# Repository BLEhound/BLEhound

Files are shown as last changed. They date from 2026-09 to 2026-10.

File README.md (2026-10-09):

> **English** | [中文](README.zh-CN.md)

<div align="center">

# BLEhound

**An open, FEM-boosted Bluetooth LE sniffer on nRF54 — with synchronized multi-channel capture.**

Firmware · Wireshark host tools · open hardware

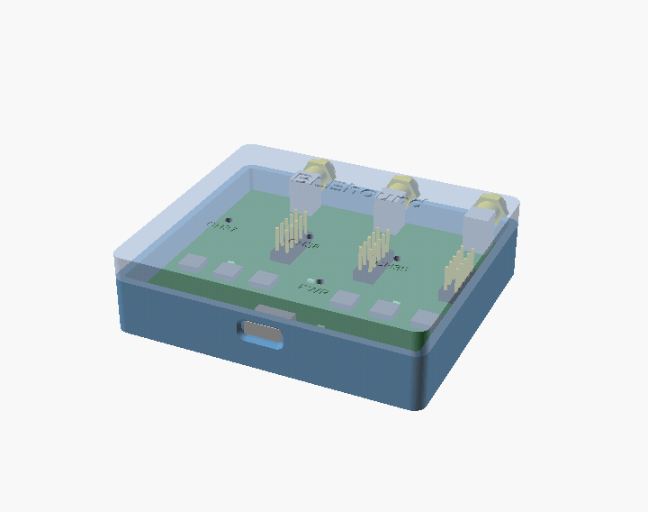
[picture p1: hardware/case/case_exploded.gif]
BLEhound — exploded view of the 3D-printed case: lid, PCB, tray


📖 Full documentation: **https://blehound.github.io**

</div>

---

BLEhound is a from-scratch BLE sniffer. The radio registers are configured by our
own firmware (not Nordic's sniffer firmware), which is what makes deep features
like connection following, encrypted-link capture, and **three-radio synchronized
multi-channel** capture possible. It ships as a complete package: firmware, a
Wireshark `extcap` plugin, and open hardware (JLCEDA Pro source, Gerbers, BOM, 3D-printed
case).

> **Built with AI.** BLEhound's hardware schematic design, and the software (firmware
> and Wireshark host tooling) development and debugging, were done entirely by AI.

## What makes it different

- **Synchronized multi-channel capture (three boards).** A single radio can only
  listen on one channel at a time, so a lone sniffer can miss a `CONNECT_IND` that
  lands on another advertising channel. BLEhound runs three boards, each guarding
  37 / 38 / 39, time-aligned over a hardware SYNC line + inter-board SPI, and merged
  by the host into **one** Wireshark interface. Validated end-to-end on real boards.
- **FEM (nRF21540 PA/LNA).** Better sensitivity and range than bare-radio sniffers.
- **New silicon, current features.** nRF54LM20A. Connection
  following with CSA #1/#2, 1M / 2M / Coded PHY with in-connection PHY updates,
  extended advertising (`AUX_CONNECT_REQ`), and BLE 5.x/6.x link-layer coverage.
- **Doubles as a low-cost BLE RF test bench.** See the docs — the same hardware can
  drive relative/golden-referenced production RF checks.

## Feature support (BLE 4.0 → 6.x)

Most mainstream link-layer features from BLE 4.0 to 6.x are covered, with an honest boundary on what any sniffer can and cannot recover:

| Feature | Status |
|---|---|
| **Advertising & connection following (BLE 4.x)** | |
| Legacy advertising capture (all PDUs) | ✓ |
| `CONNECT_IND` follow + CSA #1 hopping | ✓ |
| Channel-map update (`LL_CHANNEL_MAP_IND`) | ✓ |
| Connection-parameter update (`LL_CONNECTION_UPDATE_IND`) | ✓ |
| Peripheral latency / supervision-timeout loss detection | ✓ |
| Connection termination (`LL_TERMINATE_IND`) | ✓ |
| Encrypted-link follow (ciphertext streamed) | ✓ |
| Inject LTK → decrypt in Wireshark | ✓ |
| Legacy pairing passive crack (TK → STK) | ✓ |
| **PHY & extended advertising (BLE 5.0)** | |
| 1M PHY | ✓ |
| 2M PHY + switch (`LL_PHY_UPDATE_IND`) | ✓ |
| Coded PHY S2/S8 (auto-detect) | ✓ |
| Asymmetric PHY (per-packet within an event) | ✓ |
| CSA #2 hopping | ✓ |
| Extended-advertising AUX chains | ✓ |
| Connection via extended adv (`AUX_CONNECT_REQ`) | ✓ |
| Periodic-advertising sync (`AUX_SYNC_IND`) | ✓ |
| **LE Audio & periodic (BLE 5.1–5.4)** | |
| BIS broadcast isochronous stream | ✓ |
| CIS connected isochronous stream | ✓ |
| CIS termination (`LL_CIS_TERMINATE_IND`) | ◐ |
| Connection subrating (5.3) | ✓ |
| PAwR subevent 0 + response slots (5.4) | ✓ |
| PAwR all subevents captured | ◐ |
| PAST — periodic sync transfer | ◐ |
| **Latest features (BLE 6.0–6.2)** | |
| Frame-space negotiation (6.0) | ✓ |
| Short connection interval, down to 375 µs (6.2) | ✓ |
| Decision-based advertising filtering (6.0) | ✓ |
| Channel Sounding negotiation PDUs streamed | ✓ |
| Dedicated parsing of new 6.3 LL PDUs | ✗ |
| **Encryption & cracking boundary** | |
| Encrypted-link decryption (known LTK) | ✓ |
| LE Secure Connections key cracking | ✗ |
| Plaintext of encrypted LL control PDUs | ✗ |
| Channel Sounding ranging reconstruction | ✗ |
| RPA resolution without an IRK | ✗ |

**Legend:** ✓ verified on real hardware · ◐ code in place, hardware trigger pending · ✗ not supported / infeasible by design

## What it is honest about

- As a **single board**, it is a capable sniffer alongside the excellent
  [Sniffle](https://github.com/nccgroup/Sniffle) and the Nordic nRF Sniffer — its
  edge there is the FEM, newer silicon, and integrated hardware.
- The **multi-board redundancy** pays off on lossy/marginal links; on a clean link a
  single board already captures everything.
- The three-board relay does **not** apply to connections established via extended
  advertising (`AUX_CONNECT_REQ`), and cannot recover encrypted control PDUs (all
  boards miss the same `instant` together).

## Repository layout

| Path | What |
|---|---|
| [`firmware/`](firmware/) | Zephyr / nRF Connect SDK application (C). Build & flash: [firmware/README.md](firmware/README.md) |
| [`host/`](host/) | Wireshark `extcap` plugin + multi-channel aggregator (Python). Usage: [host/README.md](host/README.md) |
| [`hardware/`](hardware/) | Open hardware. **V1** = the fabricated board (JLCEDA Pro source + Gerbers/BOM/case); **V2** = WIP. See [hardware/README.md](hardware/README.md) — note the V1 known issues (single-board works; three-board needs rework). |
| [`tools/`](tools/) | Build / flash / RTT / extcap-install helper scripts |
| [`firmware/blehound/west.yml`](firmware/blehound/west.yml) | west manifest (self-contained; pulls NCS from official Nordic GitHub under firmware/) |

## Quick start

> **Prerequisites:** the nRF Connect SDK **v3.4.0** toolchain (`west`) and **Zephyr SDK 1.0.1**, both on PATH — on Windows install them via nRF Connect for Desktop → Toolchain Manager. A manually-unpacked SDK must be registered once; see [firmware/README.md](firmware/README.md).

```bash
# 1) Firmware — self-contained west workspace lives in firmware/
git clone https://github.com/BLEhound/BLEhound
cd BLEhound
( cd firmware && west init -l blehound && west update && west zephyr-export )
tools/build.sh                        # nRF54LM20A → build/ ; V2=1 for the revised board
tools/flash_jlink.sh                  # flash via J-Link

# 2) Host plugin
tools/install_extcap.sh               # copies the extcap into Wireshark
# then open Wireshark → interface "BLEhound Sniffer"
```

> **Windows** works too — the host tools are cross-platform. Wireshark on Windows
> needs the bundled `.bat` wrapper; see [host/README.md](host/README.md#windows).

Full walkthrough (single-board and three-board): **https://blehound.github.io**

## Licensing

- **Code** (firmware + host): [Apache-2.0](LICENSE)
- **Hardware** (schematic / PCB / Gerbers): [CERN-OHL-S-2.0](hardware/LICENSE)
- Third-party components (Zephyr, nRF Connect SDK, nrfxlib) keep their own licenses.

## Legal / ethical use

BLEhound captures radio traffic and includes legacy-pairing analysis tooling
(equivalent to `crackle`). Only use it on devices you own or are explicitly
authorized to test. Note that **LE Secure Connections (BLE 4.2+) cannot be passively
broken** — no sniffer can. See [host/security/README.md](host/security/README.md).

## Contributing

See [CONTRIBUTING.md](CONTRIBUTING.md). Issues and PRs welcome — the multi-channel
path in particular benefits from testing across more central/peripheral stacks.

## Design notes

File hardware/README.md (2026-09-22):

> **English** | [中文](README.zh-CN.md)

# BLEhound hardware

Open hardware for the BLEhound sniffer: a USB dongle around the **nRF54LM20A** SoC
with an **nRF21540** front-end module (PA/LNA) for improved range and sensitivity.
Licensed under [CERN-OHL-S-2.0](LICENSE).

## Versions

| Folder | What | Fabricate? |
|---|---|---|
| [`v1/`](v1/) | **The only fabricated board so far** (JLCEDA 0908) — Gerbers, BOM, pick-and-place, assembly, JLCEDA Pro source | ⚠️ Has known defects — three-board mode needs rework (single-board OK) |
| [`v2-wip/`](v2-wip/) | Revision that folds V1's fixes into the PCB — **routing not finished** | ❌ Do not fabricate |
| [`case/`](case/) | 3D-printed enclosure (OpenSCAD + STL + sliced 3MF) — version-independent | ✅ Shared by both |

> **Which board actually works?** A plain V1 works for **single-board sniffing only**.
> Its first batch has two pin-level defects that break the **three-board** mode. For
> working three-board hardware, **wait for the V2 revision** (not yet routed) or use a
> **reworked V1** (flying-wire fixes applied, or a modified V1 unit). Details and the
> wiring diagram: [`v1/README.md`](v1/README.md).

## Board at a glance

- **SoC:** nRF54LM20A (BLE 5.x/6.x). The firmware also runs on nRF52840.
- **Front-end:** nRF21540 FEM (PA + LNA) — better link budget than bare-radio sniffers.
- **Host:** USB CDC serial to the PC / Wireshark.
- **Multi-board:** per-board SWD header, plus a SYNC line + inter-board SPI so three
  boards can be time-aligned for synchronized multi-channel capture.

## Why two versions

The first batch (V1, 0908) was fabricated but has two pin-level defects that break the
three-board synchronized mode (single-board sniffing is fine). A plain V1 therefore is
**not** a working three-board board — it needs flying-wire rework on the debug headers
(see [`v1/README.md`](v1/README.md)). **V2** integrates those fixes directly into the
PCB so no rework is needed, but its routing is not yet complete ([`v2-wip/`](v2-wip/),
do not fabricate). **So for working three-board hardware: wait for V2, or use a
reworked V1.**

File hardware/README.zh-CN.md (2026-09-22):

> [English](README.md) | **中文**

# BLEhound 硬件

BLEhound 嗅探器的开源硬件:围绕 **nRF54LM20A** SoC + **nRF21540** 前端模块(PA/LNA,提升距离与灵敏度)的 USB dongle。许可证 [CERN-OHL-S-2.0](LICENSE)。

## 版本

| 文件夹 | 内容 | 可投产? |
|---|---|---|
| [`v1/`](v1/) | **目前唯一投产的板子**(嘉立创 0908)——Gerber、BOM、坐标、装配、嘉立创专业版源 | ⚠️ 有已知缺陷——三机模式需返工(单片可用) |
| [`v2-wip/`](v2-wip/) | 把 V1 修正做进 PCB 的改版——**布线未完成** | ❌ 不要投产 |
| [`case/`](case/) | 3D 打印外壳(OpenSCAD + STL + 切片 3MF)——与版本无关 | ✅ 两版通用 |

> **哪块板真能用?** 原始 V1 只有**单片抓包**可用。首批板有两处引脚级缺陷,会破坏**三机**模式。想要可用的三机硬件,只能**等 V2 改版**(尚未布线),或用**改过的 V1**(按飞线修正返工过、或购入已修改的 V1 单元)。详情与接线图见 [`v1/README.zh-CN.md`](v1/README.zh-CN.md)。

## 板子概览

- **SoC:** nRF54LM20A(BLE 5.x/6.x)。固件也能跑在 nRF52840 上。
- **前端:** nRF21540 FEM(PA + LNA)——链路预算优于裸电台嗅探器。
- **主机:** USB CDC 串口到 PC / Wireshark。
- **多板:** 每片 SWD 排针,外加 SYNC 线 + 片间 SPI,三片可对齐时基做同步多信道捕获。

## 为什么有两个版本

首批(V1,0908)已投产,但有两处引脚级缺陷,会破坏三机同步模式(单片抓包正常)。所以原始 V1 **不是**可用的三机板——需要在调试排针上飞线返工(见 [`v1/README.zh-CN.md`](v1/README.zh-CN.md))。**V2** 把这些修正直接做进 PCB、从而免返工,但布线尚未完成([`v2-wip/`](v2-wip/),不要投产)。**所以想要可用的三机硬件:等 V2,或用改过的 V1。**

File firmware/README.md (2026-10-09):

> **English** | [中文](README.zh-CN.md)

# BLEhound firmware

A from-scratch BLE sniffer built on the nRF Connect SDK (Zephyr). The radio is
driven directly (see `src/radio_nrf54l.c` / `src/radio_nrf52.c`) rather than using
Nordic's sniffer firmware, which is what enables connection following, encrypted
capture, and three-board synchronized multi-channel capture.

- **Targets:** nRF54LM20A (primary, with nRF21540 FEM) and nRF52840.
- **SDK:** nRF Connect SDK **v3.4.0** (pinned in `firmware/blehound/west.yml`).

## Toolchain setup (west)

```bash
# Clone the repo (its path must contain no spaces), then set up the
# self-contained workspace inside firmware/:
git clone https://github.com/BLEhound/BLEhound
cd BLEhound/firmware
west init -l blehound        # firmware/blehound/west.yml is the manifest
west update                  # pulls NCS (nrf/zephyr/...) from official Nordic GitHub, under firmware/
west zephyr-export
```

> **Windows:** get the toolchain from **nRF Connect for Desktop → Toolchain Manager**
> (install NCS v3.4.0) and run these `west` commands in its bundled command prompt —
> they are identical across macOS, Linux, and Windows.

You also need a **Zephyr SDK 1.0.1** (matches NCS v3.4.0). The nRF Connect Toolchain
Manager registers it for you; a **manually-unpacked SDK must be registered once**, with
CMake:

```bash
<sdk-dir>/setup.sh -c      # or: cmake -P <sdk-dir>/cmake/zephyr_sdk_export.cmake
```

or by exporting `ZEPHYR_SDK_INSTALL_DIR=/path/to/zephyr-sdk-1.0.1`. Without this the
build fails with *"Could not find a package configuration file provided by Zephyr-sdk"*.

> **Already have an NCS v3.4.0 workspace?** No need to re-download it — skip `west init`
> / `west update` and point the build wrapper at your existing NCS:
> `NCS_TOPDIR=/path/to/ncs tools/build.sh`.

## Build

```bash
# From firmware/. Board definitions in firmware/blehound/boards/blehound_v{1,2}/ are
# auto-discovered via blehound/zephyr/module.yml, so no -DBOARD_ROOT is needed.
west build -b blehound_v1/nrf54lm20a/cpuapp blehound/projects/blehound --sysbuild
# revised board (V2): -b blehound_v2/nrf54lm20a/cpuapp
```

Or use the convenience wrapper (auto-selects overlays and output dir):

```bash
tools/build.sh                          # nRF54LM20A dongle → build/
```

## Flash

```bash
# Recommended on the nRF54LM20A — pure J-Link (erase + program + reset; auto-unlocks APPROTECT on connect):
tools/flash_jlink.sh
SN=<jlink-serial> tools/flash_jlink.sh   # pick one when several debuggers are attached

# Alternatives via nrfutil — note it may not recognise early nRF54LM20A samples ("Unknown part 0x33"):
west flash
tools/flash.sh                 # auto-detects the J-Link and hex
RECOVER=1 tools/flash.sh       # recover (unlock APPROTECT) first
```

Each board takes the same firmware; for a three-board setup, flash all three and
connect the SWD header of whichever board you are programming.

The build is a sysbuild with three images (MCUboot + USB firmware loader + signed app,
layout in `firmware/blehound/boards/common/blehound_partitions.dtsi`). All outputs are collected with fixed
names in `build/blehound/`: `blehound_mcu_boot.*`, `blehound_loader.*`, `blehound_app.*`
(bin/hex/elf/map each), `blehound_ota.bin` / `blehound_ota.zip` (DFU upload) and
`blehound_merged.hex` (whole chip, what J-Link programs). After that, updates need no J-Link:

```bash
tools/dfu.sh /dev/cu.usbmodemXXXX      # USB DFU of one board (default: build/blehound/blehound_ota.bin)
tools/dfu.sh all                       # every board in turn
tools/verify_flash.sh <J-Link SN>      # byte-compare all three regions on the chip
```

`dfu.sh` sends `HOST_CMD_ENTER_DFU` on the capture port, the board re-enumerates as
"BLEhound Loader" (PID 0x5210) and `nrfutil mcu-manager` uploads the image over SMP.
BLEhound Analyzer has the same flow built in (device panel → "Update firmware…").

**Signing key.** MCUboot only boots images signed with the key whose public half is
compiled into it. `tools/keygen.sh` creates an ed25519 key at
`~/.blehound/keys/blehound_ed25519.pem` (outside the repo, never commit it) and exports
the public key to `firmware/blehound/projects/blehound/keys/blehound_ed25519.pub.pem`; `tools/build.sh` picks the
private key up automatically (or set `BLEHOUND_SIGNING_KEY`). Without a key the build
falls back to MCUboot's public development key and warns: fine for local debugging,
not for release. Changing the key changes MCUboot, so existing boards need one J-Link
programming of `blehound_merged.hex` before they accept images signed with the new key.

## Configuration (Kconfig)

| Option | Meaning |
|---|---|
| `SNIFFER_DEFAULT_TARGET_MAC` | Boot-time target MAC (empty = no filter). Overridden by the host once connected. Format `aa:bb:cc:dd:ee:ff`. |
| `TRI_STRATEGY_*` | Three-board follow strategy — how the boards split work after a `CONNECT_IND`. |

At runtime the host (extcap) controls channel, target MAC, single/multi-target mode,
and multi-channel relay.

## Layout

- `src/radio_*.c` — direct radio driver per SoC
- `src/conn_follower.c` — connection following (CSA #1/#2, PHY update, param update)
- `src/adv_filter.*` — advertising / target-MAC filtering
- `src/sync_line.c`, `src/peer_link.c`, `src/tri_coord.c`, `src/board_role.c` — three-board time sync and coordination
- `src/host_iface.*`, `src/cobs.*` — USB host framing (COBS)
- `src/fem_ctrl.*` — nRF21540 FEM control

> Note on comments: some source comments cite an internal design document by section
> number (e.g. "design §5.1", "scheme §4.5"). That document is not part of this
> release; each module's header comment summarizes the design it needs, so the code is
> self-contained without it.

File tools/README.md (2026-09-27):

> **English** | [中文](README.zh-CN.md)

# tools

Helper scripts for building, flashing, and debugging BLEhound.

| Script | Purpose |
|---|---|
| `build.sh` | Wrapper around `west build` (selects board target + overlays, separate output dirs) |
| `flash.sh` | Flash via modern `nrfutil` over J-Link (handles APPROTECT recovery) |
| `flash_jlink.sh` | Flash via the SEGGER J-Link tools (set `JLINK_DIR` if not at `/opt/SEGGER/JLink`) |
| `jlink_common.sh` | Shared J-Link helpers (sourced by the flash scripts) |
| `recover.sh` | Recover / unlock a locked device (APPROTECT) |
| `install_extcap.sh` | Copy the Wireshark extcap plugin into Wireshark's extcap directory |
| `rtt.sh` | Attach to SEGGER RTT for firmware logs |
| `verify_flash.sh` | Byte-compare the three on-chip regions (MCUboot / loader / app) against the build outputs |
| `keygen.sh` | Create the MCUboot signing key outside the repo (`~/.blehound/keys/`) and export its public half |
| `dfu.sh` | USB DFU without J-Link: enter the loader over the capture port, upload the signed app with `nrfutil mcu-manager`, reset |
| `cdc_test.sh` | Quick USB-CDC sanity check of the sniffer serial port |

Most scripts read overridable environment variables (`NCS_TOPDIR`,
`ZEPHYR_SDK_INSTALL_DIR`, `JLINK_DIR`, `SN`, `DEVICE`, …). Run a script with no
arguments to see its defaults, or read the header comment.

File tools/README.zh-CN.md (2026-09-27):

> [English](README.md) | **中文**

# tools

用于构建、烧录和调试 BLEhound 的辅助脚本。

| 脚本 | 用途 |
|---|---|
| `build.sh` | 对 `west build` 的封装（选择板卡目标 + overlay，输出到各自独立的目录） |
| `flash.sh` | 通过现代 `nrfutil` 经 J-Link 烧录（处理 APPROTECT 恢复） |
| `flash_jlink.sh` | 通过 SEGGER J-Link 工具烧录（若不在 `/opt/SEGGER/JLink`，设置 `JLINK_DIR`） |
| `jlink_common.sh` | 共享的 J-Link 辅助函数（被烧录脚本 source 引用） |
| `recover.sh` | 恢复 / 解锁被锁定的设备（APPROTECT） |
| `install_extcap.sh` | 把 Wireshark extcap 插件复制到 Wireshark 的 extcap 目录 |
| `rtt.sh` | 挂接 SEGGER RTT 以查看固件日志 |
| `verify_flash.sh` | 逐字节比对片上三个分区（MCUboot / 加载器 / 应用）与构建产物 |
| `keygen.sh` | 在仓库外（`~/.blehound/keys/`）生成 MCUboot 签名密钥并导出公钥 |
| `dfu.sh` | 不用 J-Link 的 USB DFU：经抓包口进加载器，用 `nrfutil mcu-manager` 上传签名应用并复位 |
| `cdc_test.sh` | 对嗅探器串口做快速的 USB-CDC 健全性检查 |

多数脚本会读取可覆盖的环境变量（`NCS_TOPDIR`、`ZEPHYR_SDK_INSTALL_DIR`、
`JLINK_DIR`、`SN`、`DEVICE`……）。不带参数运行脚本可查看其默认值，或阅读文件头部的
注释。

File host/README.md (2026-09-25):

> **English** | [中文](README.zh-CN.md)

# BLEhound host tools

Python tools that turn the sniffer's USB stream into Wireshark captures.

- `blehound_extcap.py` — the Wireshark [extcap](https://www.wireshark.org/docs/man-pages/extcap.html)
  plugin. Wireshark calls it to list interfaces/options and to stream packets.
  It opens the sniffer's USB serial port, de-frames (COBS), and writes PCAP
  (`LINKTYPE_BLUETOOTH_LE_LL_WITH_PHDR`) into the Wireshark fifo.
- `blehound_extcap.bat` — Windows wrapper: Wireshark on Windows runs `.exe`/`.bat`
  extcap programs, not `.py` directly, so this launches the plugin via Python.
- `blehound_tri_aggregator.py` — pure-logic module that time-aligns and merges three boards
  into one stream (`SyncClock` + `Aggregator` + `FollowRelay`). Runnable self-test:
  `python3 blehound_tri_aggregator.py --selftest`.
- `wireshark_dfilters` — a set of handy Wireshark display-filter bookmarks.
- `security/` — legacy-pairing analysis and decryption helpers (see its README).

## Requirements

Python 3.9+ (Wireshark uses the system `python3`; on macOS that is 3.9).

```bash
pip install -r requirements.txt      # pyserial (+ cryptography for security/)
```

## Install into Wireshark

```bash
../tools/install_extcap.sh           # copies the extcap into Wireshark's extcap dir
```

Or manually:

```bash
# Wireshark 4.x path (older <4: ~/.config/wireshark/extcap)
mkdir -p ~/.local/lib/wireshark/extcap
cp blehound_extcap.py blehound_tri_aggregator.py ~/.local/lib/wireshark/extcap/
chmod +x ~/.local/lib/wireshark/extcap/blehound_extcap.py
```

Restart Wireshark. The interface list will show **BLEhound Sniffer** (single board)
and **BLEhound Sniffer (3ch aggregated)** (three-board merged).

### Windows

Wireshark on Windows runs `.exe` / `.bat` extcap programs, not `.py` directly, so the
bundled `.bat` wrapper is required:

1. Install Python 3 (tick **Add python.exe to PATH**) and run `pip install pyserial`.
2. Find the extcap folder in Wireshark: **Help → About Wireshark → Folders → Personal
   Extcap path** (usually `%APPDATA%\Wireshark\extcap`).
3. Copy **`blehound_extcap.py`, `blehound_extcap.bat`, and `blehound_tri_aggregator.py`**
   into that folder, then restart Wireshark.

The sniffer's serial ports appear as `COMx`; everything else works the same. If
`python` is not on PATH, edit the `.bat` to use `py -3`. The `tools/*.sh` scripts are
macOS/Linux only (use Git Bash or WSL if you want them on Windows).

The USB identity the firmware advertises: VID `0x1915`, PID `0x520F`,
product string `BLEhound Sniffer`.

## Single board vs three boards

- **Single board:** pick the `BLEhound Sniffer` interface. Set the scan channel or a
  target MAC in the interface options.
- **Three boards:** pick the **BLEhound Sniffer (3ch aggregated)** interface (optionally enable the
  three-board relay). Each board guards 37 / 38 / 39; the aggregator merges and
  de-duplicates into one timeline. See the docs for wiring the SYNC line.

Filter bookmarks: load `wireshark_dfilters` entries to quickly isolate a target
device, connection data, CONNECT_IND, CRC errors, etc. Replace the example address
`aa:bb:cc:dd:ee:ff` with your device's address.

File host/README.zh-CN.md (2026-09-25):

> [English](README.md) | **中文**

# BLEhound 主机工具

一组 Python 工具，把嗅探器的 USB 数据流转换成 Wireshark 抓包。

- `blehound_extcap.py` —— Wireshark 的 [extcap](https://www.wireshark.org/docs/man-pages/extcap.html)
  插件。Wireshark 调用它来列出接口/选项并串流数据包。它会打开嗅探器的 USB 串口，
  解帧（COBS），并把 PCAP（`LINKTYPE_BLUETOOTH_LE_LL_WITH_PHDR`）写入 Wireshark 的
  fifo。
- `blehound_extcap.bat` —— Windows 包装器:Windows 上 Wireshark 只跑 `.exe`/`.bat`,
  不直接跑 `.py`,所以由它用 Python 启动插件。
- `blehound_tri_aggregator.py` —— 纯逻辑模块，把三块板做时间对齐并合并成单一数据流
  （`SyncClock` + `Aggregator` + `FollowRelay`）。可运行自测：
  `python3 blehound_tri_aggregator.py --selftest`。
- `wireshark_dfilters` —— 一组好用的 Wireshark 显示过滤器书签。
- `security/` —— 传统配对（legacy-pairing）分析与解密辅助工具（见其 README）。

## 环境要求

Python 3.9+（Wireshark 使用系统的 `python3`；在 macOS 上即 3.9）。

```bash
pip install -r requirements.txt      # pyserial (+ cryptography for security/)
```

## 安装到 Wireshark

```bash
../tools/install_extcap.sh           # copies the extcap into Wireshark's extcap dir
```

或手动安装：

```bash
# Wireshark 4.x 路径(旧版 <4:~/.config/wireshark/extcap)
mkdir -p ~/.local/lib/wireshark/extcap
cp blehound_extcap.py blehound_tri_aggregator.py ~/.local/lib/wireshark/extcap/
chmod +x ~/.local/lib/wireshark/extcap/blehound_extcap.py
```

重启 Wireshark。接口列表中会出现 **BLEhound Sniffer**（单板）和
**BLEhound Sniffer (3ch aggregated)**(三板合并)。

### Windows

Windows 上 Wireshark 只执行 `.exe` / `.bat` 形式的 extcap,不直接跑 `.py`,所以必须用随附的 `.bat` 包装器:

1. 装 Python 3(勾选 **Add python.exe to PATH**),执行 `pip install pyserial`。
2. 在 Wireshark 里找 extcap 目录:**帮助 → 关于 Wireshark → 文件夹 → Personal Extcap path**(通常是 `%APPDATA%\Wireshark\extcap`)。
3. 把 **`blehound_extcap.py`、`blehound_extcap.bat`、`blehound_tri_aggregator.py`** 三个文件复制进该目录,重启 Wireshark。

嗅探器的串口在 Windows 上显示为 `COMx`,其余用法完全相同。若 `python` 不在 PATH,把 `.bat` 里的 `python` 改成 `py -3`。`tools/*.sh` 脚本仅限 macOS/Linux(Windows 上想用可走 Git Bash / WSL)。

固件对外声明的 USB 标识：VID `0x1915`、PID `0x520F`，产品字符串
`BLEhound Sniffer`。

## 单板 vs 三板

- **单板：** 选择 `BLEhound Sniffer` 接口。在接口选项里设置扫描信道或目标 MAC。
- **三板：** 选择 **BLEhound Sniffer (3ch aggregated)** 接口（可选启用三板接力）。每块板把守
  37 / 38 / 39；聚合器会合并并去重成单一时间线。SYNC 线的接线方式见文档。

过滤器书签：加载 `wireshark_dfilters` 中的条目，可快速隔离出目标设备、连接数据、
CONNECT_IND、CRC 错误等。把示例地址 `aa:bb:cc:dd:ee:ff` 替换为你设备的地址。

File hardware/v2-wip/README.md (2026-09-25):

> **English** | [中文](README.zh-CN.md)

# BLEhound hardware — V2 (work in progress, DO NOT fabricate)

⚠️ **This is an unfinished revision — routing is incomplete. Do not fabricate it.**
V2 is the *fix* for V1's pin-level defects; until it is finished, working three-board
hardware means a **reworked V1** (flying-wire fixes applied) — see
[`../v1/README.md`](../v1/README.md). A plain V1 works for single-board sniffing only.

## What V2 changes (vs V1)

V2 folds V1's fixes directly onto the PCB, so **no flying wires are needed**. For SYNC
and the straps the firmware pin targets are unchanged — V1 reaches them by flying wire,
V2 by native routing. Concretely:

| Signal | V1 (0908, as fabricated) | V2 | Why |
|---|---|---|---|
| **SYNC** in / out | P2.01, one shared net — **no GPIOTE**, edge capture fails; reached by flywire | **P0.04** (in) / **P0.03** (out), routed on the PCB | P2 has no GPIOTE; capture must live on a P0/P1 pin |
| **Role straps** | mis-wired (roles A/C collide, no board guards ch37); reached by flywire | **P1.08** (strap0) / **P1.09** (strap1), routed on the PCB | match `board_role.c`, GPIOTE-capable |
| **Inter-chip SPI** (SPIM00) | SCK=P2.02, MOSI=P2.03, MISO=P2.04 — **not** the SPIM00 fixed pins | SCK=**P2.01**, MOSI=P2.02, MISO=P2.04 (the dedicated SPIM00 pins) | SPIM00's fixed SCK is P2.01, which V1 had used for SYNC; freed once SYNC moved off it |
| **FEM SPI** (nRF21540) | CSN=P0.06, SCK=P0.07, MOSI=P0.08, MISO=P0.09 | CSN=**P1.19**, SCK=**P1.24**, MOSI=**P1.21**, MISO=**P1.20** (all on P1) | datasheet same-port rule + NCS PERI-domain `spi2x` needs CS on P1; also clears the early-sample P0.09 hazard |
| **FEM MODE / ANT_SEL** | MODE=P1.20, ANT_SEL=P1.19 | MODE=**P0.08**, ANT_SEL=**P0.06** (P0.07 freed) | follows the FEM SPI move |
| **FEM TX_EN / RX_EN / PDN** | P1.15 / P1.16 / P1.18 | unchanged | — |
| **USB hub power** (CH334F PSELF) | bus-powered, PSELF (pin 18) floating | **self-powered** (PSELF-SEL net + local 3V3 from U8 AP2112K) | three SoCs + three FEMs exceed the 100 mA bus-power default |

The SYNC/strap **firmware** pins live in `boards/common/blehound_nrf54lm20a_cpuapp_common.dtsi` (shared by both
boards). The SPIM00 and FEM moves are the `boards/blehound_v2/` board definition
(build with `tools/build.sh V2=1`).

**Status: routing NOT complete.** The schematic carries the V2 changes, but the PCB
has not been re-routed for them. The physical layout is still the V1 (0908) layout;
several nets (SYNC, straps, MISO, hub PSELF) are unrouted, and a DRC run reports
shorts / unconnected items where V2 nets were reassigned but the copper was not
redrawn yet.

`kicad/` (`blehound.kicad_*`) is the KiCad project for continuing that routing.

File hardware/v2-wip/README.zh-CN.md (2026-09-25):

> [English](README.md) | **中文**

# BLEhound 硬件 —— V2(在制,请勿投产)

⚠️ **这是未完成的改版,布线不完整,不要拿去投产。** V2 是对 V1 引脚级缺陷的*修正*;在它完成前,可用的三机硬件只能是**改过的 V1**(飞线修正)——见 [`../v1/README.zh-CN.md`](../v1/README.zh-CN.md)。原始 V1 只有单片抓包可用。

## V2 相对 V1 改了什么

V2 把 V1 的修正直接做进 PCB,**从而免飞线**。SYNC 和 strap 的固件目标引脚不变——V1 靠飞线到达,V2 靠 PCB 布线到达。具体:

| 信号 | V1(0908 实产) | V2 | 原因 |
|---|---|---|---|
| **SYNC** 入 / 出 | P2.01,三片共一条网——**无 GPIOTE**,边沿捕获失效;靠飞线 | **P0.04**(入)/ **P0.03**(出),PCB 直连 | P2 没有 GPIOTE,捕获必须落在 P0/P1 |
| **角色 strap** | 接法错(A/C 角色冲突、无一片守 ch37);靠飞线 | **P1.08**(strap0)/ **P1.09**(strap1),PCB 直连 | 对上 `board_role.c`、且有 GPIOTE |
| **片间 SPI**(SPIM00) | SCK=P2.02、MOSI=P2.03、MISO=P2.04——**不是** SPIM00 的固定脚 | SCK=**P2.01**、MOSI=P2.02、MISO=P2.04(SPIM00 专用脚) | SPIM00 固定 SCK 是 P2.01,V1 拿去做了 SYNC;SYNC 挪走后释放出来 |
| **FEM SPI**(nRF21540) | CSN=P0.06、SCK=P0.07、MOSI=P0.08、MISO=P0.09 | CSN=**P1.19**、SCK=**P1.24**、MOSI=**P1.21**、MISO=**P1.20**(全挪到 P1) | 数据手册同口规则 + NCS PERI 域 `spi2x` 要求 CS 在 P1;顺带避开早期样片 P0.09 隐患 |
| **FEM MODE / ANT_SEL** | MODE=P1.20、ANT_SEL=P1.19 | MODE=**P0.08**、ANT_SEL=**P0.06**(P0.07 空出) | 随 FEM SPI 挪位 |
| **FEM TX_EN / RX_EN / PDN** | P1.15 / P1.16 / P1.18 | 不变 | — |
| **USB hub 供电**(CH334F PSELF) | 总线供电,PSELF(18 脚)悬空 | **自供电**(PSELF-SEL 网 + U8 AP2112K 本地 3V3) | 三颗 SoC + 三颗 FEM 超过 100 mA 总线供电默认额度 |

SYNC/strap 的**固件**引脚在 `boards/common/blehound_nrf54lm20a_cpuapp_common.dtsi` 里(两版共用);SPIM00 和 FEM 的挪位是 `boards/blehound_v2/` 板定义(`tools/build.sh V2=1` 构建)。

**状态:布线未完成。** 原理图已带 V2 改动,但 PCB 尚未按其重新布线。物理布局仍是 V1(0908)那版;若干网络(SYNC、strap、MISO、hub PSELF)未布线,跑 DRC 会在"改了网但没重画铜"的地方报短路 / 未连接。

`kicad/`(`blehound.kicad_*`)就是用来继续布线的 KiCad 工程。

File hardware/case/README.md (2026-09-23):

> **English** | [中文](README.zh-CN.md)

# BLEhound case (Design A) · Printing & assembly notes

Outer dimensions 75 × 65 × 19.6 mm, in two parts: tray + lid. Four M3 screws go in
from the bottom; the top face has only 4 LED holes. The parting line sits on the
SMA-KWE thread axis (6.0 mm above the board face), so each of the three SMA holes is
a half-circle split top and bottom; USB-C exits through a 9.8 × 4.0 cutout in the
rear wall.

Exploded assembly of the BLEhound case: lid, PCB, tray

*Exploded view (OpenSCAD render): the lid on top with the embossed logo and LED holes, the PCB in the middle, and the tray with the USB-C cutout below. For a draggable 3D view open [`BLEhound_case_A_3D.html`](BLEhound_case_A_3D.html).*

## 1. Files in this directory

| File | Purpose |
|---|---|
| `blehound_case_P2S_PLA_0.2mm.gcode.3mf` | **Print directly** (Bambu P2S, PLA). Both parts on one plate, ~62 min, ~34 g |
| `blehound_case_P2S_PETG_0.2mm.gcode.3mf` | **Print directly** (Bambu P2S, PETG). ~65 min, ~36 g |
| `blehound_tray.stl` / `blehound_tray.3mf` | Tray model, in print orientation (opening up), 75 × 65 × 13.6 |
| `blehound_lid.stl` / `blehound_lid.3mf` | Lid model, already flipped (top face on the bed, bosses up), 75 × 65 × 12.0 |
| `blehound_case_A.scad` | OpenSCAD parametric source — change parameters and re-export the models |
| `preview_*.png` | OpenSCAD renders: assembled / exploded / tray / lid print orientation |
| `case_exploded.gif` | Exploded-assembly animation shown above |
| `BLEhound_case_A_3D.html` | Offline version of the design page: 3D exploded animation, drawings, review checklist (the 3D view fetches three.js online) |
| `README.md` | This file |

Slicing settings (for both `.gcode.3mf`): P2S 0.4 nozzle, the official "0.20mm
Standard" preset + 3 wall loops, 4 top/bottom layers, 20% infill, no supports,
plate type = textured PEI plate.

## 2. Printing on the Bambu P2S (no PC software needed)

1. Pick a file matching the filament loaded in the machine (PLA or PETG) and copy it
   to the root of the printer's storage card (on the P series that is the microSD on
   the side of the machine; if it has a USB port, use a USB stick instead).
2. Confirm the machine has the **textured PEI plate** installed (the matte black
   one). If you have an AMS, set the matching slot's material to PLA / PETG.
3. Insert the card → touchscreen "Files" → storage card → select the file (it shows
   the thumbnail of both parts) → Next → tick "Bed leveling" → Start.
4. The machine preheats, levels, and starts printing on its own. Glance at the first
   two layers (about 2 minutes) for warping, then you can leave.
5. When it finishes, wait for the bed to drop below 40 °C, then **take the plate out
   and flex it** — the parts pop off by themselves; don't pry them off with a
   scraper.

Prompts you might see:
- "Plate type mismatch": the machine isn't on the textured PEI plate. Swap the
  plate; or tap continue (printing PLA on the smooth Cool Plate needs a glue stick
  first).
- "Filament mismatch": it isn't Bambu PLA Basic. For other-brand PLA just tap
  continue — the temperatures are universal (220 / 55 °C).
- PETG: apply a thin coat of glue stick on the plate first, otherwise PETG sticks
  too hard to the textured plate.
- When printing PLA, open the front door or remove the top glass (a closed chamber
  gets too hot and softens PLA); print PETG with the door closed.

## 3. Hardware

| Item | Spec | Qty |
|---|---|---|
| Flat-head (countersunk) screw | M3 × 12 (14 max) | 4 |
| Heat-set insert | M3 × 4 × 5 (OD 4.6), pilot hole Ø4.0 | 4 |
| Silicone foot pad | Ø8 × 1.5 | 4 |
| SMA nut + spring washer | comes with the connector, optional | 3 |

## 4. Assembly order

1. Press a heat-set insert into the base of each of the lid's 4 bosses: with the
   soldering iron at 220–250 °C, push the insert straight down into the Ø4.0 hole
   until it is flush with the boss face.
2. Without the board in yet, fit the lid onto the tray to check the fit (the lid's
   inner rim reaches 1.5 mm into the tray).
3. Put the PCB into the tray: **tilt the USB end in first** so the USB-C receptacle
   goes into the rear-wall cutout (the receptacle only enters the wall by 0.9 mm, a
   5° tilt is enough), then lower the antenna end so the 3 SMA threads drop into the
   lower half-circles of the front wall.
4. Put the lid on, close up the upper half-circles, and align the bosses with the
   board holes.
5. Flip the whole thing over and drive the 4 M3 × 12 screws in from the bottom
   (don't use screws longer than 14 mm — they'll punch through the lid). Stick on the
   foot pads, positioned inboard of the four corners so they don't sit on the screws.
6. Tighten the SMA nuts (on the outside of the wall, which also clamps the two shells
   together) and fit the antennas. Outside the wall there is 5.0 mm of thread
   available; after the 2.2 nut, 2.8 remains for the antenna's inner nut.

The buttons (BOOT / RESET) and the SWD header are inside the case; when you need
them, undo the 4 screws and lift the lid.

## 5. Parameters you may need to tune after a trial fit (edit the top of `blehound_case_A.scad`)

| Symptom | Parameter | Default | Suggestion |
|---|---|---|---|
| Board won't go in / too loose | `clr` | 0.5 | ±0.2 |
| Lid won't snap in / too loose | `lip_clr` | 0.2 | 0.3 / 0.1 |
| SMA thread sits too high or too low in the half-circle | `sma_axis_z` | 6.0 | after soldering, measure the thread center to the board face with calipers (the Ø7.4 hole leaves ±0.5) |
| USB-C cable won't seat fully | `usb_cut_w` / `usb_cut_h` | 9.8 / 4.0 | +0.5 each |
| Want to fit ANT2 later (J2/J5/J8) | `ant2_slots` | false | true, reprint both parts |
| Want BOOT/RESET pin holes on the top face | `pin_holes` | false | true |

Re-exporting the models and slicing (OpenSCAD 2021.01 and Bambu Studio are already
installed):

```
"C:\Program Files\OpenSCAD\openscad.com" -o blehound_tray.stl -D "part=\"tray\"" blehound_case_A.scad
"C:\Program Files\OpenSCAD\openscad.com" -o blehound_lid.stl  -D "part=\"lid\""  blehound_case_A.scad
```

Slicing: open Bambu Studio → printer P2S 0.4 → import the two STLs (choose No when
asked "as a single object") → process "0.20mm Standard" changed to 3 walls, 4/4
top/bottom, 20% infill, supports off → slice → export the sliced file to the card;
or hit "Print" to send it straight to the machine.

## 6. Basis

- Board: 70 × 60 × 1.6, M3 holes at (4,4) (66,4) (4,47.1) (66,47.1); coordinates from
  the SMT placement file (x = MidX − 113.5, y = MidY + 135).
- SMA-KWE right-angle jack (external thread, internal bore): overall length 14.5,
  thread length 8.5, body 6 × 6 × 9.2, pin 3.5, foot pitch 5.1 × 5.1; the body's
  front face is 1.0 inside the board edge, the thread protrudes 7.5 past the board
  edge, and the axis is 6.0 above the board face.
- USB-C receptacle: 8.94 × 7.35 × 3.26, protruding 1.4 past the board edge
  (measured).
- 2×5 pin header: height 8.5 (the tallest part), inner clearance height 10.0; leave
  4.0 for the pin tails below the board.

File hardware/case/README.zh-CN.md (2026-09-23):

> [English](README.md) | **中文**

# BLEhound 外壳（方案 A）· 打印与装配说明

外形 75 × 65 × 19.6 mm，两件：底壳 + 盖板。4 颗 M3 从底面拧入，顶面只有 4 个 LED 孔。
分模线放在 SMA-KWE 螺纹轴心（板面上 6.0 mm），三个 SMA 孔上下各半圆；USB-C 走后墙 9.8 × 4.0 缺口。

BLEhound 外壳爆炸装配：盖板、PCB、底壳

*爆炸图（OpenSCAD 渲染）：盖板在上（带浮雕 logo 与 LED 孔）、PCB 居中、带 USB-C 缺口的底壳在下。想拖动查看 3D，打开 [`BLEhound_case_A_3D.html`](BLEhound_case_A_3D.html)。*

## 1. 目录里的文件

| 文件 | 用途 |
|---|---|
| `blehound_case_P2S_PLA_0.2mm.gcode.3mf` | **直接打印用**（拓竹 P2S，PLA）。两件同一块板，约 62 min，约 34 g |
| `blehound_case_P2S_PETG_0.2mm.gcode.3mf` | **直接打印用**（拓竹 P2S，PETG）。约 65 min，约 36 g |
| `blehound_tray.stl` / `blehound_tray.3mf` | 底壳模型，打印姿态（开口朝上），75 × 65 × 13.6 |
| `blehound_lid.stl` / `blehound_lid.3mf` | 盖板模型，已翻面（顶面贴床，螺柱朝上），75 × 65 × 12.0 |
| `blehound_case_A.scad` | OpenSCAD 参数化源码，改参数后重出模型 |
| `preview_*.png` | OpenSCAD 渲染图：装配 / 爆炸 / 底壳 / 盖板打印姿态 |
| `case_exploded.gif` | 上方的爆炸装配动画 |
| `BLEhound_case_A_3D.html` | 方案页离线版：3D 拆解动画、图纸、复查清单（3D 需联网取 three.js） |
| `README.zh-CN.md` | 本文件 |

切片参数（两个 `.gcode.3mf` 都是）：P2S 0.4 喷嘴，官方「0.20mm Standard」预设 + 墙 3 圈、顶/底 4 层、填充 20%、无支撑，热床类型 = 纹理 PEI 板。

## 2. 拓竹 P2S 打印步骤（不用开电脑软件）

1. 按机器上装的耗材选一个文件（PLA 或 PETG），拷到打印机的存储卡根目录（P 系列是机身侧面的 microSD 卡；若是 USB 口就拷 U 盘）。
2. 确认机器上装的是**纹理 PEI 板**（黑色磨砂那块）。有 AMS 的话，对应槽的材质设成 PLA / PETG。
3. 插卡 → 触摸屏「文件」→ 存储卡 → 选文件（会显示两件的缩略图）→ 下一步 → 勾「热床调平」→ 开始。
4. 机器自动预热、调平、开打。前两层（约 2 分钟）看一眼没翘边即可离开。
5. 打完等热床降到 40 ℃ 以下，**把板拿下来掰弯**，零件自己弹开，不要用铲子抠。

可能出现的提示：
- 「打印板类型不匹配」：机器上不是纹理 PEI 板。换板；或点继续（光面 Cool Plate 打 PLA 要先涂固体胶）。
- 「耗材不匹配」：不是拓竹 PLA Basic。其它牌子 PLA 点继续即可，温度通用（220 / 55 ℃）。
- PETG：打前在板上薄涂一层固体胶，否则 PETG 在纹理板上粘得过牢。
- PLA 打印时把前门打开或顶盖玻璃拿掉（封闭仓太热会让 PLA 变软）；PETG 关门打。

## 3. 五金

| 项目 | 规格 | 数量 |
|---|---|---|
| 平头（沉头）螺丝 | M3 × 12（最长 14） | 4 |
| 热熔螺母 | M3 × 4 × 5（外径 4.6），底孔 Ø4.0 | 4 |
| 硅胶脚垫 | Ø8 × 1.5 | 4 |
| SMA 螺母 + 弹垫 | 连接器自带，可选 | 3 |

## 4. 装配顺序

1. 盖板 4 个螺柱底部压入热熔螺母：烙铁 220～250 ℃ 顶着螺母垂直压进 Ø4.0 孔，压到与柱面平。
2. 先不放板，把盖板扣到底壳上试一下松紧（盖板内沿伸进底壳 1.5 mm）。
3. PCB 放进底壳：**USB 端先斜着**让 USB-C 座钻进后墙缺口（座只进墙 0.9 mm，倾 5° 就够），再把天线端落下，3 根 SMA 螺纹落进前墙下半圆。
4. 盖上盖板，上半圆合拢，螺柱对准板孔。
5. 整体翻面，4 颗 M3 × 12 从底面拧入（不要拧过 14 mm 长的螺丝，会顶穿盖板）。贴脚垫，脚垫位在四角内侧，不压螺丝。
6. 拧 SMA 螺母（在墙外，同时把上下壳压在一起），装天线。墙外可用螺纹 5.0 mm，螺母 2.2 后剩 2.8 给天线内螺母。

按键（BOOT / RESET）和 SWD 排针在壳内，需要时拧 4 颗螺丝掀盖。

## 5. 试装后可能要调的参数（改 `blehound_case_A.scad` 顶部）

| 现象 | 参数 | 默认 | 建议 |
|---|---|---|---|
| 板子放不进 / 太松 | `clr` | 0.5 | ±0.2 |
| 盖板扣不进 / 太松 | `lip_clr` | 0.2 | 0.3 / 0.1 |
| SMA 螺纹在半圆里偏高或偏低 | `sma_axis_z` | 6.0 | 焊好后卡尺量螺纹中心到板面（孔 Ø7.4 留了 ±0.5） |
| USB-C 线插不到底 | `usb_cut_w` / `usb_cut_h` | 9.8 / 4.0 | 各 +0.5 |
| 以后要贴 ANT2（J2/J5/J8） | `ant2_slots` | false | true，重打两件 |
| 想在顶面开 BOOT/RESET 针孔 | `pin_holes` | false | true |

重出模型与切片（已装 OpenSCAD 2021.01 和 Bambu Studio）：

```
"C:\Program Files\OpenSCAD\openscad.com" -o blehound_tray.stl -D "part=\"tray\"" blehound_case_A.scad
"C:\Program Files\OpenSCAD\openscad.com" -o blehound_lid.stl  -D "part=\"lid\""  blehound_case_A.scad
```

切片：打开 Bambu Studio → 打印机 P2S 0.4 → 导入两个 STL（问「作为整体」选否）→ 工艺「0.20mm Standard」改墙 3、顶底 4/4、填充 20%、支撑关 → 切片 → 导出切片文件到卡；或直接「打印」发送到机器。

## 6. 依据

- 板：70 × 60 × 1.6，M3 孔 (4,4) (66,4) (4,47.1) (66,47.1)，坐标来自 SMT 坐标文件（x = MidX − 113.5，y = MidY + 135）。
- SMA-KWE 外螺内孔弯头：总长 14.5，牙长 8.5，本体 6 × 6 × 9.2，针 3.5，脚距 5.1 × 5.1；本体前脸在板边内 1.0，螺纹伸出板边 7.5，轴心离板面 6.0。
- USB-C 座：8.94 × 7.35 × 3.26，伸出板边 1.4（实测）。
- 排针 2×5：高 8.5（最高件），内腔净高 10.0；板下引脚尾留 4.0。

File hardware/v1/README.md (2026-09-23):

> **English** | [中文](README.zh-CN.md)

# BLEhound hardware — V1 (first fabricated board)

**V1 is the first — and so far only — fabricated batch** of the BLEhound board:
3× **nRF54LM20A** + **nRF21540** FEM, made via JLCEDA / JLCPCB (project date
2026-09-08). Everything in this folder describes that exact fabricated board.

<div align="center">

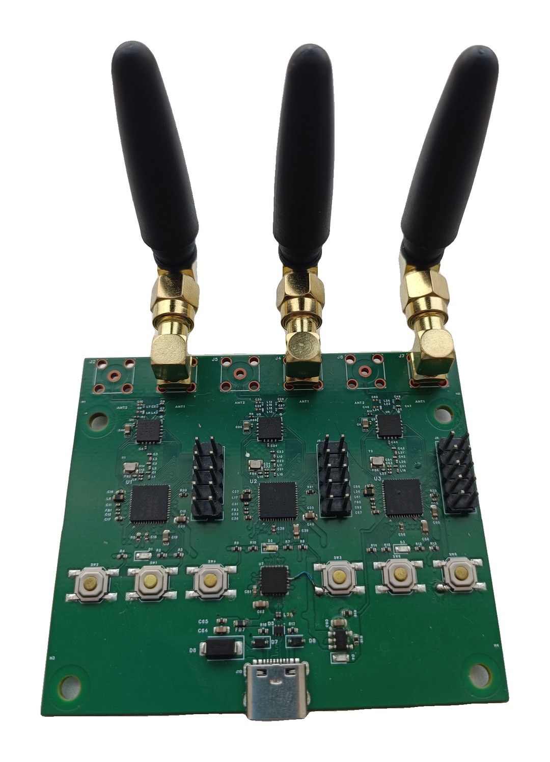
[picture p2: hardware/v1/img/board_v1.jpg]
Assembled BLEhound V1 board — three nRF54LM20A + nRF21540 nodes, three SMA antennas, USB-C


<sub>The fabricated V1 board — three synchronized nodes (channels 37 / 38 / 39), USB-C host.</sub>

</div>

> ⚠️ **The as-fabricated V1 has two known pin-level defects** (see Known issues,
> below) that break **three-board** mode. **Single-board sniffing works.** Do **not**
> expect a plain V1 — or the unfinished [`../v2-wip/`](../v2-wip/) — to work in
> three-board mode out of the box. For working three-board hardware, **wait for the V2
> revision** (routing not yet finished) or use a **reworked V1** (the flying-wire
> fixes below applied, or a modified V1 unit). These files are the design / fab
> reference and the basis for V2.

## Contents

| Path | What |
|---|---|
| `gerbers/` | Fabrication Gerbers (zip), as sent to the PCB house for the V1 board |
| `bom.csv` | Bill of materials (designator / value / footprint / qty) |
| `pick-and-place/` | Component placement file for SMT assembly |
| `assembly.pdf` | Assembly drawing (soldering aid) |
| `jlceda-source/` | The design source (see below) |

### Design source (`jlceda-source/`)

The authoritative V1 design is the JLCEDA (EasyEDA) Pro project:

- `ProPrj_BLEhound_2026-09-08.epro2` — **source of truth**, the fabricated
  V1 project (JLCEDA Pro V3 format). Open it in JLCEDA Pro to view/edit the schematic
  and layout.
- `ProPrj_BLEhound_0908_2026-09-18.epro` — the **same** project in the older
  `.epro` format, which is the one KiCad can import.

> Note: the files were renamed to `BLEhound` for this release. The project's
> **internal** name inside JLCEDA still reads `OpenSnifferDongle` (the pre-rename fab
> name); that internal label can only be changed from within JLCEDA Pro.

## Rebuilding the board

Send `gerbers/` to a PCB fab (JLCPCB, PCBWay, …); provide `bom.csv` and
`pick-and-place/` for assembly. Confirm the RF matching network against the
nRF54LM20A / nRF21540 reference designs before ordering.

## USB hub (CH334F) — strap configuration

The three SoCs' USB lines are combined onto the single USB-C port by **U7, a CH334F
4-port USB 2.0 hub** (WCH). Two of its strap pins must be wired exactly as below on
this board — get either wrong and the hub will not enumerate:

- **Internal oscillator — XI (pin 4) tied to GND.** The CH334F runs on its built-in
  oscillator, so the hub has **no external 12 MHz crystal** (none is in the BOM). To
  select the internal clock, **XI (pin 4) is grounded** and XO (pin 3) is left open.
  (The Y1–Y3 32 MHz crystals in the BOM belong to the nRF54LM20A SoCs, not the hub.)
- **Bus-powered — PSELF (pin 18) must float, never GND.** The dongle draws power from
  the USB-C host (bus-powered). For bus-powered operation **PSELF (pin 18) must be left
  floating; it must not be tied to GND.** Grounding PSELF selects self-powered mode and
  makes the hub misreport its power state to the host, breaking bus-powered
  enumeration. Leave pin 18 unconnected.

## Getting a KiCad version

KiCad's EasyEDA/JLCEDA Pro importer is **GUI-only** (`kicad-cli` cannot do it). To get
a KiCad project of V1:

1. KiCad → **File → Import → Non-KiCad Project → EasyEDA (JLCEDA) Pro Project…**
2. Select `jlceda-source/ProPrj_BLEhound_0908_2026-09-18.epro`.
3. Choose an output directory.

(The `.epro2` is used for offline diff/verification, not for import.)

---

## Known issues — first-batch rework (three-board mode)

The first fabricated batch has **two pin-level design errors** that block the
**three-board synchronized** mode. **Single-board sniffing is unaffected and works out
of the box.** Both are fixable with flying wires on the SWD debug headers — no PCB
respin, no touching SoC pads.

**1. SYNC line on P2.01 — the only port without GPIOTE.**
On the nRF54LM20A, port P2 is the single GPIO port with no GPIOTE instance, so it
cannot do edge capture / interrupts. The SYNC line was routed to P2.01, so the shared
time-base capture never works; firmware logs `sync_line: configure SYNC interrupt
failed: -134` (`-ENOTSUP`). Without SYNC, the three boards cannot be time-aligned.

**2. Strap wiring assigns wrong board roles.**
The per-board strap wiring makes two boards read the same role and the mapping is
offset, so no board ends up guarding advertising channel 37. Channel-guard assignment
is broken.

### Flying-wire rework (11 wires on J3/J6/J9)

**Front, top view** — solder from the top per this diagram:

V1 top-side flying-wire diagram: SYNC pin10 bus + pin8 jumpers, straps on pin4/pin6

**Board flipped, bottom (solder) view** — the same wiring from underneath:

V1 bottom-side flying-wire diagram

<details><summary>2×5 header pin reference (pin1 at bottom-right)</summary>

J3/J6/J9 header pinout

</details>

The needed signals are all brought out to the 2×5 SWD debug headers (J3=U1, J6=U2,
J9=U3) and land on P0/P1 pins that **do** have GPIOTE. Reassignment:

| Header pin | Signal | Ball | Role |
|---|---|---|---|
| 10 | SYNC input (edge capture) | P0.04 | shared time base in |
| 8 | SYNC output (open-drain, no GPIOTE) | P0.03 | shared time base out |
| 6 | strap1 | P1.09 | board-role bit 1 |
| 4 | strap0 | P1.08 | board-role bit 0 |

```
Current firmware pin map — SWD/debug header J3/J6/J9 (PinHeader 2x05, 2.54 mm)

  odd column (SWD)         even column (trace pins -> tri-sync / tri-strap)
  [1]  3V3                 [2]   -
  [3]  GND                 [4]   TD0  strap0   P1.08   (role bit S0)
  [5]  SWCLK               [6]   TD1  strap1   P1.09   (role bit S1)
  [7]  SWDIO               [8]   TD2  SYNC-out  P0.03  (open-drain drive-low, NO GPIOTE)
  [9]  nRESET              [10]  TD3  SYNC-in   P0.04  (edge capture, internal pull-up)

Flying wires (11) — bottom view (board flipped: SMA on top / USB-C on bottom),
so left -> right reads U3(J9) / U2(J6) / U1(J3)

                       U3 / J9 (ch39)      U2 / J6 (ch38)      U1 / J3 (ch37)
  SYNC pin10 bus   ●━━━━━ pin10 ━━━━━━━━━━━━ pin10 ━━━━━━━━━━━━ pin10 ●     2 solid
  SYNC jumper            8┄┄10               8┄┄10               8┄┄10      3 dashed (pin8<->pin10)
  strap0  pin4  ->     3V3  (S0=1)         GND  (S0=0)         GND  (S0=0)
  strap1  pin6  ->     GND  (S1=0)         3V3  (S1=1)         GND  (S1=0)
  ─────────────────────────────────────────────────────────────────────────
  strap code S1S0        01                  10                  00
  board_id / channel     id2 / ch39          id1 / ch38          id0 / ch37

  ● wired pin   ○/open-drain out   ━ solid = SYNC bus   ┄ dashed = pin8-pin10 jumper
  strap: tie pin4/pin6 to pin1 (3V3) = read 1, to pin3 (GND) = read 0
  not fly-wired -> both straps read 1 (code 11, reserved) -> fallback id0/ch37
     (all three guard 37: degenerates to single-board, still captures)
```

- **SYNC bus (2):** `J3.10 ↔ J6.10`, `J6.10 ↔ J9.10`.
- **SYNC jumper (3):** on each board `pin8 ↔ pin10` (adjacent pins).
- **Strap (6):** `code = (strap1<<1)|strap0`; tie to pin3 (GND) = 0, to pin1 (3V3) = 1.
  - J3/U1 (role A, 00, guards 37): `pin4→pin3`, `pin6→pin3`
  - J6/U2 (role B, 10, guards 38): `pin4→pin3`, `pin6→pin1`
  - J9/U3 (role C, 01, guards 39): `pin6→pin3`, `pin4→pin1`

Firmware runs a boot self-test (drive pin8 low, expect pin10 low) and prints a SYNC
loopback-OK line when the jumpers are in place.

> These two fixes (SYNC → P0.04/P0.03, straps → P1.08/P1.09), plus dedicated
> inter-board SPI pins, FEM SPI relocation, and USB-hub self-power, are what the
> **V2 revision** ([`../v2-wip/`](../v2-wip/)) integrates directly into the PCB so no
> flying wires are needed — once its routing is finished.

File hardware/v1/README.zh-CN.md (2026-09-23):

> [English](README.md) | **中文**

# BLEhound 硬件 —— V1(首批投产板)

**V1 是首批、也是目前唯一投产的板子:** BLEhound 板,3× **nRF54LM20A** + **nRF21540** FEM,经嘉立创 EDA / JLCPCB 投产(工程日期 2026-09-08)。本文件夹里的一切都对应这块实产板。

<div align="center">

BLEhound V1 装配实物板 —— 三组 nRF54LM20A + nRF21540 节点、三根 SMA 天线、USB-C

<sub>已投产的 V1 实物板 —— 三个同步节点(信道 37 / 38 / 39),USB-C 主机接口。</sub>

</div>

> ⚠️ **原始 V1 有两处已知引脚级缺陷**(见下方「已知问题」),会破坏**三机**模式。**单片抓包正常。** 不要指望原始 V1——或未完成的 [`../v2-wip/`](../v2-wip/)——开箱就能跑三机。想要可用的三机硬件,只能**等 V2 改版**(布线尚未完成),或用**改过的 V1**(按下方飞线修正返工过、或购入已修改的 V1 单元)。这些文件是设计 / 生产参考,也是 V2 的基础。

## 内容

| 路径 | 说明 |
|---|---|
| `gerbers/` | 制造 Gerber(zip),即当初交给 PCB 厂做 V1 板用的那份 |
| `bom.csv` | 物料清单(位号 / 值 / 封装 / 数量) |
| `pick-and-place/` | SMT 贴片坐标文件 |
| `assembly.pdf` | 装配图(焊接辅助) |
| `jlceda-source/` | 设计源(见下) |

### 设计源(`jlceda-source/`)

V1 的权威设计是嘉立创 EDA(EasyEDA)专业版工程:

- `ProPrj_BLEhound_2026-09-08.epro2` —— **真理源**,实产 V1 工程(嘉立创专业版 V3 格式)。在嘉立创专业版里打开可看/改原理图与 PCB。
- `ProPrj_BLEhound_0908_2026-09-18.epro` —— **同一**工程的旧版 `.epro` 格式,这是 KiCad 能导入的那种。

> 注:本次发布已把文件重命名为 `BLEhound`。工程在 JLCEDA 里的**内部**名称仍是 `OpenSnifferDongle`(改名前的投产名),该内部名称只能在嘉立创专业版里改。

## 复制这块板

把 `gerbers/` 发给 PCB 厂(JLCPCB、PCBWay 等);贴片提供 `bom.csv` 与 `pick-and-place/`。下单前对照 nRF54LM20A / nRF21540 参考设计核对射频匹配网络。

## USB hub(CH334F)—— strap 配置

三颗 SoC 的 USB 通过 **U7(CH334F,4 口 USB 2.0 集线器,沁恒 WCH)** 汇到同一个 USB-C 口。这颗芯片有两个配置脚在本板上必须按下面接——接错任一个 hub 都无法枚举:

- **内部晶振 —— XI(4 脚)接地。** CH334F 用片内振荡器,所以 hub **不外挂 12 MHz 晶振**(BOM 里也没有)。要选内部时钟,就把 **XI(4 脚)接地**、XO(3 脚)悬空。(BOM 里的 Y1–Y3 32 MHz 晶振是给 nRF54LM20A 的,不是给 hub 的。)
- **USB 总线供电 —— PSELF(18 脚)必须悬空,绝不能接地。** 本 dongle 由 USB-C 主机供电(总线供电)。总线供电模式下 **PSELF(18 脚)必须悬空,不能接 GND。** 把 PSELF 接地会让 hub 进入自供电模式、并向主机误报供电状态,导致总线供电下枚举失败。18 脚保持不连接。

## 拿到 KiCad 版本

KiCad 的 EasyEDA / 嘉立创专业版导入器是 **GUI 专属**(`kicad-cli` 做不了)。要得到 V1 的 KiCad 工程:

1. KiCad → **文件 → 导入 → 非 KiCad 工程 → EasyEDA (JLCEDA) Pro Project…**
2. 选 `jlceda-source/ProPrj_BLEhound_0908_2026-09-18.epro`。
3. 指定一个输出目录。

(`.epro2` 用于离线比对/核验,不用于导入。)

---

## 已知问题 —— 首批板返工(仅影响三机模式)

首批投产板有**两处引脚级设计错误**,卡住**三机同步**模式。**单片抓包不受影响,开箱即用。** 两处都能用调试排针飞线解决——不重打样、不碰 SoC 焊盘。

**1. SYNC 落在 P2.01 —— 全芯片唯一没有 GPIOTE 的口。**
nRF54LM20A 上 P2 是唯一没有 GPIOTE 实例的 GPIO 口,做不了边沿捕获/中断。SYNC 线偏偏走到了 P2.01,于是共享时基捕获从来不工作;固件报 `sync_line: 配置 SYNC 中断失败: -134`(`-ENOTSUP`)。没有 SYNC,三片无法对齐时基。

**2. strap 接法把板角色分错。**
各片 strap 接法让两片读到同一角色、且整体映射错位,导致没有一片守广播信道 37,信道分工失效。

### 飞线返工(J3/J6/J9 共 11 根)

**正面俯视** —— 从顶面焊照此图:

V1 顶面飞线图:SYNC pin10 总线 + pin8 跳线、strap pin4/pin6

**翻到底面(焊接面)** —— 同样的接线从底面看:

V1 底面焊线图

<details><summary>2×5 排针针脚参考(pin1 在右下角)</summary>

J3/J6/J9 排针针脚

</details>

要用的信号都引到了 2×5 SWD 调试排针(J3=U1、J6=U2、J9=U3),且落在**有** GPIOTE 的 P0/P1 脚上。重新分配:

| 排针 pin | 信号 | 球位 | 用途 |
|---|---|---|---|
| 10 | SYNC 输入(边沿捕获) | P0.04 | 共享时基 入 |
| 8 | SYNC 输出(开漏,不挂 GPIOTE) | P0.03 | 共享时基 出 |
| 6 | strap1 | P1.09 | 板角色 bit 1 |
| 4 | strap0 | P1.08 | 板角色 bit 0 |

```
当前固件引脚图 —— SWD/调试排针 J3/J6/J9(PinHeader 2x05, 2.54 mm)

  奇数列(SWD)             偶数列(trace 脚 -> tri-sync / tri-strap)
  [1]  3V3                 [2]   -
  [3]  GND                 [4]   TD0  strap0   P1.08   (角色位 S0)
  [5]  SWCLK               [6]   TD1  strap1   P1.09   (角色位 S1)
  [7]  SWDIO               [8]   TD2  SYNC-out  P0.03  (开漏驱低,不挂 GPIOTE)
  [9]  nRESET              [10]  TD3  SYNC-in   P0.04  (边沿捕获,内部上拉)

飞线(11 根)—— 底面视图(板翻到底面朝上:SMA 在上 / USB-C 在下),
所以左 -> 右 = U3(J9) / U2(J6) / U1(J3)

                       U3 / J9(守39)       U2 / J6(守38)       U1 / J3(守37)
  SYNC pin10 总线  ●━━━━━ pin10 ━━━━━━━━━━━━ pin10 ━━━━━━━━━━━━ pin10 ●     实线 2 根
  SYNC 跳线              8┄┄10               8┄┄10               8┄┄10      虚线 3 根(pin8<->pin10)
  strap0  pin4  ->     3V3 (S0=1)          GND (S0=0)          GND (S0=0)
  strap1  pin6  ->     GND (S1=0)          3V3 (S1=1)          GND (S1=0)
  ─────────────────────────────────────────────────────────────────────────
  strap 码 S1S0          01                  10                  00
  board_id / 守信道      id2 / 守39          id1 / 守38          id0 / 守37

  ● 已接脚   ○ 开漏输出   ━ 实线=SYNC 总线   ┄ 虚线=pin8-pin10 跳线
  strap:pin4/pin6 接 pin1(3V3)读 1,接 pin3(GND)读 0
  未飞线 -> 两 strap 都读 1(码 11,保留)-> 回落 id0/守37
     (三片都守 37:退化为单片,仍能抓包)
```

- **SYNC 总线(2 根):** `J3.10 ↔ J6.10`、`J6.10 ↔ J9.10`。
- **SYNC 跳线(3 根):** 每片 `pin8 ↔ pin10`(相邻两脚)。
- **strap(6 根):** `code = (strap1<<1)|strap0`;接 pin3(GND)读 0,接 pin1(3V3)读 1。
  - J3/U1(角色 A,00,守 37):`pin4→pin3`、`pin6→pin3`
  - J6/U2(角色 B,10,守 38):`pin4→pin3`、`pin6→pin1`
  - J9/U3(角色 C,01,守 39):`pin6→pin3`、`pin4→pin1`

固件开机会做回环自检(驱低 pin8,pin10 应读到低),跳线到位时打印 SYNC 回环通过。

> 这两处修正(SYNC → P0.04/P0.03、strap → P1.08/P1.09),加上片间 SPI 改到专用脚、FEM SPI 挪位、USB hub 自供电,正是 **V2 改版**([`../v2-wip/`](../v2-wip/))要直接做进 PCB、从而免飞线的内容——等它布线完成后。

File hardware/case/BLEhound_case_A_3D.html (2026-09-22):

BLEhound · 3D-printed case · Variant A revised

# Tray + lid, screws enter from the bottom, only LEDs on the top face

Changed per your three requirements: M3 countersunk from the bottom, only 4 LED holes on the top, inner cavity sized for the soldered pin-header height. During review I found 7 more things to fix; all are now in the drawings and the OpenSCAD source.

## Recomputed against the connector spec

SMA

SMA-KWE external-thread inner-hole right-angle jack: overall 14.5, thread 8.5, body 6 × 6 × 9.2, pin 3.5, pin pitch 5.1 × 5.1 (matches the board’s 5.15 pads).From the drawing: the Ø6.35 thread top is flush with the body top, soaxis is 9.2 − 3.2 = 6.0 above the board face, not the 3.2 I earlier estimated for an ordinary right-angle jack. Body front face is 0.4 beyond the front pin row → 1.0 inside the board edge; thread extends past the board edge 7.5. Fix:move the parting line from 7.0 to 6.0 (= axis), the three Ø7.4 holes are half-circle top and bottom, the board drops in flat and closes when the lid is on, sturdier than a U-slot; the 9.2-tall body leaves 0.8 in the 10.0 cavity.

Thread

Usable thread past the wall 5.0:8.5 − 1.0 inside board − 0.5 clearance − 2.0 wall. The nut that comes with the jack is 2.2 thick; after tightening, 2.8 is left for the antenna’s inner nut (about 4 turns, enough). No nut also works — the hole already clamps the thread top and bottom and the screw locks the board; the nut only stiffens the wall.

USB-C

Cutout reduced from 13 × 7 to 9.8 × 4.0.You measured the receptacle overhang past the board edge as 1.4, so the receptacle front face is only 2.5 − 1.4 = 1.1; the plug’s metal shell (8.3 × 2.6, length 6.5) fully enters the receptacle, the overmold stays outside the wall, and the cutout only needs to clear the receptacle body (8.94 × 3.26 + 0.4 per side). Add a 0.8 45° lead-in chamfer on the outside. There is still 2.4 of wall from the cutout top to the parting line — no longer a thin bridge.

Antenna

2.4G stub 5 cm right-angle antenna (SMA inner-thread inner-pin): the elbow in any direction clears the neighboring jack — the three holes are 23.2 apart and the elbow body is about 9 in diameter, just enough.

## Review conclusion: 10 changes

The first three are your requirements; the rest are issues found and resolved while checking the original Variant A item by item.

Requirement

Screws moved to the bottom.M3×12 flat-head countersunk from the tray bottom, through the Ø8 bosses and the PCB mounting holes, into M3 heat-set inserts at the lower end of the lid bosses. The top is clean; the foot pads are moved inward, clear of the screws.

Requirement

Only LEDs on the top face.4 Ø2.2 holes (CH37/38/39/PWR) + engraved text. Buttons and SWD require opening the lid; the source keeps a pin_holes parameter, off by default.

Requirement

Leave room for the soldered pin headers.8.5 above the pin header + 1.5 margin → cavity clear height 10.0; pin tails + solder joints below the board → standoff 4.0. Total height 19.6.

Issue 1

The SMA hole cannot be a full circle in the tray wall.With the SMA-KWE axis at 6.0, the Ø7.4 hole spans 2.3–9.7 and necessarily crosses the parting line. So the parting line is placed on the axis: lower half in the tray, upper half in the lid; the board drops in flat and closes on assembly.

Issue 2

The USB-C receptacle overhangs the board edge by 1.4 and enters the rear wall by 0.9; the board cannot drop straight into a closed cutout.Assembly changes to: insert the USB end into the cutout at an angle first (only 0.9 into the wall, a 5° tilt is enough), then lower the antenna end so the SMA thread drops into the lower half-circle. To avoid the tilt, open the cutout down to the parting line (it becomes 9.8 × 6.4).

Issue 3

An M3 countersink in the 2 mm floor leaves only 0.3 mm of material.The countersink sits directly under the Ø8 boss, so the actual material is floor 2 + boss 4; a 1.5 countersink is fine. But the foot pads can no longer sit over the screws, so they move to (12,10)(58,10)(12,41)(58,41).

Issue 4

A Ø7 boss with an M3 heat-set insert (OD 4.6) has only 1.2 wall.Boss changed to Ø8. Checked components within 7.5 mm of the four holes against the coordinate file: the nearest is C46 (0402) beside H1, 1.3 mm from the boss edge; the other three holes are clear.

Issue 5

The LED is 9 mm below the lid; the Ø2 hole is visible but dim, and the three channels bleed light.Add a Ø4.6 light pipe under the lid, down to z=2.5 (LED height 0.7, adjacent button height 1.5, both clear). Brighter option: change the hole to Ø1.85 and insert a 12 mm clear 1.75 filament as a light guide.

Issue 6

Board corners vs. cavity fillets.The PCB has square corners; cavity corner R1 with 0.5 per-side clearance, checked non-interfering (0.3 at the corner). The three ANT2 reserved positions are not slotted by default; to populate them set ant2_slots=true and reprint the tray.

Issue 7

Screw length.Floor 2 + standoff 4 + board 1.6 = 7.6; M3×12 goes 4.4 mm into the insert (insert length 5, hole depth 6.5 for the screw tip). M3×14 also works, don’t exceed 14.

## 3D view and exploded animation

Drag to rotate, scroll to zoom, right-drag to pan. “▶ Explode” plays the disassembly animation (screws back out → lid lifts → PCB lifts off, SMA nuts back out); the slider can stop anywhere manually. “Section” cuts at x = 45, the same position as the section drawing below.

Isometric Top Antenna end USB end

Auto-rotate X-ray shell Section PCB Dimensions

▶ Explode Explode

Explode 0% · Assembled

### Disassembly order (synced with the animation)

1. AssembledTray, PCB and lid clamped by 4 M3; SMA nuts locked outside the front wall
2. ① Back out the 4 M3×12Back out from the bottom countersinks, through the tray bosses, PCB mounting holes, and the heat-set inserts in the lid bosses
3. ② Lift the lidThe 4 Ø8 bosses leave the PCB top; the 4 LED light pipes leave with the lid; the skirt clears the tray
4. ③ Lift the PCB, back out the SMA nutsReassembly is the reverse: seat the board first (USB end angled into the cutout, antenna end lowered into the half-circle), close the lid over the upper half-circle, flip and drive the screws, then fit the nuts

The model is generated from the same parameters as blehound_case_A.scad : 75 × 65 × 19.6, wall 2.0, boss Ø8, parting line 6.0 through the SMA axis, SMA hole Ø7.4, USB cutout 9.8 × 4.0.

## Revised drawings

### Key parameters (mm)

Outer | 75 × 65 × 19.6
Wall / floor / lid | 2.0 / 2.0 / 2.0
PCB clearance | 0.5 (cavity 71 × 61)
Standoff height (below board) | 4.0
Cavity clear height (above board) | 10.0
Parting line | z = 6.0 (= SMA axis; board top face is 0)
Boss | Ø8, 4 top and 4 bottom
SMA hole | Ø7.4 ×3, axis z = 6.0, half-circle top and bottom
USB-C cutout | 9.8 × 4.0, z -0.37–3.63, corner 1.3, outer chamfer 0.8
LED hole / light pipe | Ø2.2 / Ø4.6, pipe bottom z = 2.5
Lid inner lip | height 1.5, thickness 1.2, clearance 0.2

## Hardware BOM and assembly

### Hardware

- M3×12 flat-head (countersunk) screw ×4, stainless or black zinc
- M3 heat-set insert ×4, M3×4×5 (OD 4.6), pilot hole Ø4.0 (some batches 4.2)
- Ø8 × 1.5 silicone foot pad ×4
- SMA nut (2.2 thick) + spring washer: comes with the connector, optional

### Assembly order

- Press the heat-set inserts into the lower end of the 4 lid bosses (iron 220 ℃, flush with the boss face)
- Place the PCB into the tray: USB end first, angling the USB-C receptacle into the cutout, then lower the antenna end so the 3 SMA threads drop into the lower half-circle
- Close the lid, mate the upper half-circle, seat the inner lip into the tray, align the bosses with the board holes
- Flip the whole thing, drive the 4 M3×12 from the bottom; stick on the foot pads
- Fit the SMA nuts (lock outside the wall, pressing the two shells together) and the antenna

### Printing

- Tray: opening up, no supports. USB cutout bridges 9.8 mm; SMA half-circle slots open upward
- Lid: in the source part="lid" is pre-flipped, top face on the bed; bosses and light pipes point up; the three half-circles on the skirt open upward, no supports
- PETG or PLA, layer 0.2, 3 walls, 4 top/bottom layers, 20% infill
- Bosses and light pipes with diameter ≥ 4.6 print stably; the countersink is a 90° cone, no supports needed

## Files (rendered with OpenSCAD 2021.01)

All under hardware/case/:

File | Contents | Size / notes
blehound_tray.stl / .3mf | Tray, print orientation (opening up) | 75 × 65 × 13.6, 5460 faces, single solid
blehound_lid.stl / .3mf | Lid, pre-flipped (top face on the bed; bosses, light pipes, skirt up) | 75 × 65 × 12.0, 18996 faces, single solid
blehound_case_A.scad | Parametric source; edit the top parameter block and re-export | Coordinates come straight from the SMT coordinate file
preview_*.png | OpenSCAD renders: assembly, exploded, tray, lid print orientation | For checking
BLEhound_case_A_3D.html | Offline version of this page (with 3D animation, fetches three.js online)

"C:\Program Files\OpenSCAD\openscad.com" -o blehound_tray.stl -D "part=\"tray\"" blehound_case_A.scad
"C:\Program Files\OpenSCAD\openscad.com" -o blehound_lid.stl  -D "part=\"lid\""  blehound_case_A.scad

Slicing: layer 0.2, 3 walls, 4 top/bottom layers, 20% infill, PETG or PLA, neither part needs supports (USB cutout bridges 9.8 mm; the half-circles on the lid skirt open upward). Print once, test-fit with the board, then decide whether to nudge clr(0.5) or lip_clr(0.2) a notch.

## Numbers still for you to check

1. SMA body height.Measured 9.2 from the spec drawing (axis 6.0); after soldering, caliper the thread center to the board face — 6.3 is also fine (the Ø7.4 hole leaves ±0.5).
2. USB-C receptacle overhang 1.4 changed as you said.Any actual value between 1.0–1.8 works; the cutout needs no further change.
3. Pin-header type.Computed for a standard 2.54 header: top 6 + body 2.5 = 8.5, tail 3.0 below (1.4 exposed below the board + solder). If you use a taller header, change inner_h.

## Appendix: board interface map

## Appendix: early alternatives (B sandwich / C slide-sleeve / D upright dock)

Dropped, kept for comparison. C’s retention chain is in the previous round of discussion; D can still be an accessory to the final A.

B · Sandwich

C · Slide-sleeve

D · Upright dock (pairs with the final A)

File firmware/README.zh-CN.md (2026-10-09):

> [English](README.md) | **中文**

# BLEhound 固件

一款基于 nRF Connect SDK（Zephyr）从零构建的 BLE 嗅探器。射频由固件直接驱动
（见 `src/radio_nrf54l.c` / `src/radio_nrf52.c`），而非使用 Nordic 的嗅探器固件，
正是这一点让连接跟随（connection following）、加密抓包（encrypted capture）以及
三板同步多信道抓包成为可能。

- **目标芯片：** nRF54LM20A（主用，搭配 nRF21540 FEM）与 nRF52840。
- **SDK：** nRF Connect SDK **v3.4.0**（在`firmware/blehound/west.yml` 中锁定）。

## 工具链搭建（west）

```bash
# 克隆仓库（路径不要含空格），在 firmware/ 内搭建自包含工作区：
git clone https://github.com/BLEhound/BLEhound
cd BLEhound/firmware
west init -l blehound        # firmware/blehound/west.yml 是 manifest
west update                  # 从 Nordic 官方 GitHub 拉取 NCS(nrf/zephyr/...)到 firmware/ 下
west zephyr-export
```

> **Windows:** 用 **nRF Connect for Desktop → Toolchain Manager** 装工具链(选 NCS v3.4.0),在它自带的命令行里跑上面这些 `west` 命令——命令在 macOS / Linux / Windows 上完全一致。

你还需要一个 **Zephyr SDK 1.0.1**（配 NCS v3.4.0）。nRF Connect Toolchain Manager 会自动
注册它；**手动解压的 SDK 必须先注册一次**，用 CMake：

```bash
<sdk目录>/setup.sh -c      # 或: cmake -P <sdk目录>/cmake/zephyr_sdk_export.cmake
```

或导出 `ZEPHYR_SDK_INSTALL_DIR=/path/to/zephyr-sdk-1.0.1`。否则构建会报
*"Could not find a package configuration file provided by Zephyr-sdk"*。

> **已经有 NCS v3.4.0 工作区?** 不必重新下载 —— 跳过 `west init` / `west update`,直接把构建脚本指向现成的 NCS:`NCS_TOPDIR=/path/to/ncs tools/build.sh`。

## 构建

```bash
# 在 firmware/ 下执行。板定义在 firmware/blehound/boards/blehound_v{1,2}/,
# 经 blehound/zephyr/module.yml 自动发现,无需 -DBOARD_ROOT。
west build -b blehound_v1/nrf54lm20a/cpuapp blehound/projects/blehound --sysbuild
# 改版板(V2): -b blehound_v2/nrf54lm20a/cpuapp
```

或使用便捷封装脚本（自动选择 overlay 和输出目录）：

```bash
tools/build.sh                          # nRF54LM20A dongle → build/
```

## 烧录

```bash
# nRF54LM20A 推荐：纯 J-Link（擦除+烧录+复位；connect 时自动解 APPROTECT）：
tools/flash_jlink.sh
SN=<jlink序列号> tools/flash_jlink.sh    # 多块调试器时指定一块

# 备选（走 nrfutil）—— 注意 nrfutil 可能不认早期 nRF54LM20A 样片（"Unknown part 0x33"）：
west flash
tools/flash.sh                 # 自动探测 J-Link 和 hex
RECOVER=1 tools/flash.sh       # 先 recover（解 APPROTECT）再烧
```

每块板烧录的都是同一份固件；三板方案下，把三块都烧上，并连接你正在编程的那块板的
SWD 排针。

构建是 sysbuild 三镜像（MCUboot + USB 固件加载器 + 签名应用，布局见
`firmware/blehound/boards/common/blehound_partitions.dtsi`）。产物统一以固定名字收在 `build/blehound/`：
`blehound_mcu_boot.*`、`blehound_loader.*`、`blehound_app.*`（各有 bin/hex/elf/map）、
`blehound_ota.bin` / `blehound_ota.zip`（DFU 上传用）和 `blehound_merged.hex`（整片，J-Link 烧这个）。
之后升级不再需要 J-Link：

```bash
tools/dfu.sh /dev/cu.usbmodemXXXX      # 对一块板做 USB DFU（默认用 build/blehound/blehound_ota.bin）
tools/dfu.sh all                       # 依次升级每块板
tools/verify_flash.sh <J-Link SN>      # 逐字节比对片上三个分区
```

`dfu.sh` 往抓包口发 `HOST_CMD_ENTER_DFU`，板子重新枚举为 "BLEhound Loader"（PID 0x5210），
再由 `nrfutil mcu-manager` 经 SMP 上传镜像。BLEhound Analyzer 内置了同样的流程
（设备面板 →「升级固件…」）。

**签名密钥。** MCUboot 只启动用「公钥已编进它」的那把 key 签的镜像。`tools/keygen.sh`
在仓库外生成 ed25519 密钥 `~/.blehound/keys/blehound_ed25519.pem`（切勿入库），并把公钥导出到
`firmware/blehound/projects/blehound/keys/blehound_ed25519.pub.pem`；`tools/build.sh` 会自动使用私钥（也可用
`BLEHOUND_SIGNING_KEY` 指定）。没有 key 时回落到 MCUboot 公开的开发 key 并告警：本地调试可以，
不能发布。换 key 会改变 MCUboot，老板子要先用 J-Link 重烧一次 `blehound_merged.hex` 才认新签名。

## 配置（Kconfig）

| 选项 | 含义 |
|---|---|
| `SNIFFER_DEFAULT_TARGET_MAC` | 启动时的目标 MAC（留空 = 不过滤）。一旦连上主机即被其覆盖。格式为 `aa:bb:cc:dd:ee:ff`。 |
| `TRI_STRATEGY_*` | 三板跟随策略 —— 收到 `CONNECT_IND` 后各板如何分工。 |

运行时，由主机（extcap）控制信道、目标 MAC、单/多目标模式以及多信道接力。

## 代码结构

- `src/radio_*.c` —— 各 SoC 的直接射频驱动
- `src/conn_follower.c` —— 连接跟随（CSA #1/#2、PHY 更新、参数更新）
- `src/adv_filter.*` —— 广播 / 目标 MAC 过滤
- `src/sync_line.c`、`src/peer_link.c`、`src/tri_coord.c`、`src/board_role.c` —— 三板时间同步与协调
- `src/host_iface.*`、`src/cobs.*` —— USB 主机成帧（COBS）
- `src/fem_ctrl.*` —— nRF21540 FEM 控制

> 关于注释：部分源码注释以章节号引用了一份内部设计文档（如「design §5.1」「scheme §4.5」）。该文档不在本次发布内；每个模块的头部注释已概括其所需设计，因此不依赖该文档也能读懂代码。

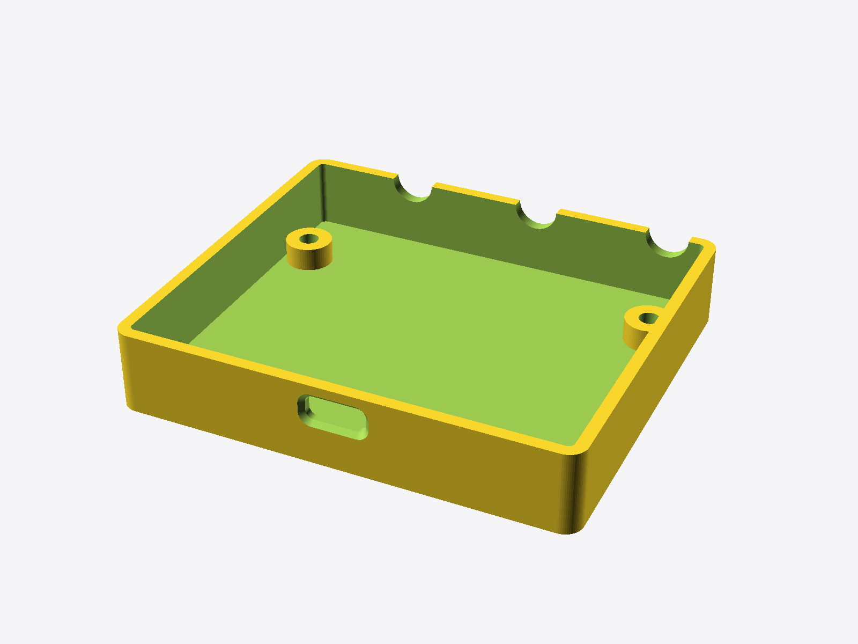
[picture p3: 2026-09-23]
hardware/case/preview_tray.png

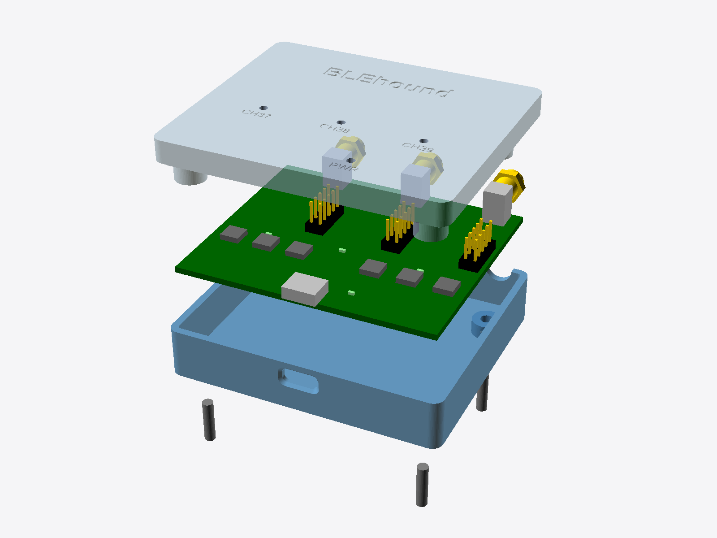
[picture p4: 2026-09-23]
hardware/case/preview_exploded.png

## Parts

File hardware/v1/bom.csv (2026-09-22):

Designator | Value | Footprint | Qty | DNP
C1,C21,C41 | 1.2pF | nRF54LM20A:DK_C_0201_0603Metric | 3
C2,C22,C42 | 1.5pF | nRF54LM20A:DK_C_0201_0603Metric | 3
C3,C23,C43 | 0.3pF | nRF54LM20A:DK_C_0201_0603Metric | 3
C4,C8,C13,C24,C28,C33,C44,C48,C53 | 1.0pF | nRF54LM20A:DK_C_0201_0603Metric | 9
C5,C25,C45 | 100nF | nRF54LM20A:DK_C_0201_0603Metric | 3
C6,C26,C46 | 10uF | nRF54LM20A:DK_C_0402_1005Metric | 3
C7,C27,C47 | 2.0pF | nRF54LM20A:DK_C_0201_0603Metric | 3
C9,C29,C49 | 2.0pF | nRF54LM20A:DK_C_0201_0603Metric | 3 | DNP
C10,C30,C50 | 1.0pF | nRF54LM20A:DK_C_0201_0603Metric | 3 | DNP
C11,C31,C51 | 4.7uF | nRF54LM20A:DK_C_0201_0603Metric | 3
C12,C14,C15,C32,C34,C35,C52,C54,C55 | 2.2uF | nRF54LM20A:DK_C_0201_0603Metric | 9
C16-C18,C36-C38,C56-C58,C65 | 100nF | Capacitor_SMD:C_0402_1005Metric | 10
C19,C39,C59,C63 | 10uF | Capacitor_SMD:C_0603_1608Metric | 4
C20,C40,C60 | 4.7uF | Capacitor_SMD:C_0603_1608Metric | 3
C61 | 1uF | Capacitor_SMD:C_0402_1005Metric | 1
C62,C64 | 1uF | Capacitor_SMD:C_0603_1608Metric | 2
D1-D3 | GREEN | LED_SMD:LED_0603_1608Metric | 3
D4 | PWR | LED_SMD:LED_0603_1608Metric | 1
D5 | PRTR5V0U2F | nordic:SON50P100X50-6N | 1
D6 | SMAJ5.0A | Diode_SMD:D_SMA | 1
D7,D8 | PESD5V0S1BA | Diode_SMD:D_SOD-323 | 2
FB1,FB3,FB5 | 120R | nRF54LM20A:DK_L_0201_0603Metric | 3
FB2,FB4,FB6 | 15nH | nRF54LM20A:DK_L_0201_0603Metric | 3
FB7 | 120R/3A | nordic:INDC1608X06L | 1
J1,J4,J7 | SMA_2081005-1 | nordic:SMA_2081005-1 | 3
J2,J5,J8 | SMA_2081005-1 | nordic:SMA_2081005-1 | 3 | DNP
J3 | SWD+ETM ch37 | Connector_PinHeader_2.54mm:PinHeader_2x05_P2.54mm_Vertical | 1
J6 | SWD+ETM ch38 | Connector_PinHeader_2.54mm:PinHeader_2x05_P2.54mm_Vertical | 1
J9 | SWD+ETM ch39 | Connector_PinHeader_2.54mm:PinHeader_2x05_P2.54mm_Vertical | 1
J10 | USB-C | ext:USB-C_SMD-TYPE-C-31-M-12_1 | 1
L1,L10,L19 | 3.6nH | nRF54LM20A:DK_L_0201_0603Metric | 3
L2,L11,L20 | 4.7nH | nRF54LM20A:DK_L_0201_0603Metric | 3
L3,L12,L21 | 3.3nH | nRF54LM20A:DK_L_0201_0603Metric | 3
L4,L13,L22 | 1.9nH | nRF54LM20A:DK_L_0201_0603Metric | 3
L5,L14,L23 | 3.0nH | nRF54LM20A:DK_L_0201_0603Metric | 3
L6,L15,L24 | 1.9nH | nRF54LM20A:DK_L_0201_0603Metric | 3 | DNP
L7,L16,L25 | 3.0nH | nRF54LM20A:DK_L_0201_0603Metric | 3 | DNP
L8,L17,L26 | 4.7uH | nRF54LM20A:DK_L_0603_1608Metric | 3
L9,L18,L27 | 1.0nH | nRF54LM20A:DK_L_0201_0603Metric | 3
L28 | DLM0NSM900HY2D | nordic:CMC0806X05N | 1
R1,R6,R11 | 33k | nRF54LM20A:DK_R_0201_0603Metric | 3
R2,R7,R12,R18 | 1k | Resistor_SMD:R_0402_1005Metric | 4
R3-R5,R8-R10,R13-R15 | 10k | Resistor_SMD:R_0402_1005Metric | 9
R16,R17 | 5.1k | Resistor_SMD:R_0402_1005Metric | 2
R19 | 4.7k | Resistor_SMD:R_0402_1005Metric | 1
SW1,SW3,SW5 | BOOT | Button_Switch_SMD:SW_SPST_SKQG_WithoutStem | 3
SW2,SW4,SW6 | RESET | Button_Switch_SMD:SW_SPST_SKQG_WithoutStem | 3
U1 | nRF54LM20A ch37 | nRF54LM20A:BGA98C35P10X10_367X385X86 | 1
U2 | nRF54LM20A ch38 | nRF54LM20A:BGA98C35P10X10_367X385X86 | 1
U3 | nRF54LM20A ch39 | nRF54LM20A:BGA98C35P10X10_367X385X86 | 1
U4-U6 | nRF21540-QDAA | nRF54LM20A:nRF21540_QFN16_4x4mm_P0.65mm_EP2.65 | 3
U7 | CH334F | ext:QFN-24_L4.0-W4.0-P0.50-BL-EP2.8 | 1
U8 | AP2112K-3.3 | ext:SOT-25-5_L2.9-W1.6-P0.95-LS2.8-BL | 1
Y1-Y3 | 32MHz | nRF54LM20A:DK_Crystal_32MHz | 3

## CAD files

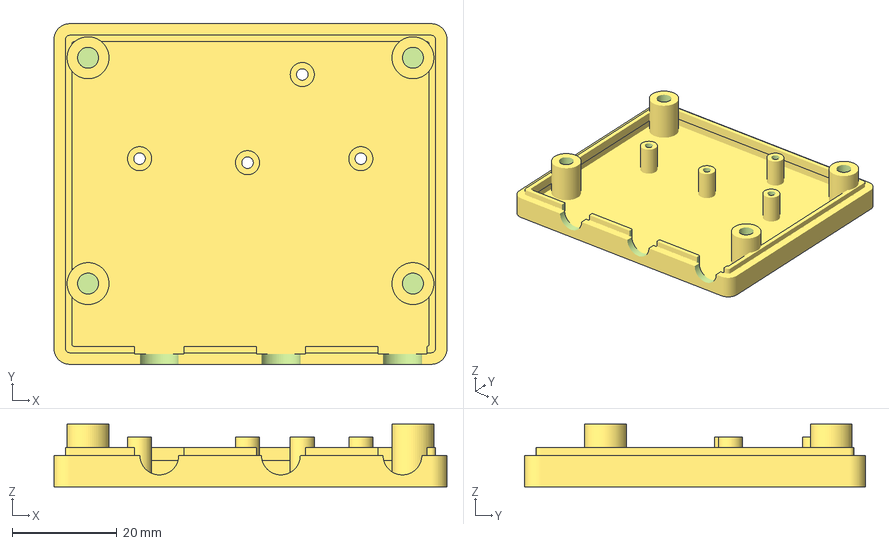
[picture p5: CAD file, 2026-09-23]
hardware/case/blehound_lid.3mf
75.0 x 65.0 x 12.0 mm

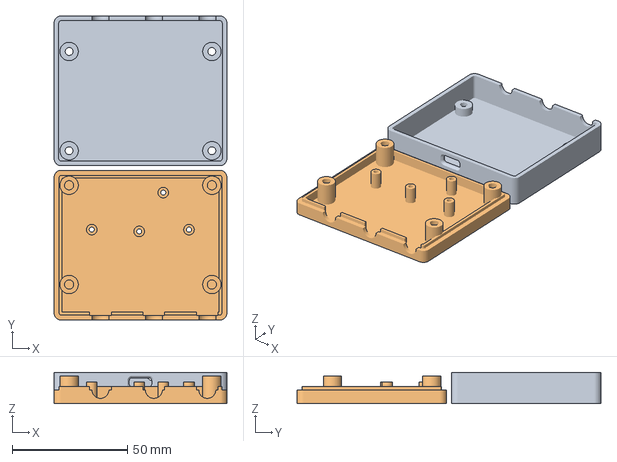
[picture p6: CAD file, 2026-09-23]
hardware/case/blehound_case_P2S_PLA_0.2mm.gcode.3mf
75.0 x 132.0 x 13.6 mm
blehound_tray.stl
blehound_lid.stl

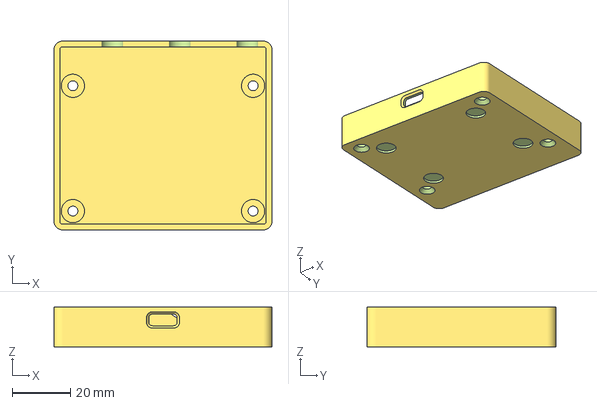
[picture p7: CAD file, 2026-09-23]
hardware/case/blehound_tray.3mf
75.0 x 65.0 x 13.6 mm

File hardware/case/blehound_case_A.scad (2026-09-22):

// =====================================================================
//  BLEhound case · Variant A (tray + lid)
//  - 4x M3 countersunk from the bottom, through the tray bosses and the PCB mounting holes, into heat-set inserts in the lid bosses
//  - Top face has only the 4 LED holes (+ engraved text); buttons/SWD require opening the lid
//  - Antenna-end SMA holes sit on the parting line (parting line = SMA axis 6.0), half-circle in tray and half in lid; USB-C exits the rear wall via a 9.8x4.0 cutout
//  Coordinate frame: PCB bottom-left = (0,0), PCB top face = z 0 (matches the delivered coordinate file, x = MidX-113.5, y = MidY+135)
//  Render: openscad -o tray.stl -D 'part="tray"' blehound_case_A.scad
//        openscad -o lid.stl  -D 'part="lid"'  blehound_case_A.scad   (lid is pre-flipped, print as-is)
// =====================================================================

part = "both";        // "tray" | "lid" | "both" (both = assembly preview, includes PCB)
explode = 0;          // explode distance for the assembly preview (mm)

// ---------- PCB (from the delivered file, do not edit) ----------
pcb_w = 70;  pcb_d = 60;  pcb_t = 1.6;
holes  = [[4,4],[66,4],[4,47.095],[66,47.095]];        // M3 Ø3.2
sma_x  = [17.6, 40.8, 64.0];                            // J1 J4 J7 (populated)
ant2_x = [6.0, 29.2, 52.4];                             // J2 J5 J8 (reserved, no slot by default)
leds   = [[13.833,23.26],[34.436,24.022],[56.055,23.26],[44.883,7.202]];   // D1 D2 D3 D4
led_names = ["CH37","CH38","CH39","PWR"];
sw_pos = [[6.017,18.915],[15.44,18.915],[24.863,18.915],[45.336,18.915],[55.059,18.915],[64.782,18.915]];
hdr_x  = [23.933, 45.408, 66.429];  hdr_y = 35.329;     // 2x5 pin header
usb_x  = 35;

// ---------- Connector measurements/specs ----------
// SMA-KWE external-thread inner-hole right-angle jack (overall 14.5, thread 8.5, body 6x6x9.2, pin 3.5, pin pitch 5.1x5.1)
// Body front face is 0.4 beyond the front pin row -> front face 1.0 inside the board edge; thread extends 8.5 from the face -> 7.5 beyond the board edge
sma_axis_z   = 6.0;    // thread axis above the PCB top face: body height 9.2, thread Ø6.35 top flush with body top -> 9.2-3.2
sma_body_h   = 9.2;
sma_body_y0  = 53.0;   sma_body_y1 = 59.0;
sma_thread_l = 8.5;
sma_slot_d   = 7.4;    // thread Ø6.35 + axis-height ±0.3 margin; parting line runs through the axis, half-circle top and bottom
usb_protrude = 1.4;    // USB-C receptacle overhang past the board edge (measured)
usb_cut_w    = 9.8;    // receptacle body 8.94x3.26 + 0.4 per side; plug metal shell 8.3x2.6 fits through, overmold stays outside the wall
usb_cut_h    = 4.0;
usb_cut_r    = 1.3;
usb_chamfer  = 0.8;    // 45° lead-in chamfer on the outer side of the cutout
ant2_slots   = false;  // set true once ANT2 is populated (adds 3 more half-circle slots in the front wall, lid follows)

// ---------- Case parameters ----------
clr        = 0.5;      // clearance around the PCB
wall       = 2.0;
floor_t    = 2.0;
lid_t      = 2.0;
standoff_h = 4.0;      // PCB bottom to tray inner floor: through-hole pin tails + solder joints
inner_h    = 10.0;     // PCB top to lid inner ceiling: pin header 8.5 + 1.5
part_z     = sma_axis_z;   // parting line through the SMA axis; SMA hole is half-circle top/bottom; board drops in flat
corner_r   = 3.0;      // outer corner radius
boss_d     = 8.0;      // boss diameter, top and bottom (M3 heat-set insert OD 4.6, wall ≈1.7)
screw_d    = 3.4;      // M3 clearance hole
csk_d      = 6.4;      // countersink top diameter (M3 flat head 90°)
csk_depth  = 1.5;
insert_d   = 4.0;      // M3x4x5 heat-set insert pilot hole (some batches need 4.2)
insert_h   = 6.5;      // insert 5 + screw-tip margin
lip_h      = 1.5;      // depth the lid inner lip reaches into the tray
lip_t      = 1.2;
lip_clr    = 0.2;
led_hole_d = 2.2;
led_tube_d = 4.6;      // light-pipe OD under the lid
led_tube_bottom_z = 2.5;   // light-pipe lower end above the PCB top face (LED height 0.7, button height 1.5)
pin_holes  = false;    // when true, add a Ø2.2 pinhole in the top face over each of the 6 buttons
pin_hole_d = 2.2;
feet_pos   = [[12,10],[58,10],[12,41],[58,41]];   // foot-pad positions (clear of the screws)
foot_d     = 8;  foot_depth = 1.0;
text_top   = "BLEhound";
text_depth = 0.4;
$fn = 64;

// ---------- Derived ----------
ox0 = -clr - wall;   ox1 = pcb_w + clr + wall;
oy0 = -clr - wall;   oy1 = pcb_d + clr + wall;
z_floor = -pcb_t - standoff_h - floor_t;     // -7.6
z_top   = inner_h + lid_t;                   // 12.0
total_h = z_top - z_floor;                   // 19.6
echo(str("Outer ", ox1-ox0, " x ", oy1-oy0, " x ", total_h, " mm; suggested M3 screw length 12 (into insert ", 12-(floor_t+standoff_h+pcb_t), " mm)"));
echo(str("SMA thread past the wall ", sma_thread_l - (pcb_d - sma_body_y1) - clr - wall, " mm (after a 2.2 nut, ", sma_thread_l - (pcb_d - sma_body_y1) - clr - wall - 2.2, " left for the antenna)"));

module rrect(x0,y0,x1,y1,r,h){          // rounded rectangular prism, z from 0 to h
  hull() for (x=[x0+r,x1-r], y=[y0+r,y1-r]) translate([x,y,0]) cylinder(r=r,h=h);
}
module outer_block(z0,z1){ translate([0,0,z0]) rrect(ox0,oy0,ox1,oy1,corner_r,z1-z0); }
module cavity_block(z0,z1){ translate([0,0,z0]) rrect(-clr,-clr,pcb_w+clr,pcb_d+clr,max(corner_r-wall,0.6),z1-z0); }

// ================= Tray =================
module tray(){
  difference(){
    union(){
      difference(){
        outer_block(z_floor, part_z);
        cavity_block(z_floor+floor_t, part_z+1);
      }
      // bosses: inner floor -> PCB bottom
      for (h=holes) translate([h[0],h[1],z_floor+floor_t-0.01]) cylinder(d=boss_d, h=standoff_h+0.01);
    }
    // M3 clearance hole + bottom countersink
    for (h=holes) translate([h[0],h[1],0]) {
      translate([0,0,z_floor-1]) cylinder(d=screw_d, h=floor_t+standoff_h+2);
      translate([0,0,z_floor-0.01]) cylinder(d1=csk_d, d2=screw_d, h=csk_depth);
    }
    // front-wall SMA holes: full circle across the parting line; tray gets the lower half (opening up)
    sma_holes();
    // rear-wall USB-C cutout (closed, rounded, outer lead-in chamfer); receptacle center height 1.63
    usb_cut();
    // foot-pad recesses
    for (f=feet_pos) translate([f[0],f[1],z_floor-0.01]) cylinder(d=foot_d, h=foot_depth+0.01);
  }
}

module sma_holes(){
  for (x = concat(sma_x, ant2_slots ? ant2_x : []))
    translate([x, pcb_d+clr-1, sma_axis_z]) rotate([-90,0,0]) cylinder(d=sma_slot_d, h=wall+2);
}
module usb_cut(){
  zc = 3.26/2;
  translate([usb_x, -clr-wall-1, zc]) rotate([-90,0,0]) {
    linear_extrude(wall+2) offset(r=usb_cut_r) offset(delta=-usb_cut_r) square([usb_cut_w, usb_cut_h], center=true);
    // outer chamfer: usb_chamfer deep from the outer surface, opening larger by 2*usb_chamfer
    hull(){
      translate([0,0,1-0.01]) linear_extrude(0.01) offset(r=usb_cut_r+usb_chamfer) offset(delta=-usb_cut_r) square([usb_cut_w, usb_cut_h], center=true);
      translate([0,0,1+usb_chamfer]) linear_extrude(0.01) offset(r=usb_cut_r) offset(delta=-usb_cut_r) square([usb_cut_w, usb_cut_h], center=true);
    }
  }
}
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

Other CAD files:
hardware/case/blehound_case_P2S_PETG_0.2mm.gcode.3mf
hardware/case/blehound_lid.stl
hardware/case/blehound_tray.stl

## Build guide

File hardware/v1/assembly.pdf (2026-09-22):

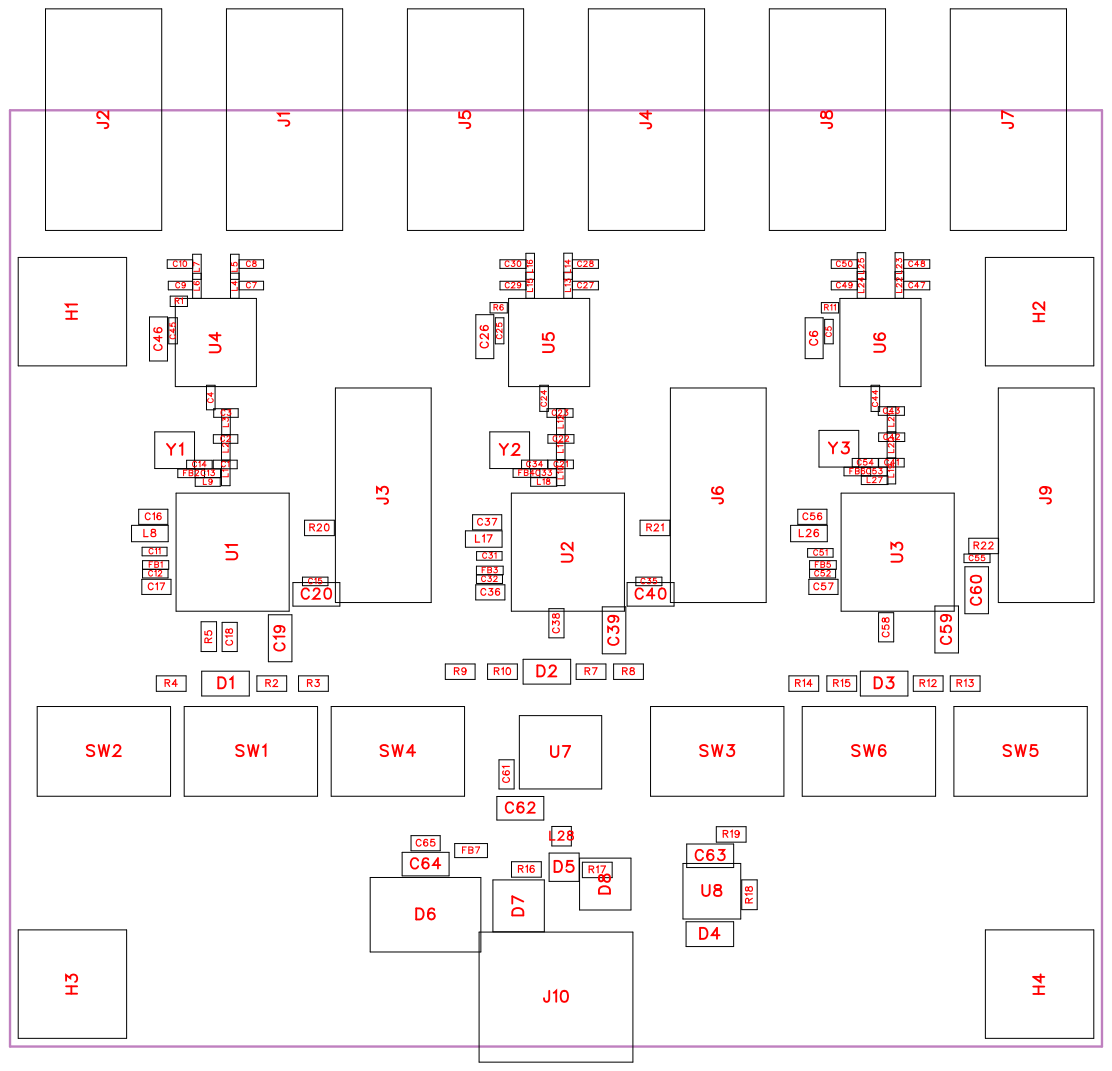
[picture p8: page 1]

No. | Quantity | Comment | Designator | Footprint | Value | Manufacturer Part | Manufacturer | Supplier Part | Supplier
1 | 3 | 1.2pF | C1,C21,C41 | nRF54LM20 A:DK_C_020 1_0603Metric | 1.2pF
2 | 3 | 1.5pF | C2,C22,C42 | nRF54LM20 A:DK_C_020 1_0603Metric | 1.2pF
3 | 3 | 0.3pF | C3,C23,C43 | nRF54LM20 A:DK_C_020 1_0603Metric | 1.2pF
4 | 12 | 1.0pF | C4,C8,C10,C13,C24,C28,C 30,C33,C44,C48,C50,C53 | nRF54LM20 A:DK_C_020 1_0603Metric | 1.2pF
5 | 3 | 100nF | C5,C25,C45 | nRF54LM20 A:DK_C_020 1_0603Metric | 1.2pF
6 | 3 | 10uF | C6,C26,C46 | nRF54LM20 A:DK_C_040 2_1005Metric | 10uF
7 | 6 | 2.0pF | C7,C9,C27,C29,C47,C49 | nRF54LM20 A:DK_C_020 1_0603Metric | 1.2pF
8 | 3 | 4.7uF | C11,C31,C51 | nRF54LM20 A:DK_C_020 1_0603Metric | 1.2pF
9 | 9 | 2.2uF | C12,C14,C15,C32,C34,C35 ,C52,C54,C55 | nRF54LM20 A:DK_C_020 1_0603Metric | 1.2pF
10 | 10 | 100nF | C16,C17,C18,C36,C37,C38 ,C56,C57,C58,C65 | Capacitor_S MD:C_0402_ 1005Metric | 100nF
11 | 4 | 10uF | C19,C39,C59,C63 | Capacitor_S MD:C_0603_ 1608Metric | 10uF
12 | 3 | 4.7uF | C20,C40,C60 | Capacitor_S MD:C_0603_ 1608Metric | 10uF
13 | 1 | 1uF | C61 | Capacitor_S MD:C_0402_ 1005Metric | 100nF
14 | 2 | 1uF | C62,C64 | Capacitor_S MD:C_0603_ 1608Metric | 10uF
15 | 3 | GREEN | D1,D2,D3 | LED_SMD:L ED_0603_16 08Metric | GREEN
16 | 1 | PWR | D4 | LED_SMD:L ED_0603_16 08Metric | GREEN

17 | 1 | PRTR5V0U2 F | D5 | nordic:SON5 0P100X50-6 N | PRTR5V0U2 F
18 | 1 | SMAJ5.0A | D6 | Diode_SMD: D_SMA | SMAJ5.0A
19 | 2 | PESD5V0S1 BA | D7,D8 | Diode_SMD: D_SOD-323 | PESD5V0S1 BA
20 | 3 | 120R | FB1,FB3,FB5 | nRF54LM20 A:DK_L_020 1_0603Metric | 3.6nH
21 | 3 | 15nH | FB2,FB4,FB6 | nRF54LM20 A:DK_L_020 1_0603Metric | 3.6nH
22 | 1 | 120R/3A | FB7 | nordic:INDC1 608X06L | 120R/3A
23 | 4 | M3 | H1,H2,H3,H4 | MountingHol e_3.2mm_M 3
24 | 6 | osd_COAX_ SMA | J1,J2,J4,J5,J7,J8 | nordic:SMA_ RA_TH_Tao glas | PCB.SMAFR A.HT
25 | 1 | SWD+ETM ch37 | J3 | Connector_Pi nHeader_2.5 4mm:PinHea der_2x05_P2 .54mm_Verti cal | SWD+ETM ch37
26 | 1 | SWD+ETM ch38 | J6 | Connector_Pi nHeader_2.5 4mm:PinHea der_2x05_P2 .54mm_Verti cal | SWD+ETM ch37
27 | 1 | SWD+ETM ch39 | J9 | Connector_Pi nHeader_2.5 4mm:PinHea der_2x05_P2 .54mm_Verti cal | SWD+ETM ch37
28 | 1 | USB-C | J10 | ext:USB-C_S MD-TYPE-C-31-M-12_1 | USB-C
29 | 3 | 3.6nH | L1,L10,L19 | nRF54LM20 A:DK_L_020 1_0603Metric | 3.6nH
30 | 3 | 4.7nH | L2,L11,L20 | nRF54LM20 A:DK_L_020 1_0603Metric | 3.6nH
31 | 3 | 3.3nH | L3,L12,L21 | nRF54LM20 A:DK_L_020 1_0603Metric | 3.6nH

32 | 6 | 1.9nH | L4,L6,L13,L15,L22,L24 | nRF54LM20 A:DK_L_020 1_0603Metric | 3.6nH
33 | 6 | 3.0nH | L5,L7,L14,L16,L23,L25 | nRF54LM20 A:DK_L_020 1_0603Metric | 3.6nH
34 | 3 | 4.7uH | L8,L17,L26 | nRF54LM20 A:DK_L_060 3_1608Metric | 4.7uH
35 | 3 | 1.0nH | L9,L18,L27 | nRF54LM20 A:DK_L_020 1_0603Metric | 3.6nH
36 | 1 | DLM0NSM90 0HY2D | L28 | nordic:CMC0 806X05N | DLM0NSM90 0HY2D
37 | 3 | 33k | R1,R6,R11 | nRF54LM20 A:DK_R_020 1_0603Metric | 33k
38 | 4 | 1k | R2,R7,R12,R18 | Resistor_SM D:R_0402_1 005Metric | 1k
39 | 9 | 10k | R3,R4,R5,R8,R9,R10,R13, R14,R15 | Resistor_SM D:R_0402_1 005Metric | 1k
40 | 2 | 5.1k | R16,R17 | Resistor_SM D:R_0402_1 005Metric | 1k
41 | 1 | 4.7k | R19 | Resistor_SM D:R_0402_1 005Metric | 1k
42 | 3 | 200R | R20,R21,R22 | Resistor_SM D:R_0402_1 005Metric | 1k
43 | 3 | BOOT | SW1,SW3,SW5 | Button_Switc h_SMD:SW_ SPST_SKQG _WithoutSte m | BOOT
44 | 3 | RESET | SW2,SW4,SW6 | Button_Switc h_SMD:SW_ SPST_SKQG _WithoutSte m | BOOT
45 | 1 | nRF54LM20 A ch37 | U1 | nRF54LM20 A:nRF54LM2 0A_QFN52_ 6x6mm_P0.4 mm_EP4.7x4 .7mm | nRF54LM20 A ch37

46 | 1 | nRF54LM20 A ch38 | U2 | nRF54LM20 A:nRF54LM2 0A_QFN52_ 6x6mm_P0.4 mm_EP4.7x4 .7mm | nRF54LM20 A ch37
47 | 1 | nRF54LM20 A ch39 | U3 | nRF54LM20 A:nRF54LM2 0A_QFN52_ 6x6mm_P0.4 mm_EP4.7x4 .7mm | nRF54LM20 A ch37
48 | 3 | nRF21540-Q DAA | U4,U5,U6 | nRF54LM20 A:nRF21540 _QFN16_4x4 mm_P0.65m m_EP2.65 | nRF21540-Q DAA
49 | 1 | CH334F | U7 | ext:QFN-24_ L4.0-W4.0-P 0.50-BL-EP2. 8 | CH334F
50 | 1 | AP2112K-3.3 | U8 | ext:SOT-25-5 _L2.9-W1.6-P0.95-LS2.8-BL | AP2112K-3.3
51 | 3 | 32MHz | Y1,Y2,Y3 | nRF54LM20 A:DK_Crystal _32MHz | 32MHz

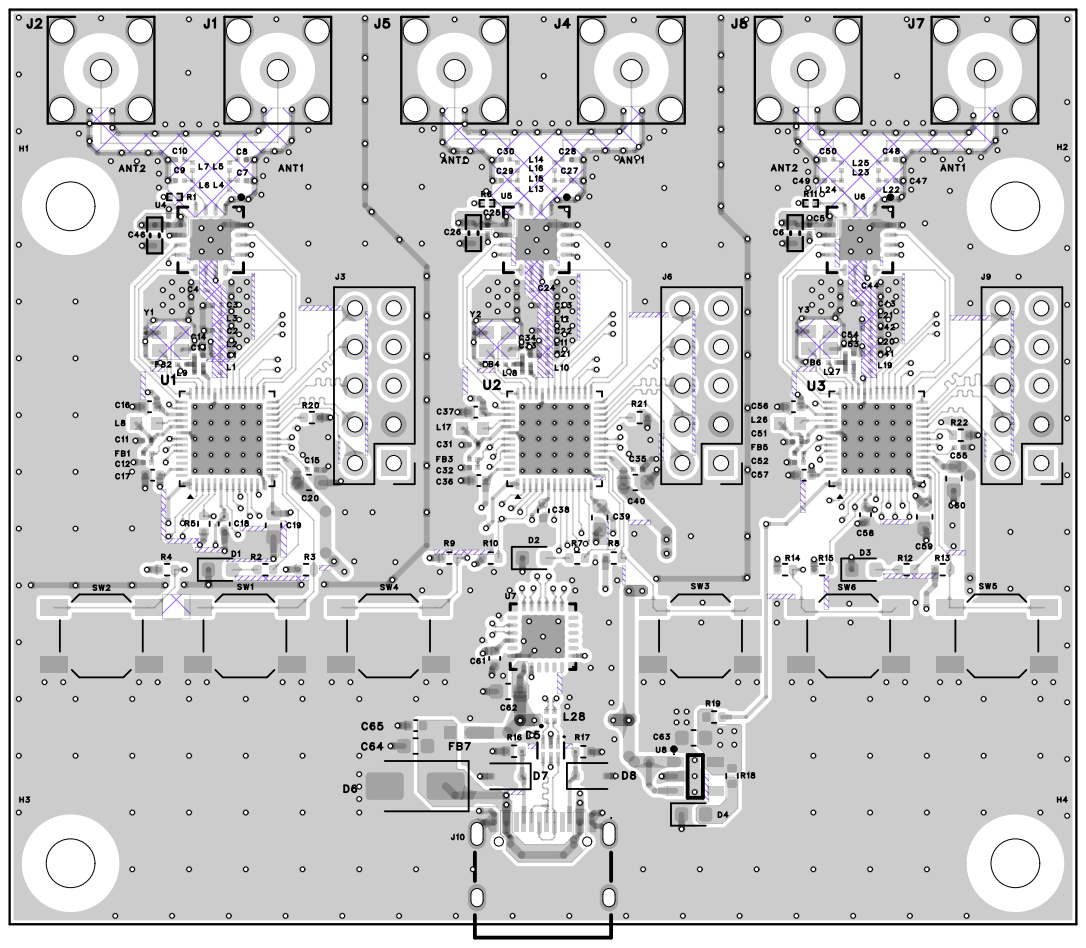
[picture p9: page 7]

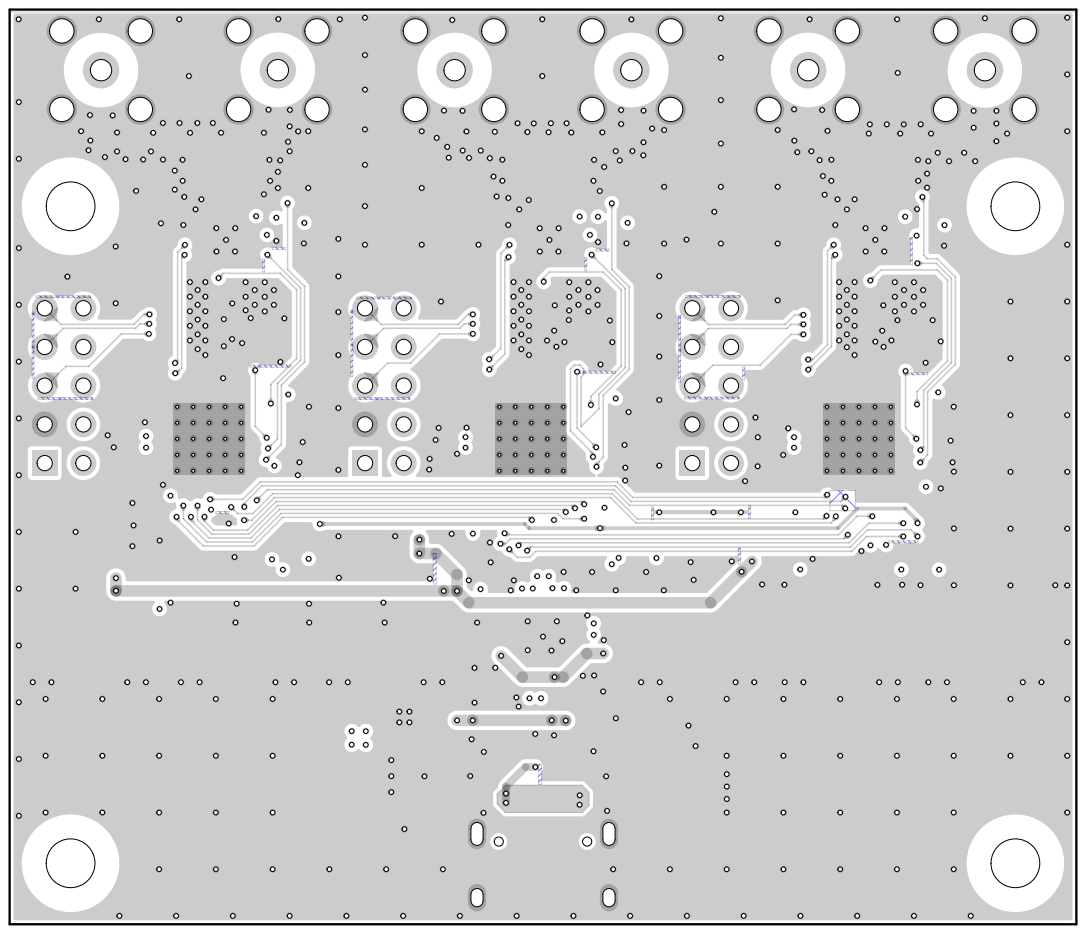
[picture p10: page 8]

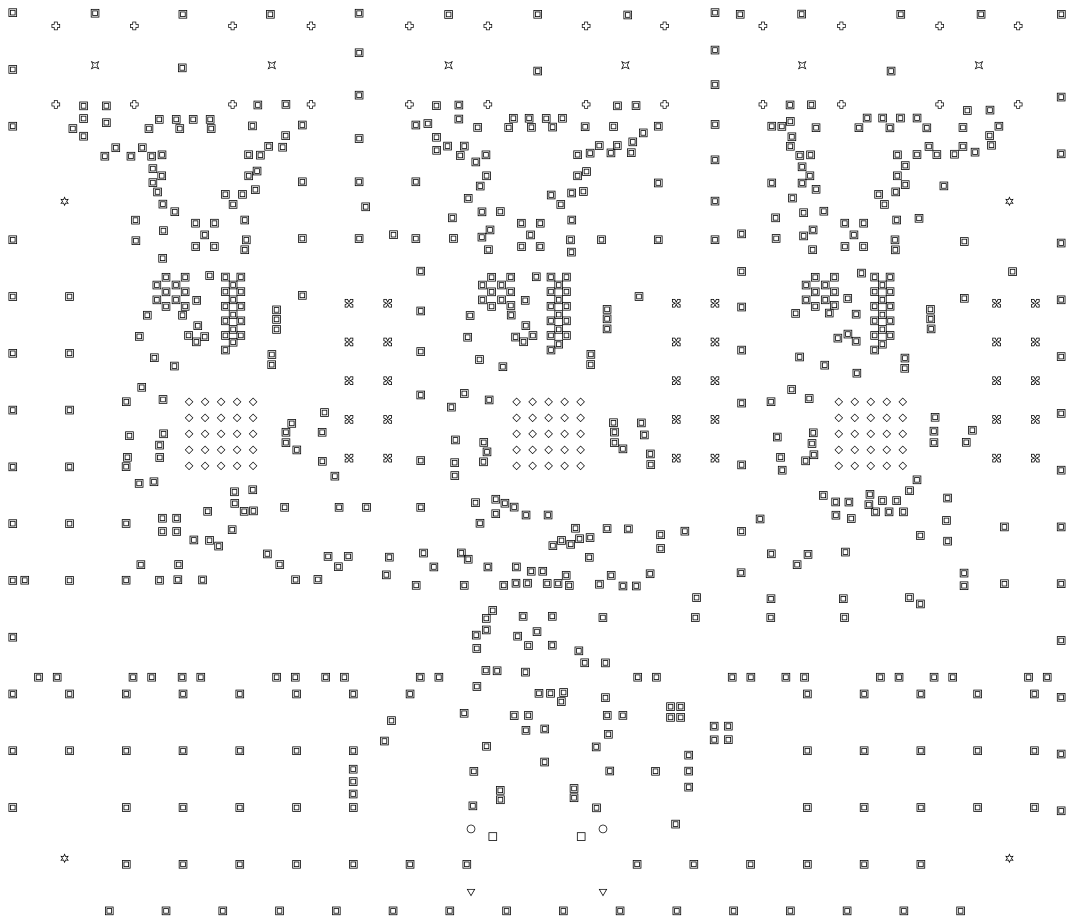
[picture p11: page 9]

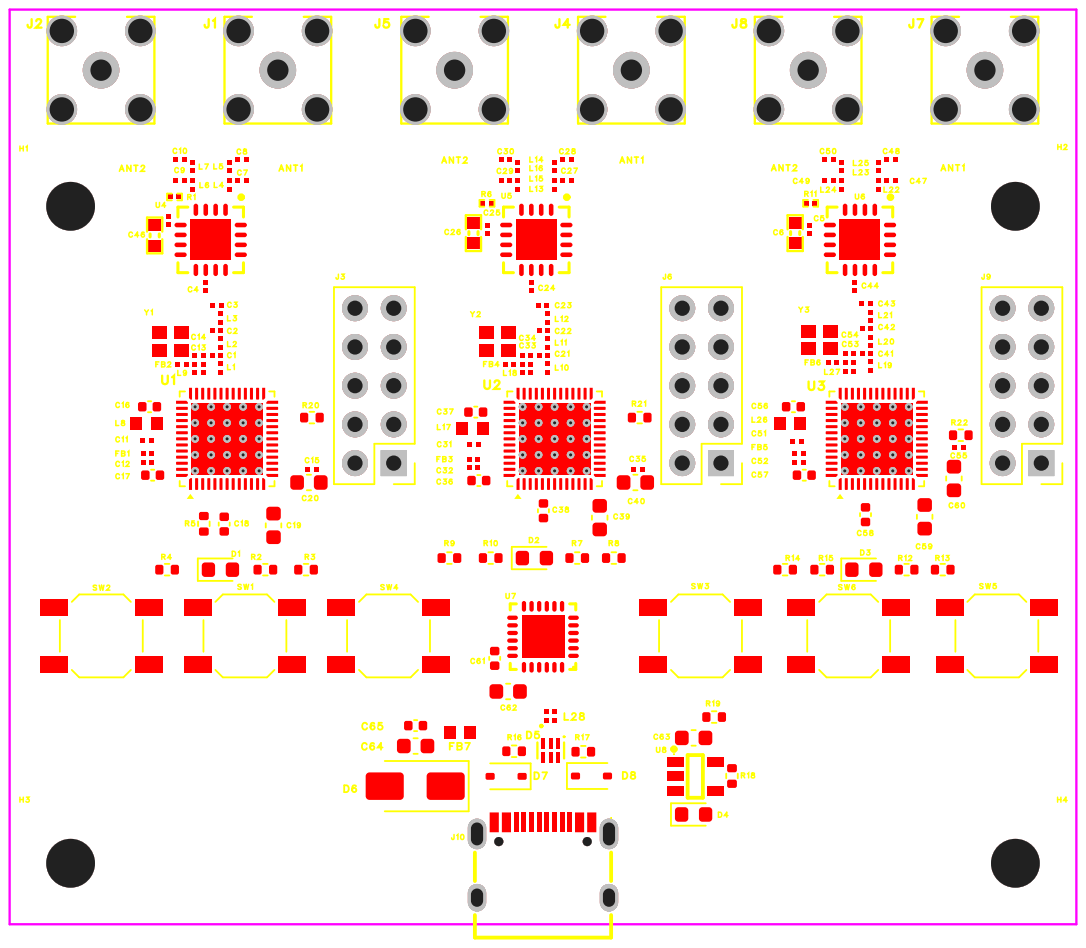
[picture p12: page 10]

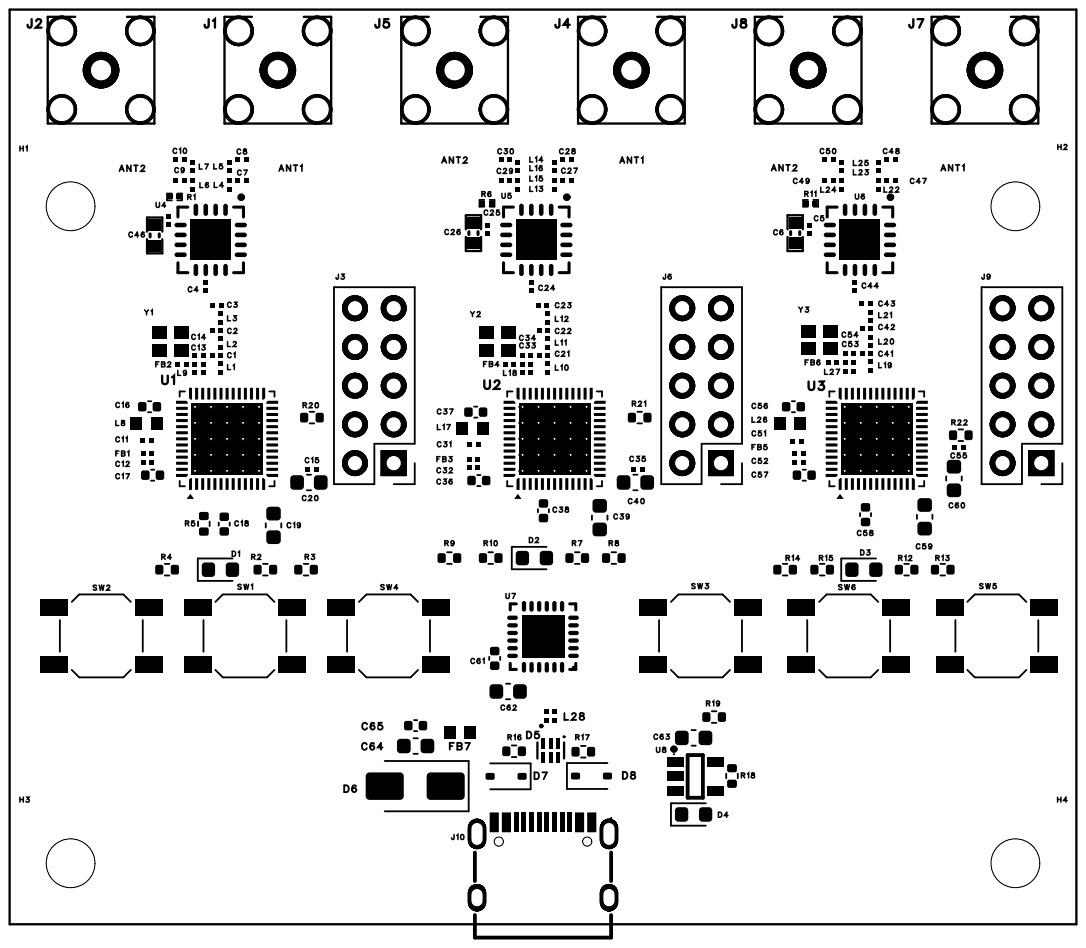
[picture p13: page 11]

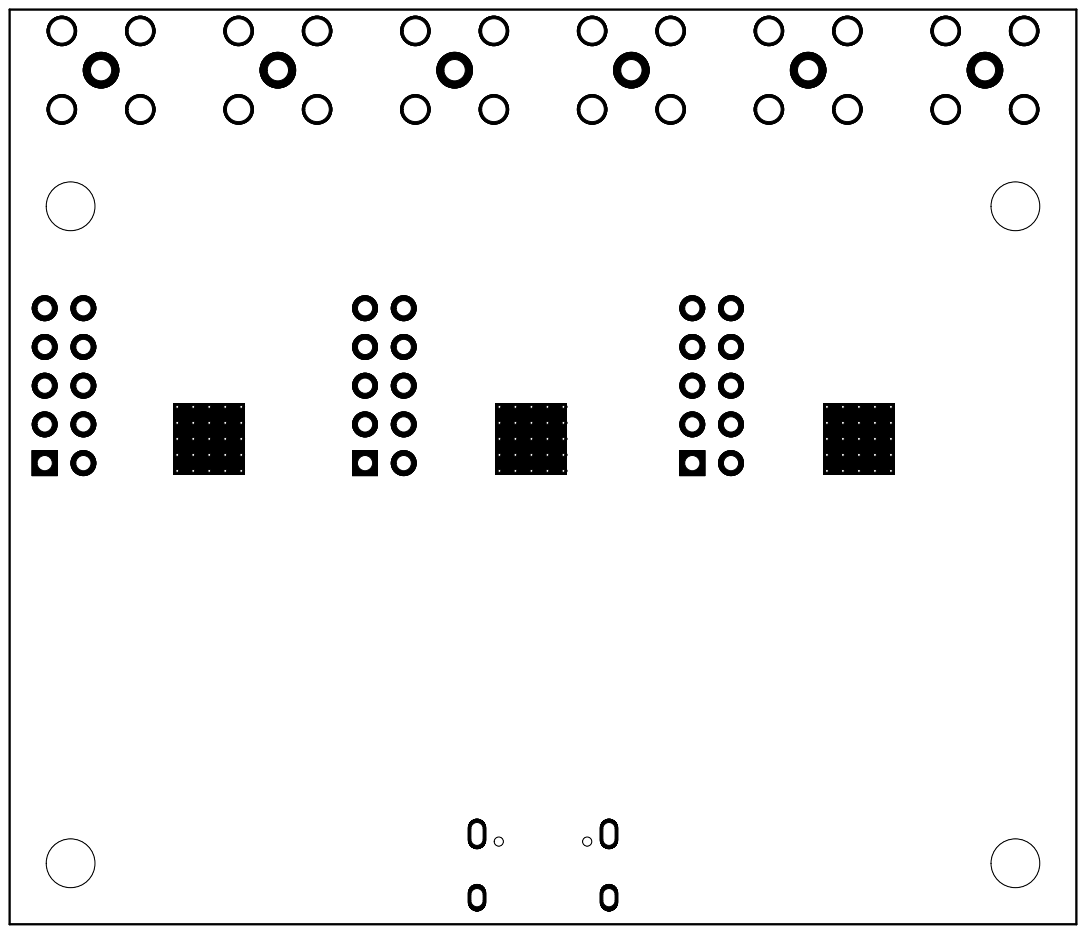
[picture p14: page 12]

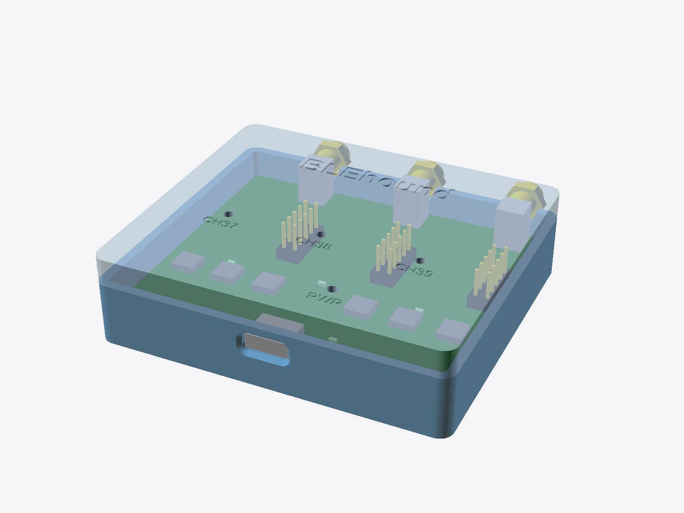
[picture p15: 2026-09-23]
hardware/case/preview_assembled.png

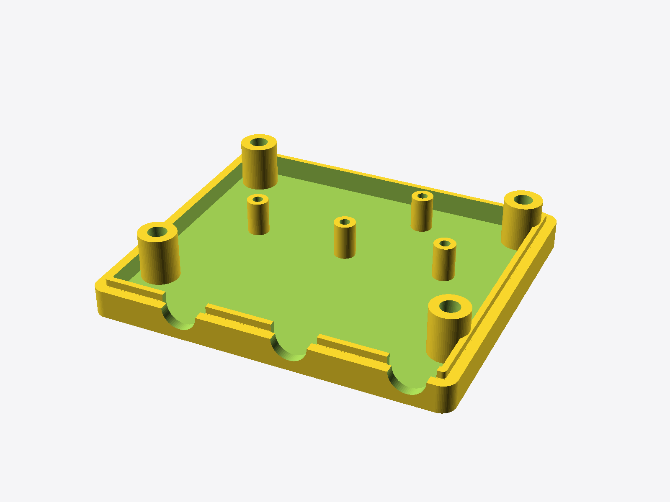
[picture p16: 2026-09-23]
hardware/case/preview_lid_print.png

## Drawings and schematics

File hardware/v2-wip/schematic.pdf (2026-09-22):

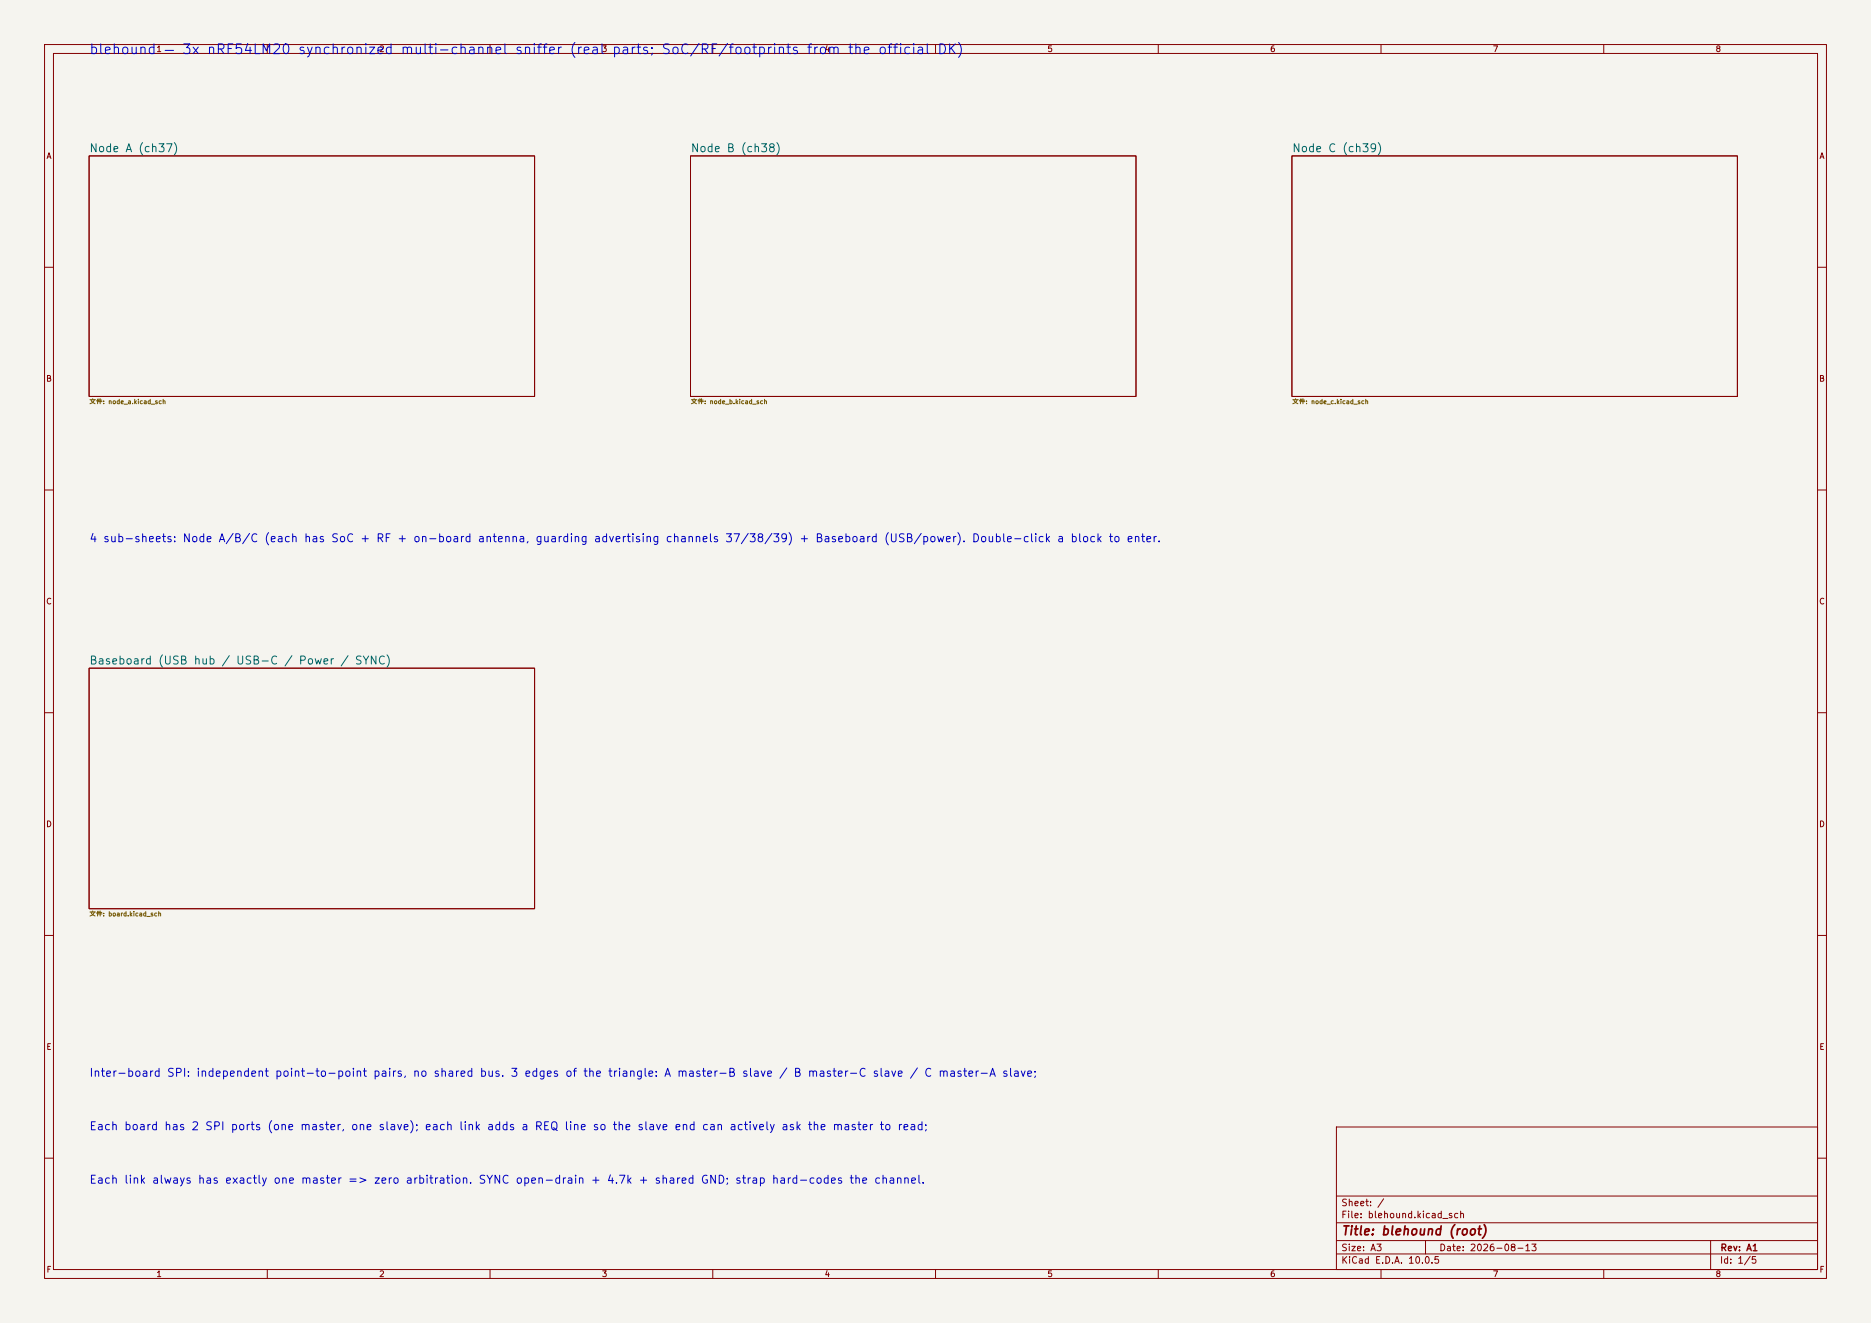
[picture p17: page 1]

4 sub-sheets: Node A/B/C (each has SoC + RF + on-board antenna, guarding advertising channels 37/38/39) + Baseboard (USB/power). Double-click a block to enter.

Inter-board SPI: independent point-to-point pairs, no shared bus. 3 edges of the triangle: A master-B slave / B master-C slave / C master-A slave;

Each board has 2 SPI ports (one master, one slave); each link adds a REQ line so the slave end can actively ask the master to read;

Each link always has exactly one master => zero arbitration. SYNC open-drain + 4.7k + shared GND; strap hard-codes the channel.

Size: A3 | Rev: A1 | F Date: 2026-08-13
KiCad E.D.A. 10.0.5 | Id: 1/5

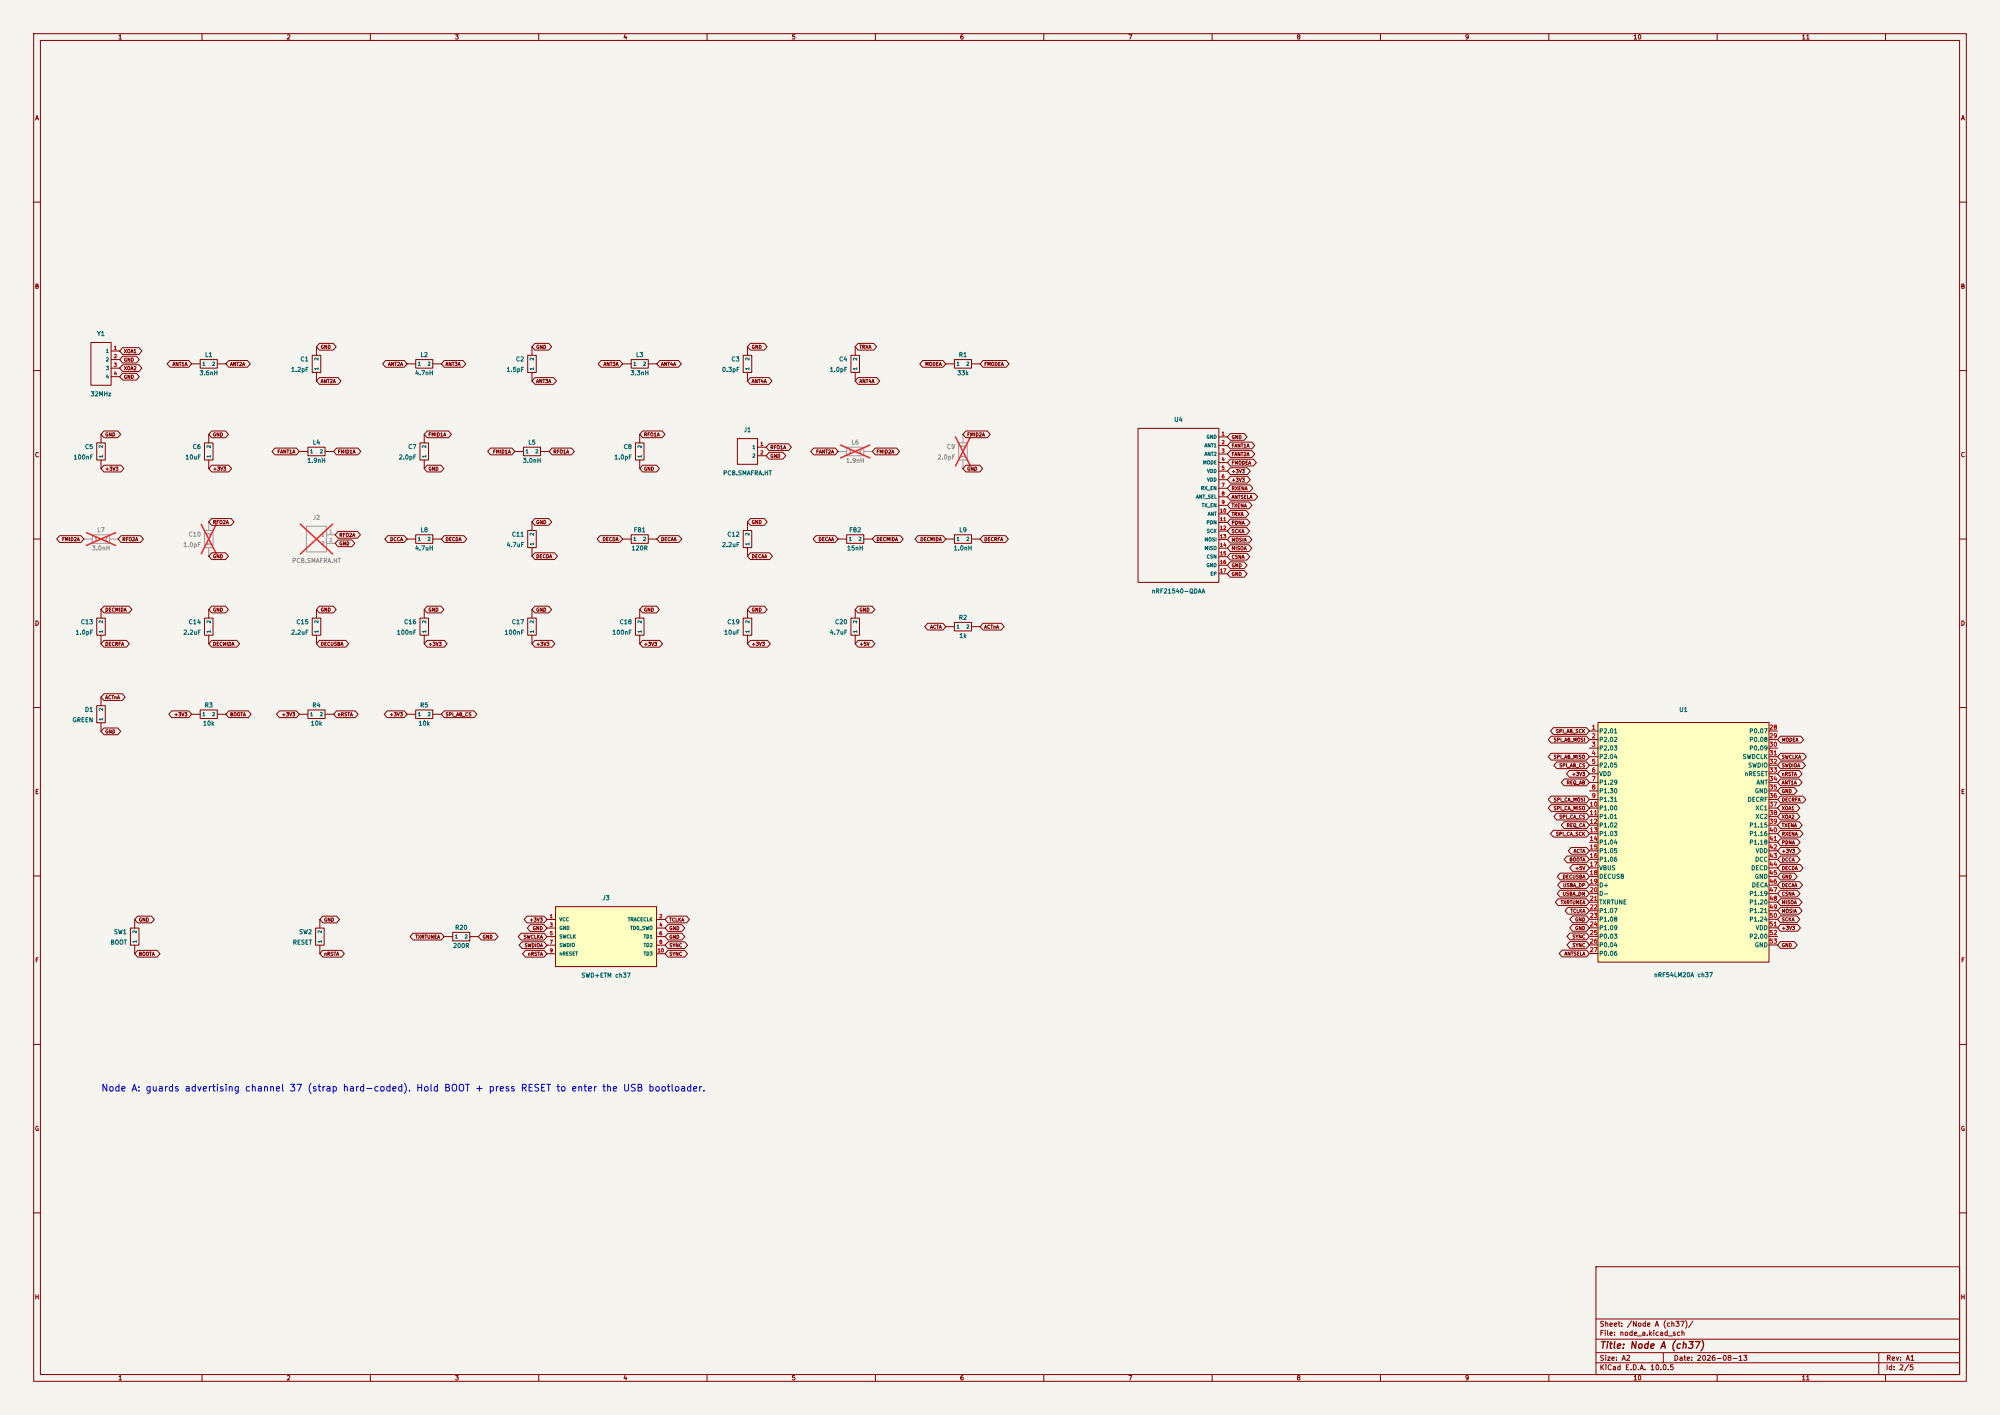
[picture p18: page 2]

+3V3 Node A: guards advertising channel 37 (strap hard-coded). Hold BOOT + press RESET to enter the USB bootloader.

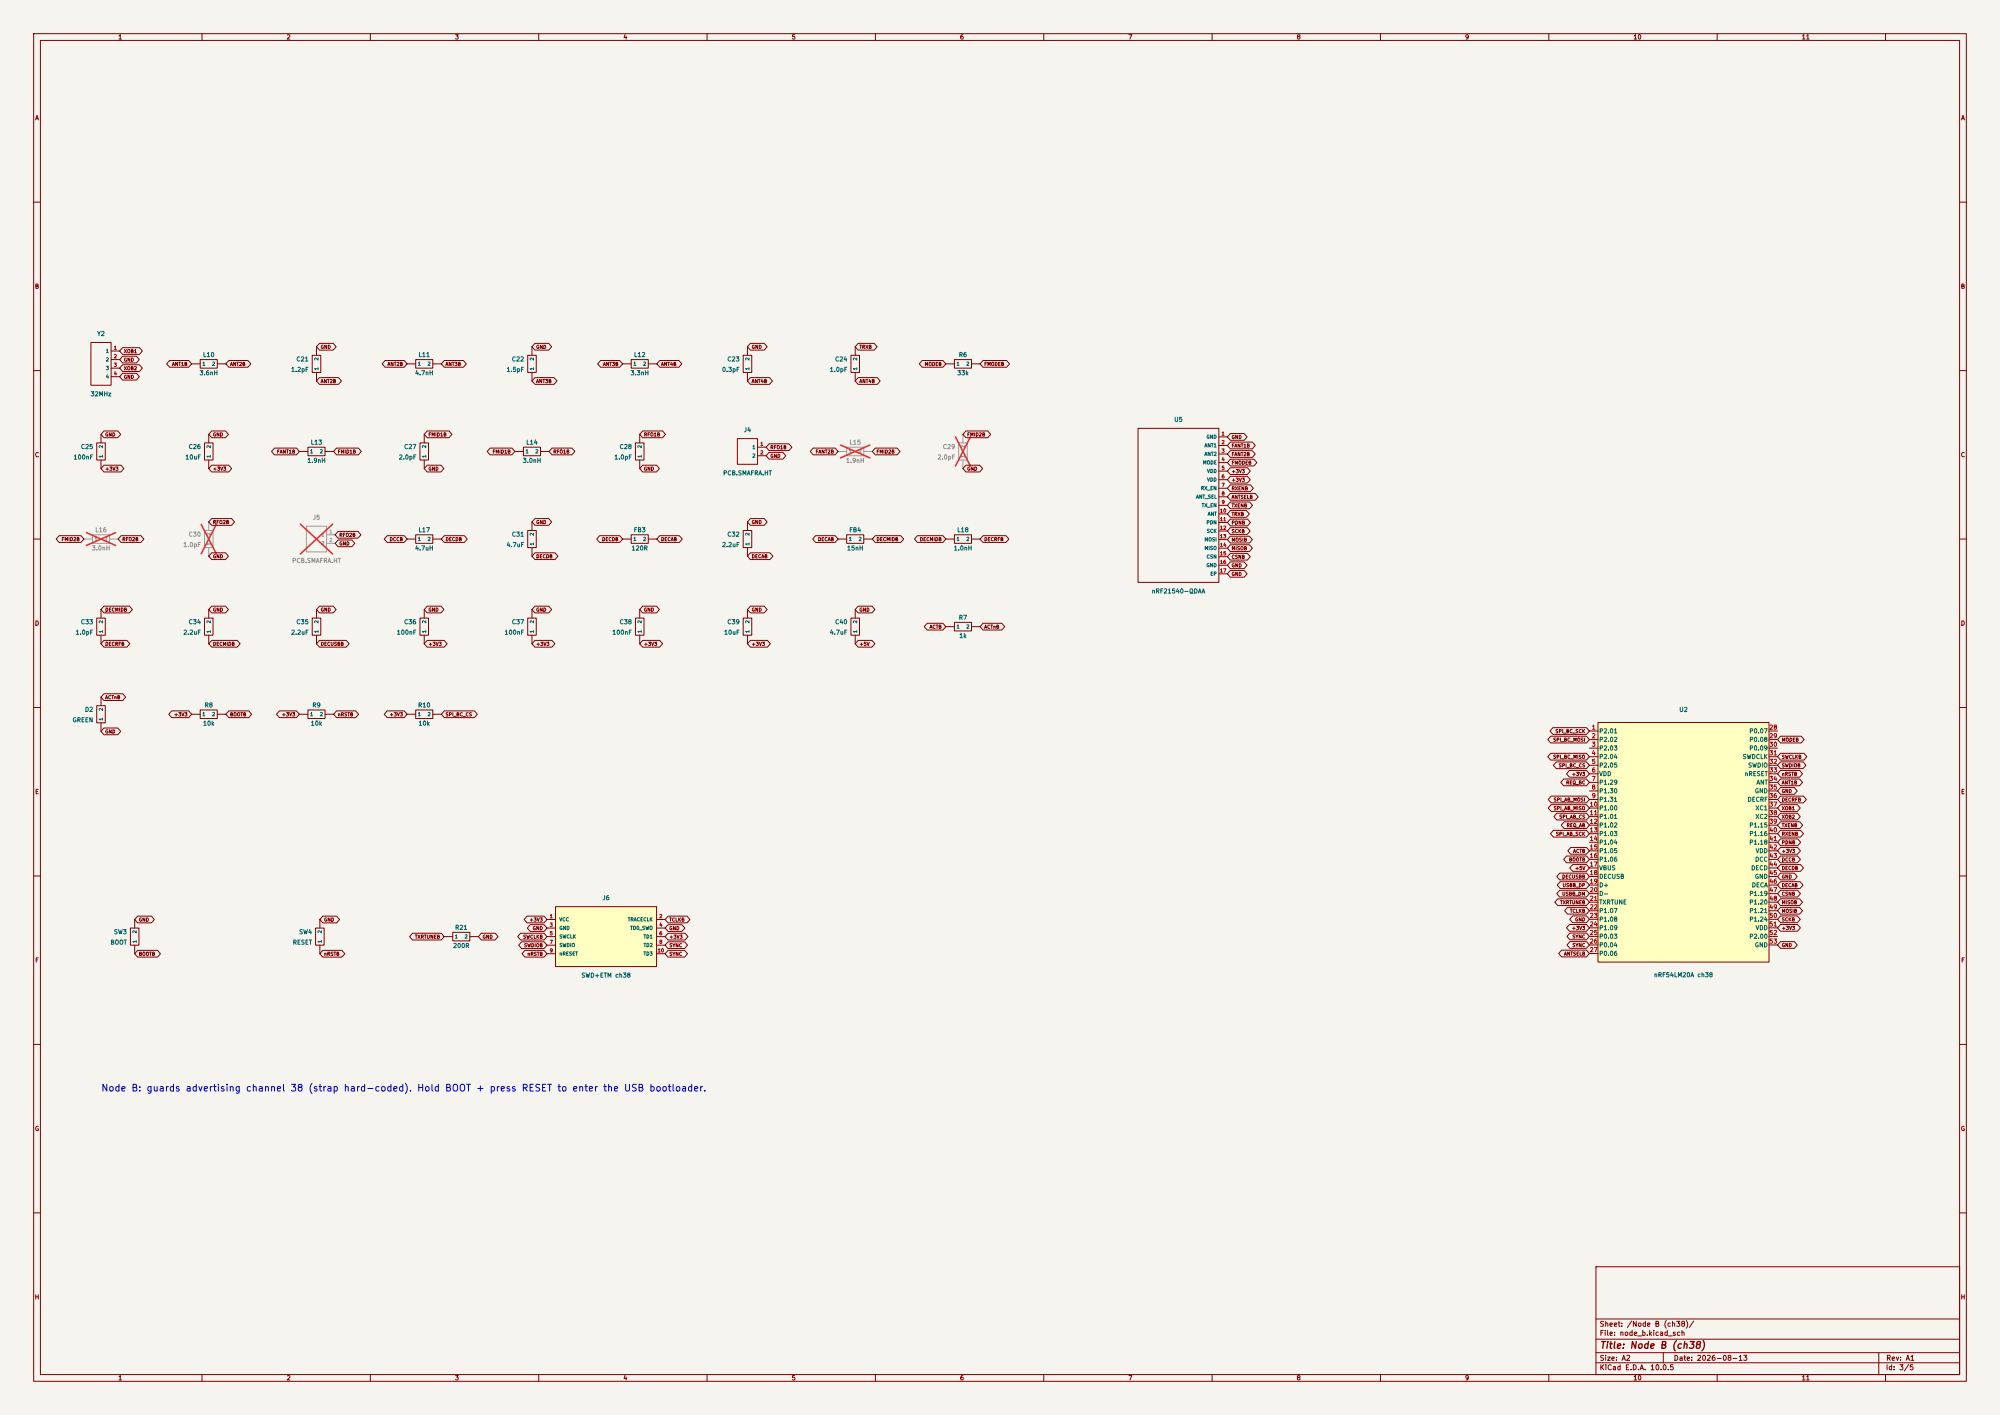
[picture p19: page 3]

+3V3 Node B: guards advertising channel 38 (strap hard-coded). Hold BOOT + press RESET to enter the USB bootloader.

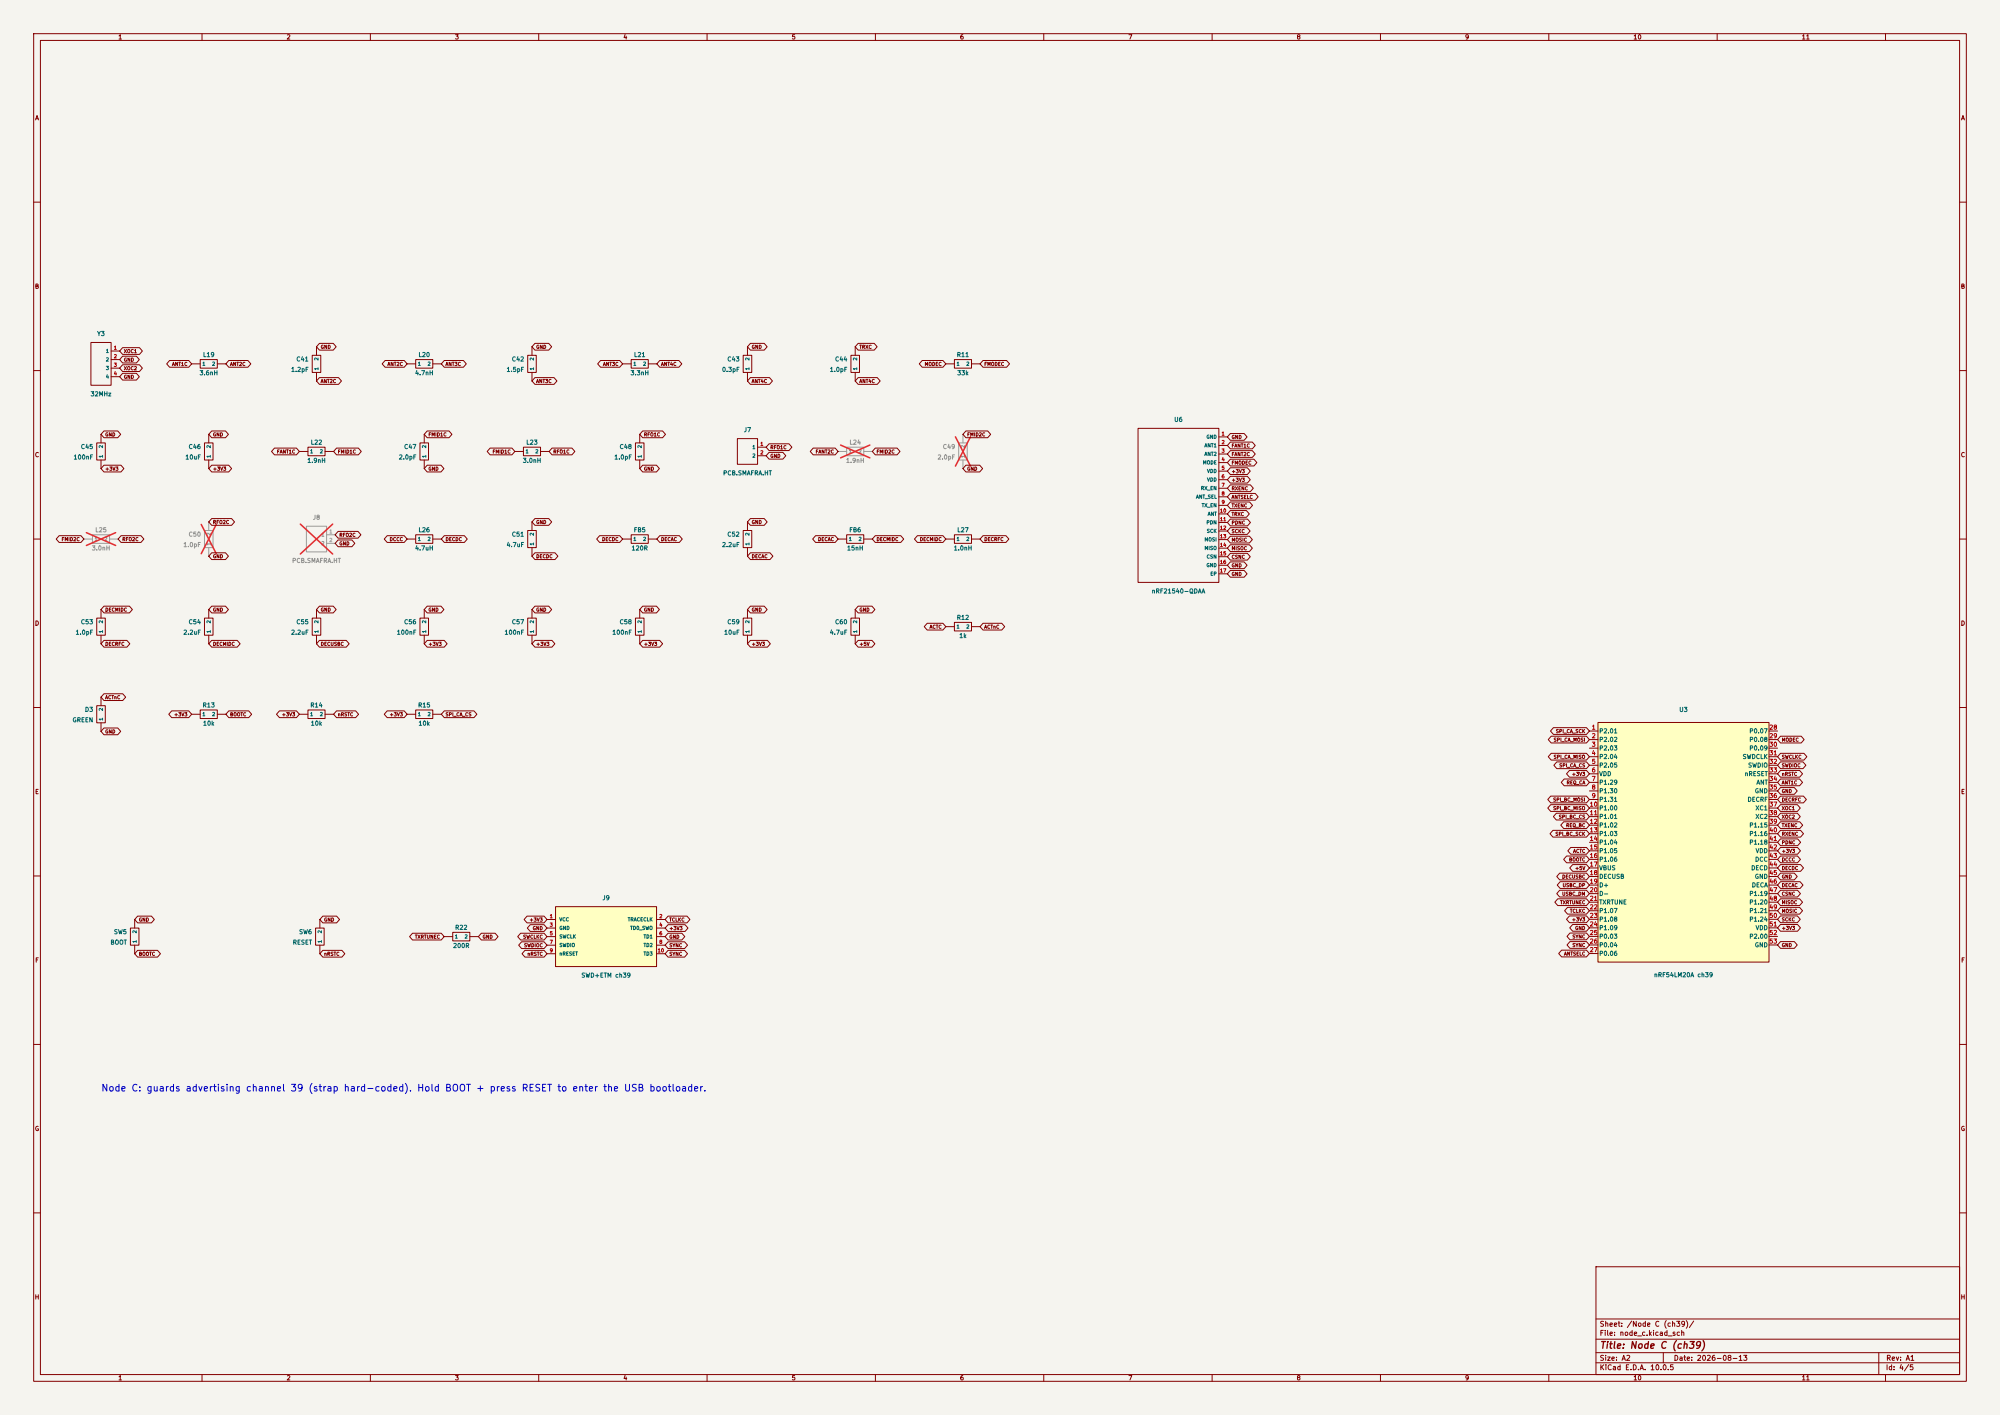
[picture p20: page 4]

+3V3 Node C: guards advertising channel 39 (strap hard-coded). Hold BOOT + press RESET to enter the USB bootloader.

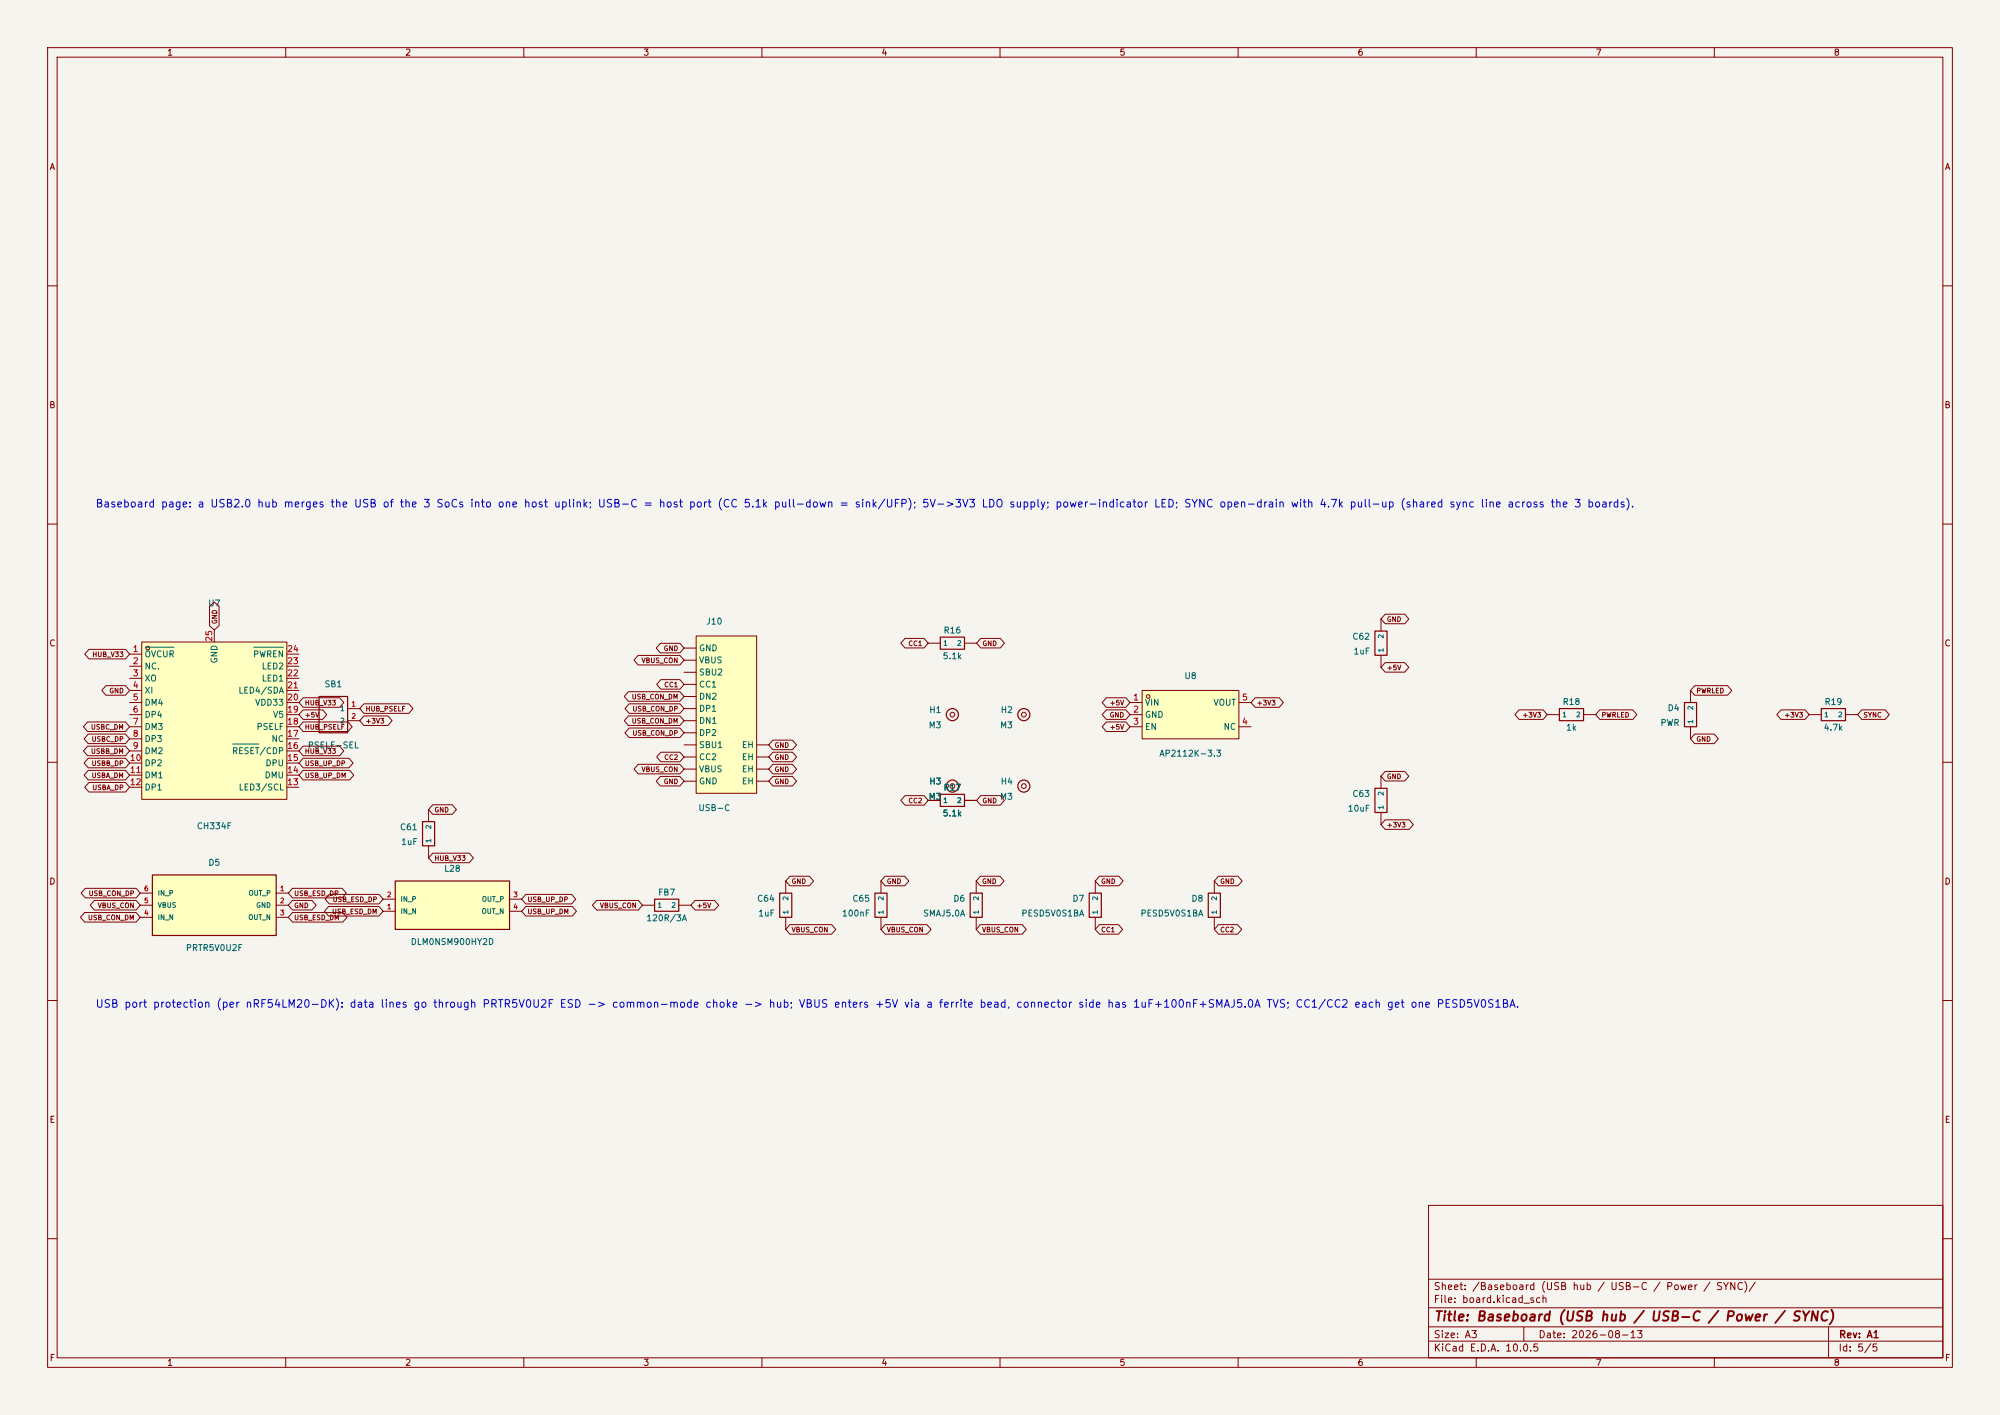
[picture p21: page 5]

CC2 Baseboard page: a USB2.0 hub merges the USB of the 3 SoCs into one host uplink; USB-C = host port (CC 5.1k pull-down = sink/UFP); 5V->3V3 LDO supply; power-indicator LED; SYNC open-drain with 4.7k pull-up (shared sync line across the 3 boards).

GND USBB_DP USBA_DM
GND USB_CON_DM
USB port protection (per nRF54LM20-DK): data lines go through PRTR5V0U2F ESD -> common-mode choke -> hub; VBUS enters +5V via a ferrite bead, connector side has 1uF+100nF+SMAJ5.0A TVS; CC1/CC2 each get one PESD5V0S1BA. R17
USBA_DP

Sheet: /Baseboard (USB hub / USB-C / Power / SYNC)/
File: board.kicad_sch
Title: Baseboard (USB hub / USB-C / Power / SYNC)

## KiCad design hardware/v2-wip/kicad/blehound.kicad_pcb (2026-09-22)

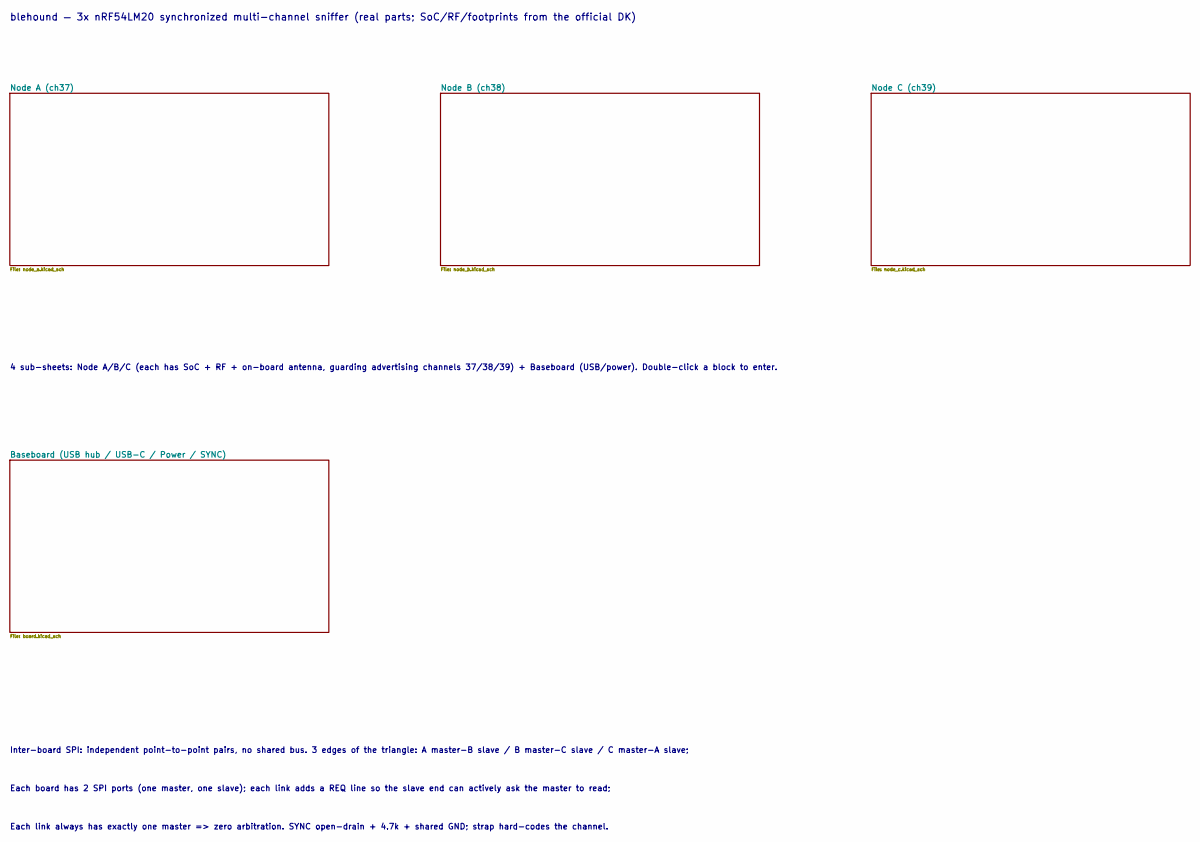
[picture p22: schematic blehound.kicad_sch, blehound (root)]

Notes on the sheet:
blehound — 3x nRF54LM20 synchronized multi-channel sniffer (real parts; SoC/RF/footprints from the official DK)
4 sub-sheets: Node A/B/C (each has SoC + RF + on-board antenna, guarding advertising channels 37/38/39) + Baseboard (USB/power). Double-click a block to enter.
Inter-board SPI: independent point-to-point pairs, no shared bus. 3 edges of the triangle: A master-B slave / B master-C slave / C master-A slave;
Each board has 2 SPI ports (one master, one slave); each link adds a REQ line so the slave end can actively ask the master to read;
Each link always has exactly one master => zero arbitration. SYNC open-drain + 4.7k + shared GND; strap hard-codes the channel.

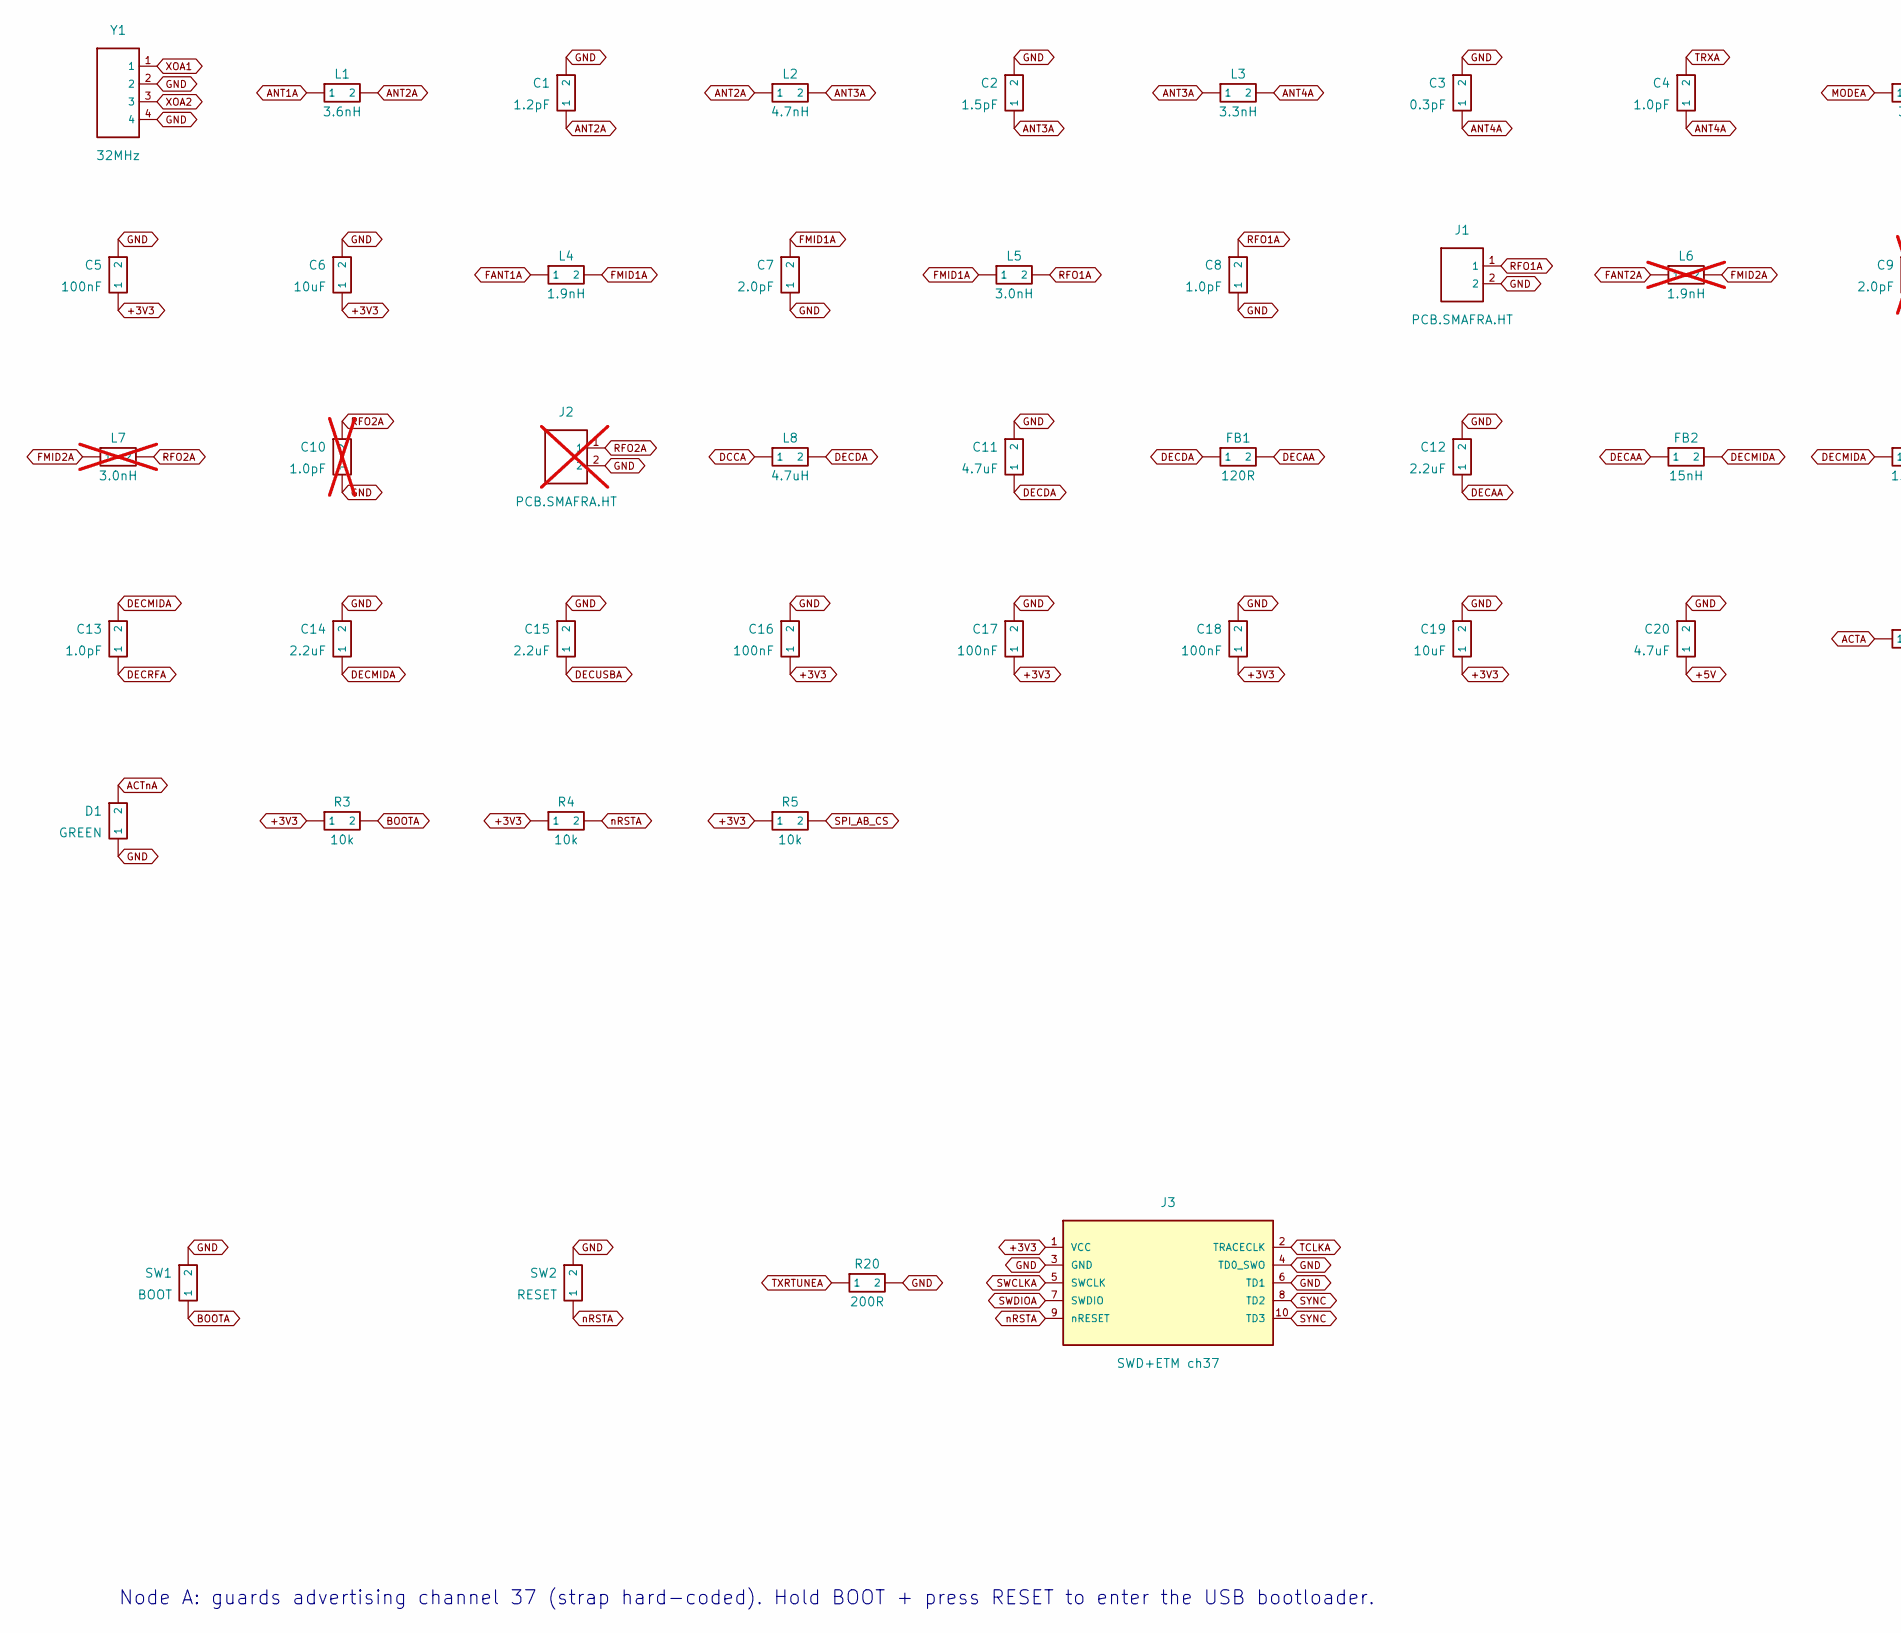
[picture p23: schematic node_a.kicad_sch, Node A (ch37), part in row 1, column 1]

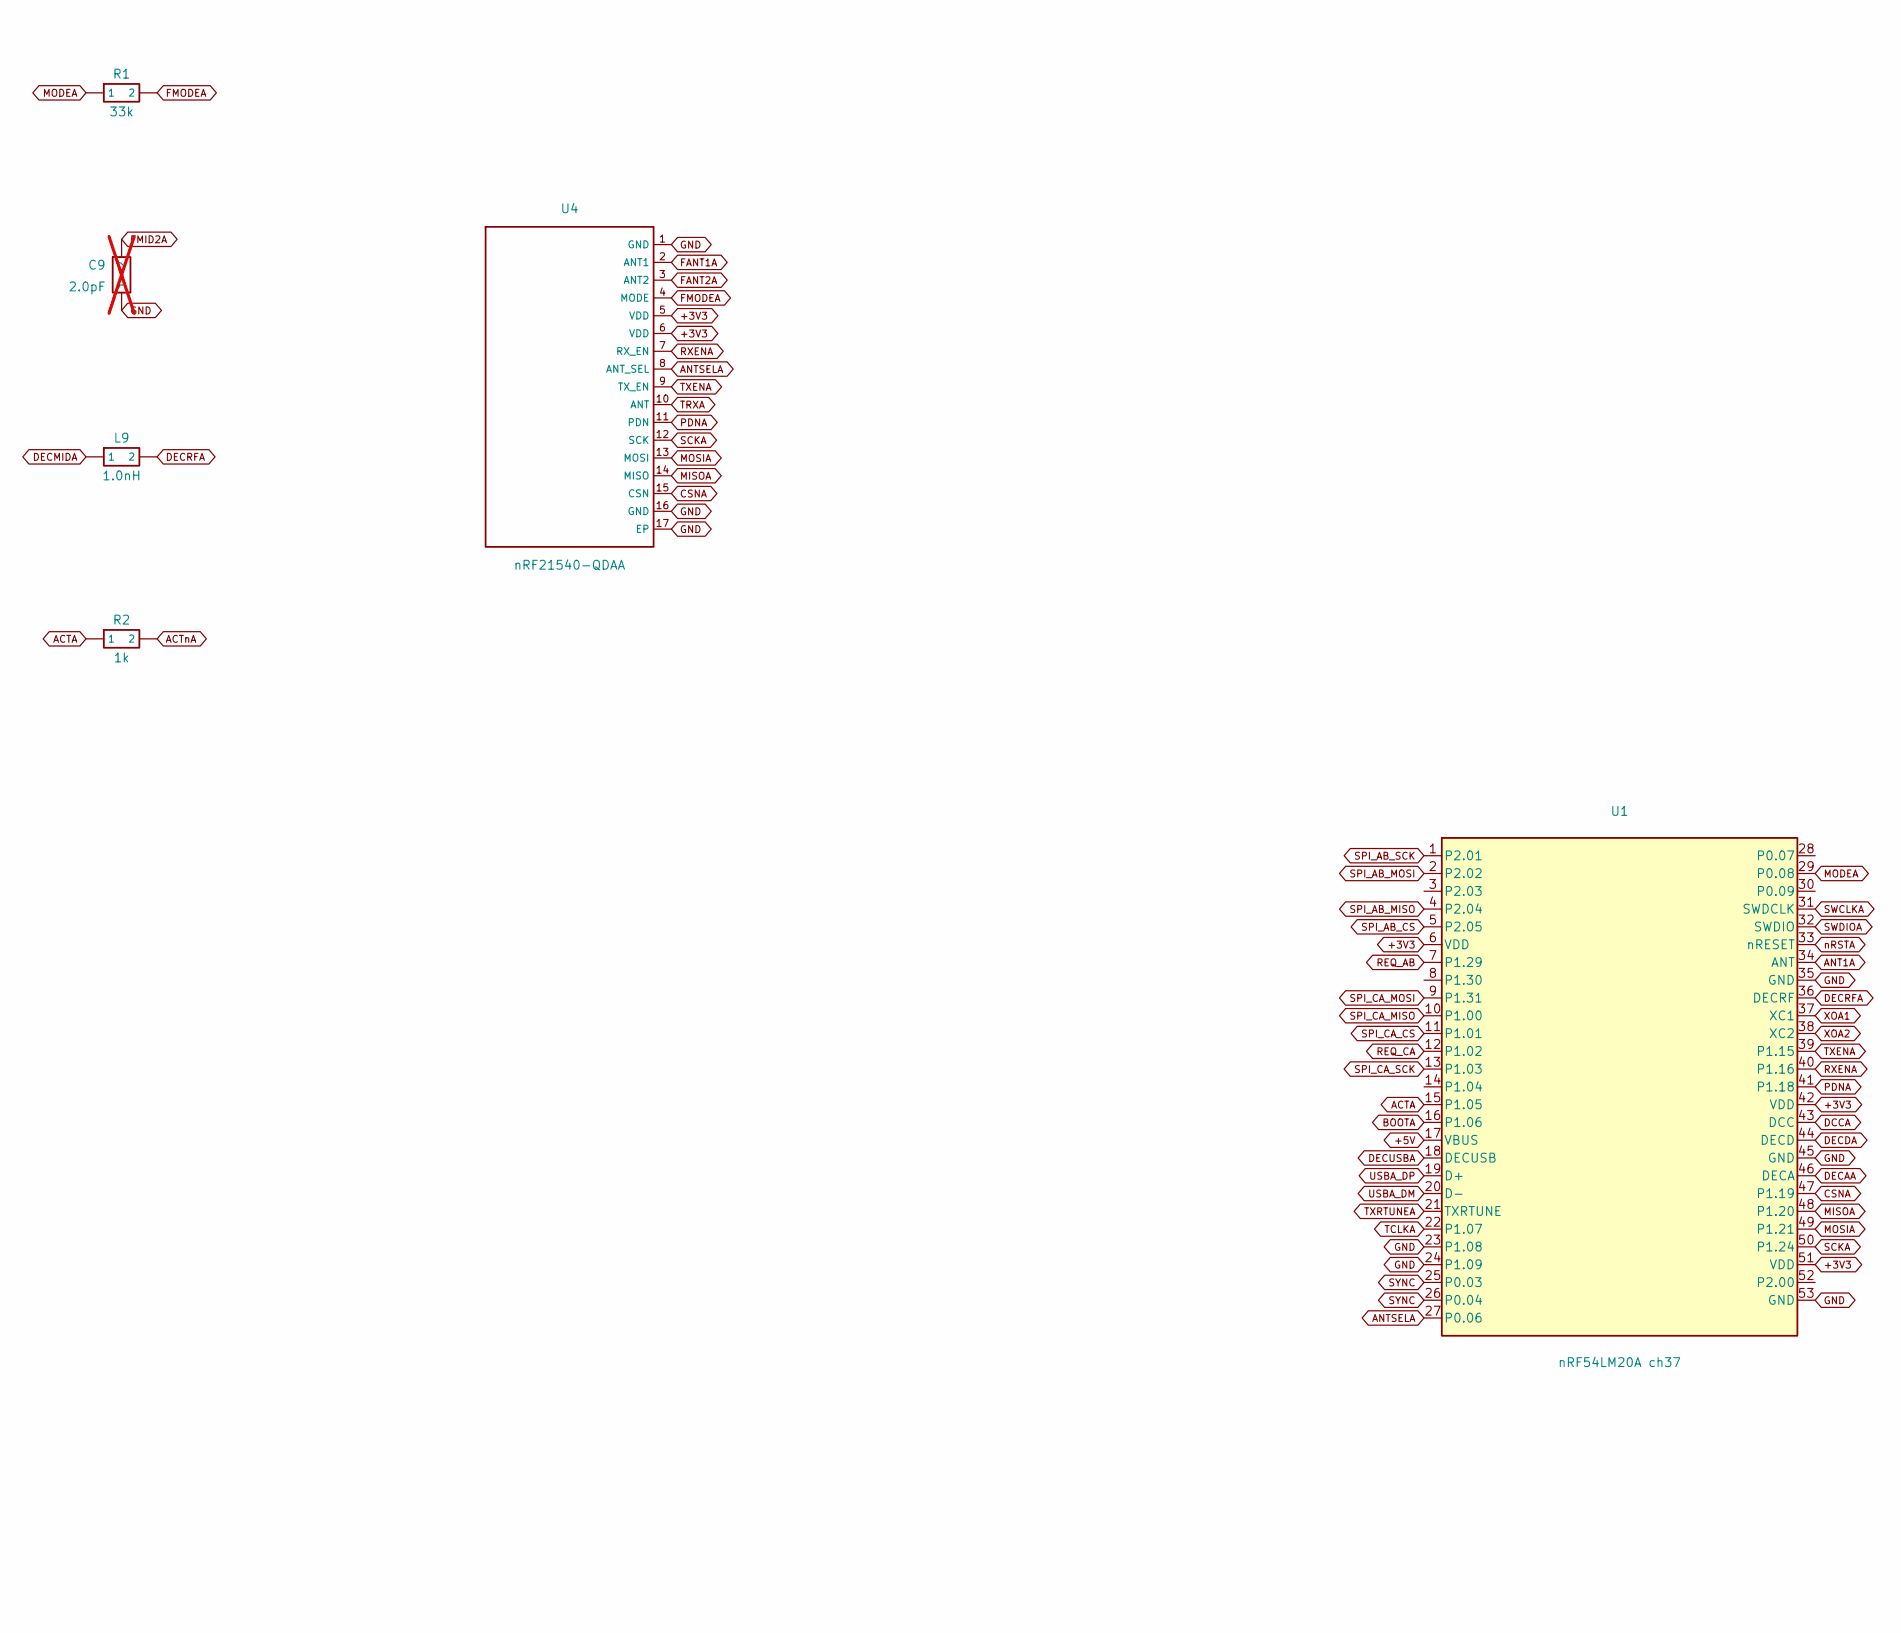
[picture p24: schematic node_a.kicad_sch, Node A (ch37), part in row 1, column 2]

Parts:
C1: 1.2pF; DK_C_0201_0603Metric
C2: 1.5pF; DK_C_0201_0603Metric
C3: 0.3pF; DK_C_0201_0603Metric
C4, C8, C13: 1.0pF; DK_C_0201_0603Metric
C5: 100nF; DK_C_0201_0603Metric
C6: 10uF; DK_C_0603_1608Metric
C7: 2.0pF; DK_C_0201_0603Metric
C9: 2.0pF; DK_C_0201_0603Metric; not fitted
C10: 1.0pF; DK_C_0201_0603Metric; not fitted
C11: 4.7uF; DK_C_0201_0603Metric
C12, C14, C15: 2.2uF; DK_C_0201_0603Metric
C16, C17, C18: 100nF; C_0402_1005Metric
C19: 10uF; C_0603_1608Metric
C20: 4.7uF; C_0603_1608Metric
D1: GREEN; LED_0603_1608Metric
FB1: 120R; DK_L_0201_0603Metric
FB2: 15nH; DK_L_0201_0603Metric
J1: PCB.SMAFRA.HT; SMA_RA_TH_PCBSMAFRA_HT
J2: PCB.SMAFRA.HT; SMA_RA_TH_PCBSMAFRA_HT; not fitted
J3: SWD+ETM ch37; PinHeader_2x05_P2.54mm_Vertical
L1: 3.6nH; DK_L_0201_0603Metric
L2: 4.7nH; DK_L_0201_0603Metric
L3: 3.3nH; DK_L_0201_0603Metric
L4: 1.9nH; DK_L_0201_0603Metric
L5: 3.0nH; DK_L_0201_0603Metric
L6: 1.9nH; DK_L_0201_0603Metric; not fitted
L7: 3.0nH; DK_L_0201_0603Metric; not fitted
L8: 4.7uH; DK_L_0603_1608Metric
L9: 1.0nH; DK_L_0201_0603Metric
R1: 33k; DK_R_0201_0603Metric
R2: 1k; R_0402_1005Metric
R3, R4, R5: 10k; R_0402_1005Metric
R20: 200R; R_0402_1005Metric
SW1: BOOT; SW_SPST_SKQG_WithoutStem
SW2: RESET; SW_SPST_SKQG_WithoutStem
U1: nRF54LM20A ch37; nRF54LM20A_QFN52_6x6mm_P0.4mm_EP4.7x4.7mm
U4: nRF21540-QDAA; nRF21540_QFN16_4x4mm_P0.65mm_EP2.65
Y1: 32MHz; DK_Crystal_32MHz

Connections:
+3V3: C5.1, C6.1, C16.1, C17.1, C18.1, C19.1, J3.1 (VCC), R3.1, R4.1, R5.1, U1.6 (VDD), U1.42 (VDD), U1.51 (VDD), U4.5 (VDD), U4.6 (VDD); also elsewhere on the board
+5V: C20.1, U1.17 (VBUS); also elsewhere on the board
ACTA: R2.1, U1.15 (P1.05)
ACTnA: D1.2, R2.2
ANT1A: L1.1, U1.34 (ANT)
ANT2A: C1.1, L1.2, L2.1
ANT3A: C2.1, L2.2, L3.1
ANT4A: C3.1, C4.1, L3.2
ANTSELA: U1.27 (P0.06), U4.8 (ANT_SEL)
BOOTA: R3.2, SW1.1, U1.16 (P1.06)
CSNA: U1.47 (P1.19), U4.15 (CSN)
DCCA: L8.1, U1.43 (DCC)
DECAA: C12.1, FB1.2, FB2.1, U1.46 (DECA)
DECDA: C11.1, FB1.1, L8.2, U1.44 (DECD)
DECMIDA: C13.2, C14.1, FB2.2, L9.1
DECRFA: C13.1, L9.2, U1.36 (DECRF)
DECUSBA: C15.1, U1.18 (DECUSB)
FANT1A: L4.1, U4.2 (ANT1)
FANT2A: L6.1, U4.3 (ANT2)
FMID1A: C7.2, L4.2, L5.1
FMID2A: C9.2, L6.2, L7.1
FMODEA: R1.2, U4.4 (MODE)
GND: C1.2, C2.2, C3.2, C5.2, C6.2, C7.1, C8.1, C9.1, C10.1, C11.2, C12.2, C14.2, C15.2, C16.2, C17.2, C18.2, C19.2, C20.2, D1.1, J1.2, J2.2, J3.3 (GND), J3.4 (TD0_SWO), J3.6 (TD1), R20.2, SW1.2, SW2.2, U1.23 (P1.08), U1.24 (P1.09), U1.35 (GND), U1.45 (GND), U1.53 (GND), U4.1 (GND), U4.16 (GND), U4.17 (EP), Y1.2, Y1.4; also elsewhere on the board
MISOA: U1.48 (P1.20), U4.14 (MISO)
MODEA: R1.1, U1.29 (P0.08)
MOSIA: U1.49 (P1.21), U4.13 (MOSI)
PDNA: U1.41 (P1.18), U4.11 (PDN)
REQ_AB: U1.7 (P1.29); also elsewhere on the board
REQ_CA: U1.12 (P1.02); also elsewhere on the board
RFO1A: C8.2, J1.1, L5.2
RFO2A: C10.2, J2.1, L7.2
RXENA: U1.40 (P1.16), U4.7 (RX_EN)
SCKA: U1.50 (P1.24), U4.12 (SCK)
SPI_AB_CS: R5.2, U1.5 (P2.05); also elsewhere on the board
SPI_AB_MISO: U1.4 (P2.04); also elsewhere on the board
SPI_AB_MOSI: U1.2 (P2.02); also elsewhere on the board
SPI_AB_SCK: U1.1 (P2.01); also elsewhere on the board
SPI_CA_CS: U1.11 (P1.01); also elsewhere on the board
SPI_CA_MISO: U1.10 (P1.00); also elsewhere on the board
SPI_CA_MOSI: U1.9 (P1.31); also elsewhere on the board
SPI_CA_SCK: U1.13 (P1.03); also elsewhere on the board
SWCLKA: J3.5 (SWCLK), U1.31 (SWDCLK)
SWDIOA: J3.7 (SWDIO), U1.32 (SWDIO)
SYNC: J3.8 (TD2), J3.10 (TD3), U1.25 (P0.03), U1.26 (P0.04); also elsewhere on the board
TCLKA: J3.2 (TRACECLK), U1.22 (P1.07)
TRXA: C4.2, U4.10 (ANT)
TXENA: U1.39 (P1.15), U4.9 (TX_EN)
TXRTUNEA: R20.1, U1.21 (TXRTUNE)
USBA_DM: U1.20 (D-); also elsewhere on the board
USBA_DP: U1.19 (D+); also elsewhere on the board
XOA1: U1.37 (XC1), Y1.1
XOA2: U1.38 (XC2), Y1.3
nRSTA: J3.9 (nRESET), R4.2, SW2.1, U1.33 (nRESET)

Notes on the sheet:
Node A: guards advertising channel 37 (strap hard-coded). Hold BOOT + press RESET to enter the USB bootloader.

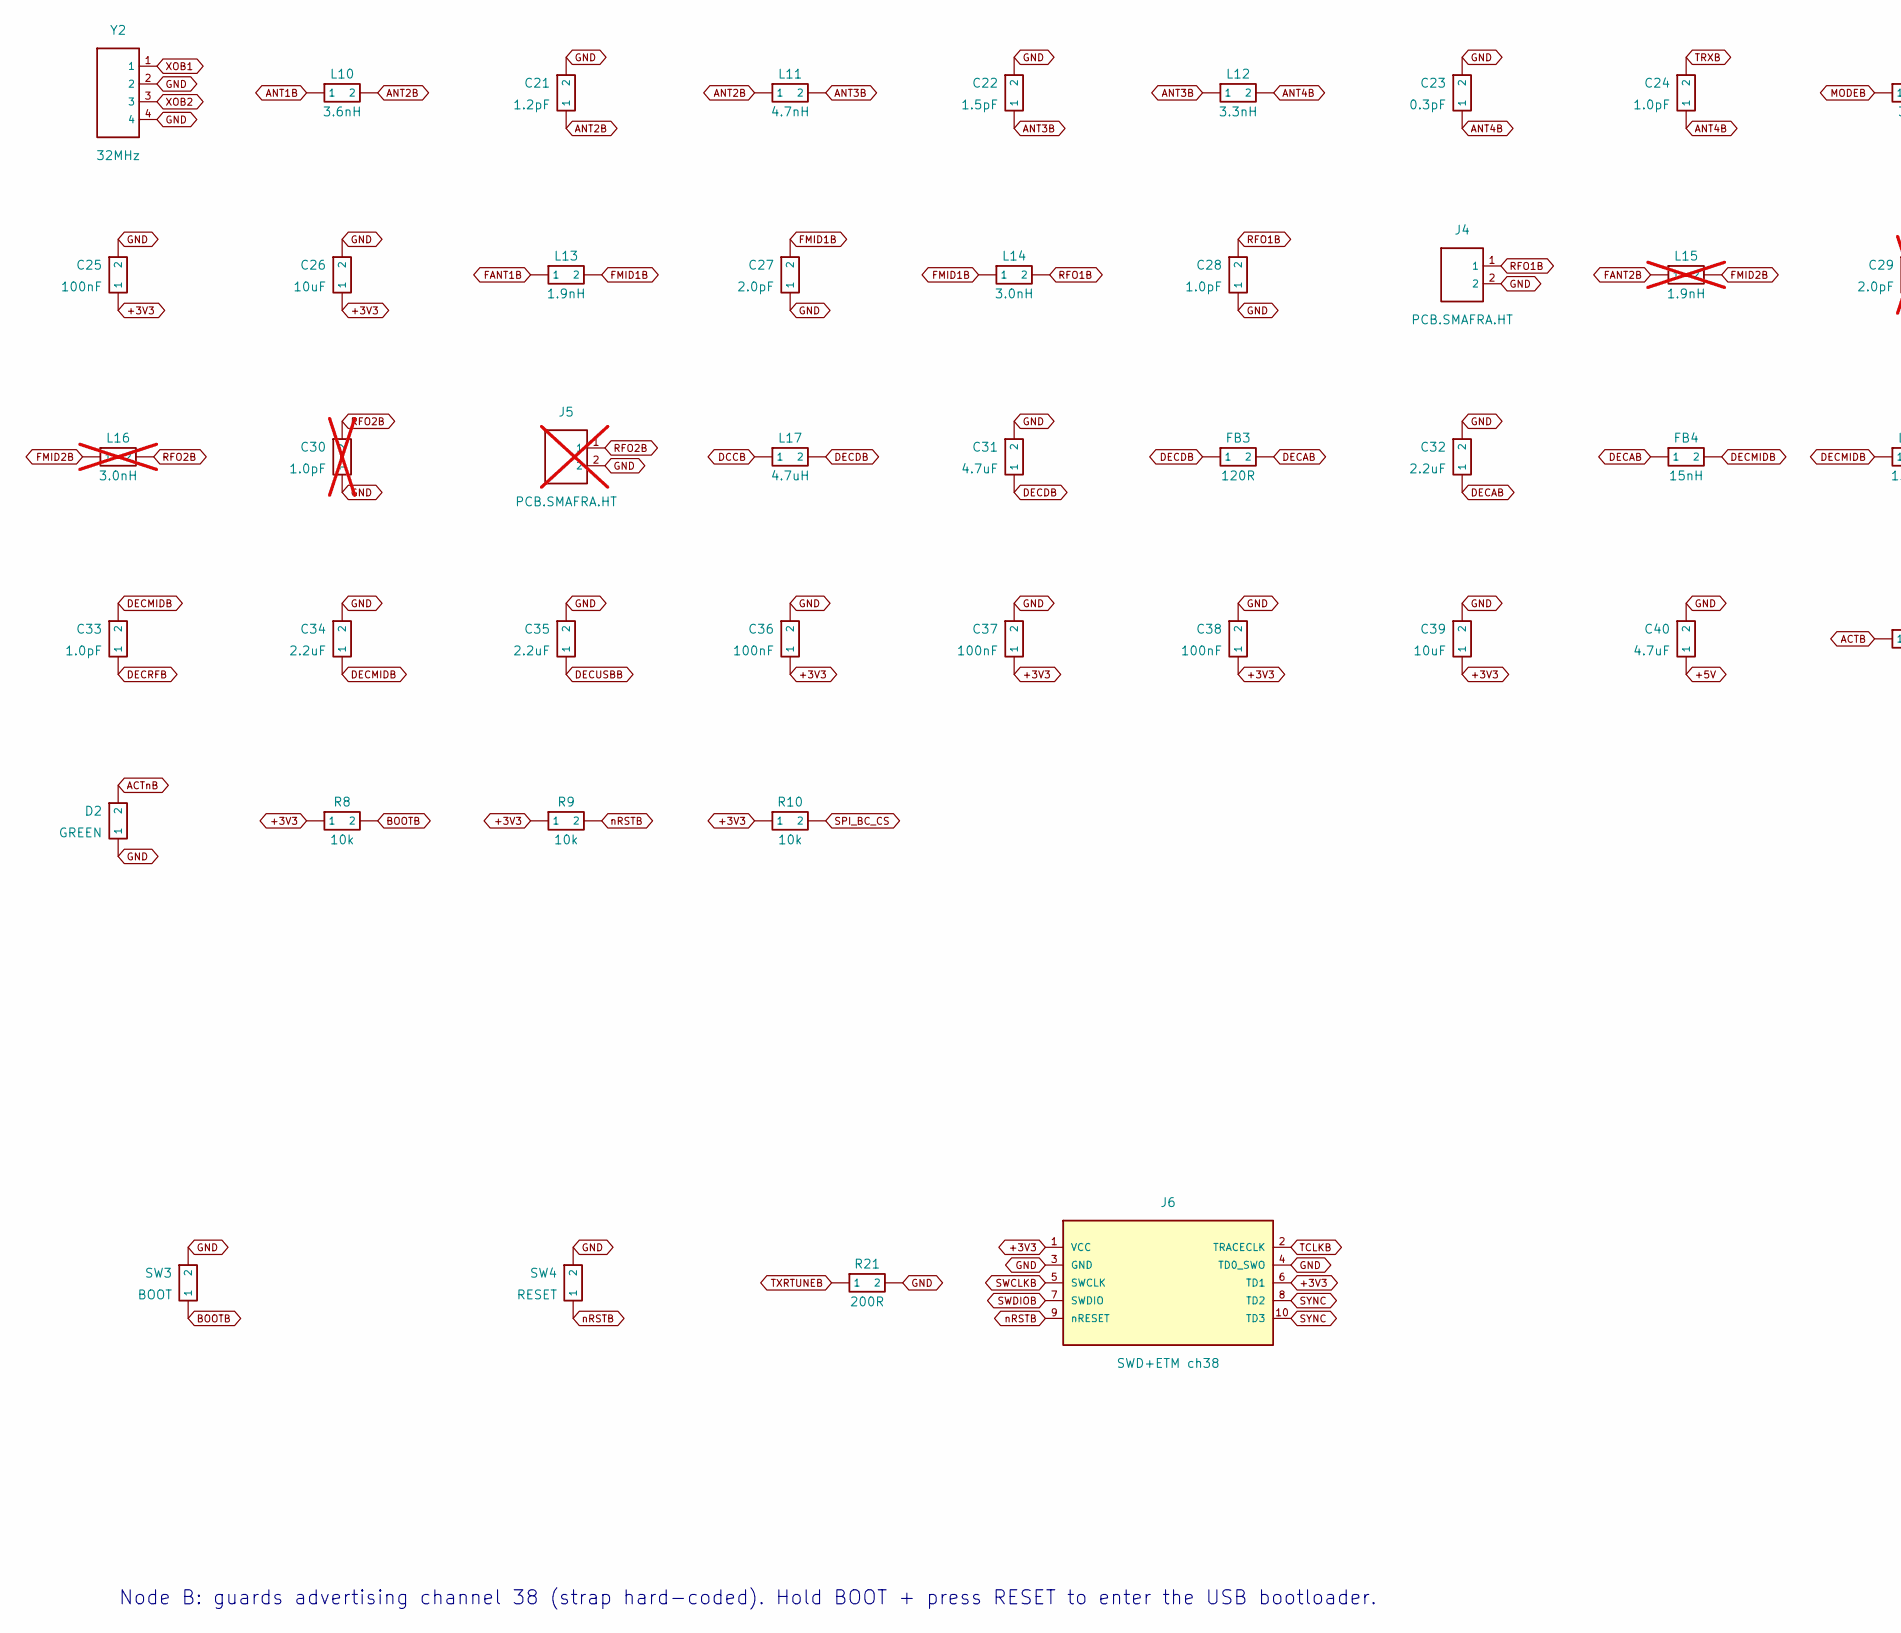
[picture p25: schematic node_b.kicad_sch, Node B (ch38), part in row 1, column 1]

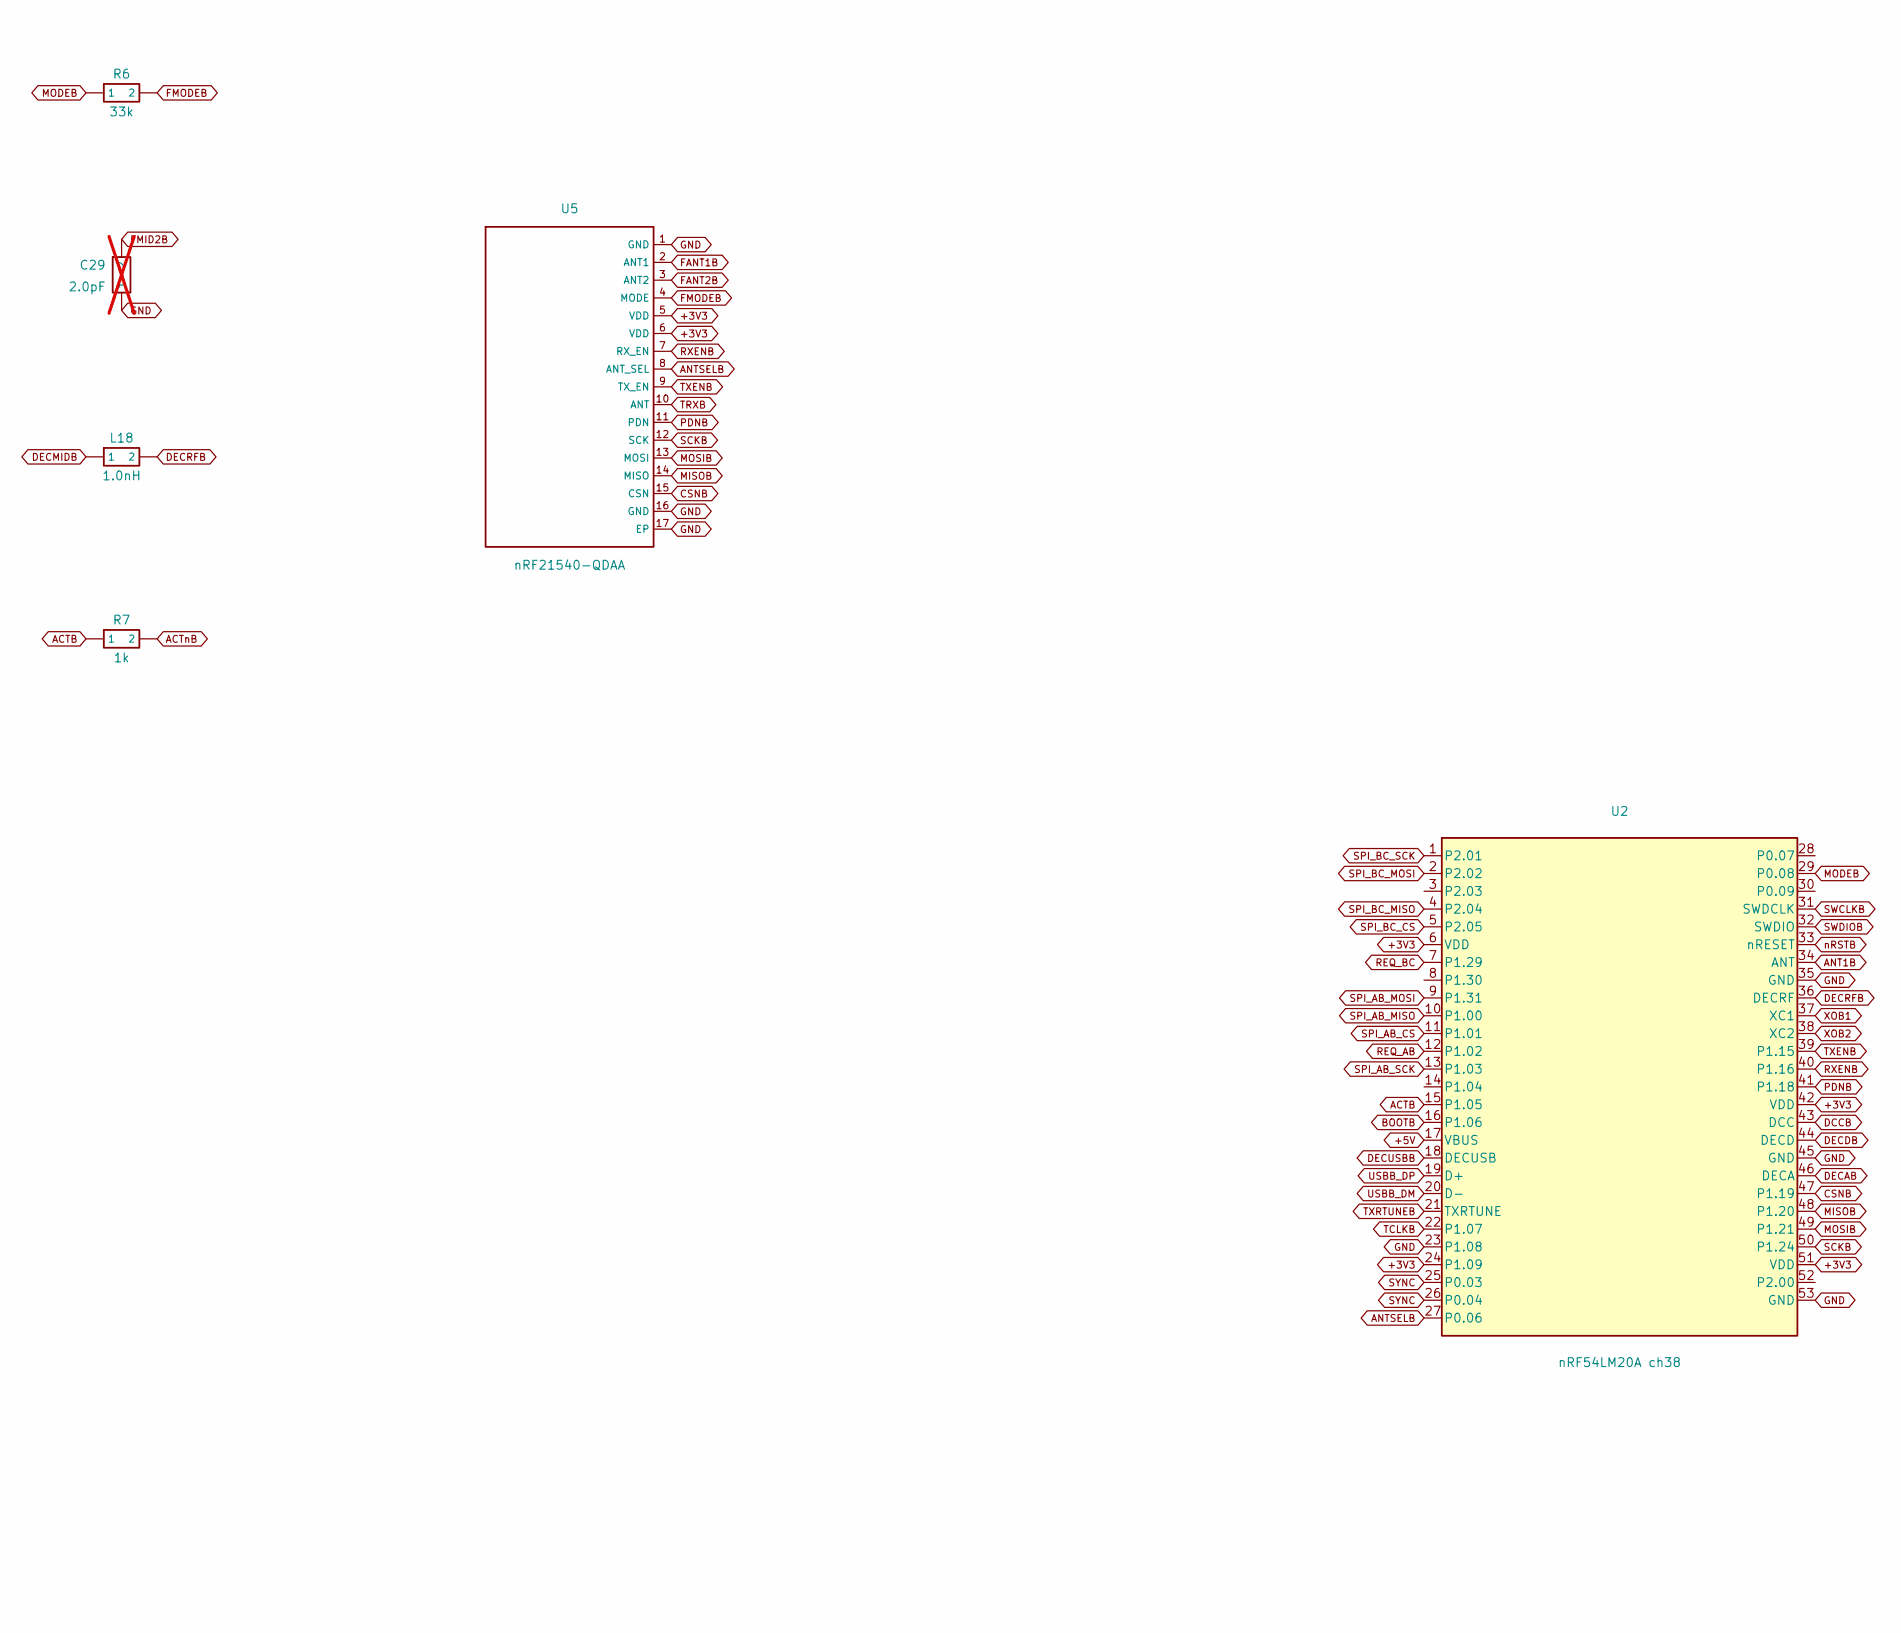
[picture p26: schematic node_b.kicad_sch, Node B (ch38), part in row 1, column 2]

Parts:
C21: 1.2pF; DK_C_0201_0603Metric
C22: 1.5pF; DK_C_0201_0603Metric
C23: 0.3pF; DK_C_0201_0603Metric
C24, C28, C33: 1.0pF; DK_C_0201_0603Metric
C25: 100nF; DK_C_0201_0603Metric
C26: 10uF; DK_C_0603_1608Metric
C27: 2.0pF; DK_C_0201_0603Metric
C29: 2.0pF; DK_C_0201_0603Metric; not fitted
C30: 1.0pF; DK_C_0201_0603Metric; not fitted
C31: 4.7uF; DK_C_0201_0603Metric
C32, C34, C35: 2.2uF; DK_C_0201_0603Metric
C36, C37, C38: 100nF; C_0402_1005Metric
C39: 10uF; C_0603_1608Metric
C40: 4.7uF; C_0603_1608Metric
D2: GREEN; LED_0603_1608Metric
FB3: 120R; DK_L_0201_0603Metric
FB4: 15nH; DK_L_0201_0603Metric
J4: PCB.SMAFRA.HT; SMA_RA_TH_PCBSMAFRA_HT
J5: PCB.SMAFRA.HT; SMA_RA_TH_PCBSMAFRA_HT; not fitted
J6: SWD+ETM ch38; PinHeader_2x05_P2.54mm_Vertical
L10: 3.6nH; DK_L_0201_0603Metric
L11: 4.7nH; DK_L_0201_0603Metric
L12: 3.3nH; DK_L_0201_0603Metric
L13: 1.9nH; DK_L_0201_0603Metric
L14: 3.0nH; DK_L_0201_0603Metric
L15: 1.9nH; DK_L_0201_0603Metric; not fitted
L16: 3.0nH; DK_L_0201_0603Metric; not fitted
L17: 4.7uH; DK_L_0603_1608Metric
L18: 1.0nH; DK_L_0201_0603Metric
R6: 33k; DK_R_0201_0603Metric
R7: 1k; R_0402_1005Metric
R8, R9, R10: 10k; R_0402_1005Metric
R21: 200R; R_0402_1005Metric
SW3: BOOT; SW_SPST_SKQG_WithoutStem
SW4: RESET; SW_SPST_SKQG_WithoutStem
U2: nRF54LM20A ch38; nRF54LM20A_QFN52_6x6mm_P0.4mm_EP4.7x4.7mm
U5: nRF21540-QDAA; nRF21540_QFN16_4x4mm_P0.65mm_EP2.65
Y2: 32MHz; DK_Crystal_32MHz

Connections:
+3V3: C25.1, C26.1, C36.1, C37.1, C38.1, C39.1, J6.1 (VCC), J6.6 (TD1), R8.1, R9.1, R10.1, U2.6 (VDD), U2.24 (P1.09), U2.42 (VDD), U2.51 (VDD), U5.5 (VDD), U5.6 (VDD); also elsewhere on the board
+5V: C40.1, U2.17 (VBUS); also elsewhere on the board
ACTB: R7.1, U2.15 (P1.05)
ACTnB: D2.2, R7.2
ANT1B: L10.1, U2.34 (ANT)
ANT2B: C21.1, L10.2, L11.1
ANT3B: C22.1, L11.2, L12.1
ANT4B: C23.1, C24.1, L12.2
ANTSELB: U2.27 (P0.06), U5.8 (ANT_SEL)
BOOTB: R8.2, SW3.1, U2.16 (P1.06)
CSNB: U2.47 (P1.19), U5.15 (CSN)
DCCB: L17.1, U2.43 (DCC)
DECAB: C32.1, FB3.2, FB4.1, U2.46 (DECA)
DECDB: C31.1, FB3.1, L17.2, U2.44 (DECD)
DECMIDB: C33.2, C34.1, FB4.2, L18.1
DECRFB: C33.1, L18.2, U2.36 (DECRF)
DECUSBB: C35.1, U2.18 (DECUSB)
FANT1B: L13.1, U5.2 (ANT1)
FANT2B: L15.1, U5.3 (ANT2)
FMID1B: C27.2, L13.2, L14.1
FMID2B: C29.2, L15.2, L16.1
FMODEB: R6.2, U5.4 (MODE)
GND: C21.2, C22.2, C23.2, C25.2, C26.2, C27.1, C28.1, C29.1, C30.1, C31.2, C32.2, C34.2, C35.2, C36.2, C37.2, C38.2, C39.2, C40.2, D2.1, J4.2, J5.2, J6.3 (GND), J6.4 (TD0_SWO), R21.2, SW3.2, SW4.2, U2.23 (P1.08), U2.35 (GND), U2.45 (GND), U2.53 (GND), U5.1 (GND), U5.16 (GND), U5.17 (EP), Y2.2, Y2.4; also elsewhere on the board
MISOB: U2.48 (P1.20), U5.14 (MISO)
MODEB: R6.1, U2.29 (P0.08)
MOSIB: U2.49 (P1.21), U5.13 (MOSI)
PDNB: U2.41 (P1.18), U5.11 (PDN)
REQ_AB: U2.12 (P1.02); also elsewhere on the board
REQ_BC: U2.7 (P1.29); also elsewhere on the board
RFO1B: C28.2, J4.1, L14.2
RFO2B: C30.2, J5.1, L16.2
RXENB: U2.40 (P1.16), U5.7 (RX_EN)
SCKB: U2.50 (P1.24), U5.12 (SCK)
SPI_AB_CS: U2.11 (P1.01); also elsewhere on the board
SPI_AB_MISO: U2.10 (P1.00); also elsewhere on the board
SPI_AB_MOSI: U2.9 (P1.31); also elsewhere on the board
SPI_AB_SCK: U2.13 (P1.03); also elsewhere on the board
SPI_BC_CS: R10.2, U2.5 (P2.05); also elsewhere on the board
SPI_BC_MISO: U2.4 (P2.04); also elsewhere on the board
SPI_BC_MOSI: U2.2 (P2.02); also elsewhere on the board
SPI_BC_SCK: U2.1 (P2.01); also elsewhere on the board
SWCLKB: J6.5 (SWCLK), U2.31 (SWDCLK)
SWDIOB: J6.7 (SWDIO), U2.32 (SWDIO)
SYNC: J6.8 (TD2), J6.10 (TD3), U2.25 (P0.03), U2.26 (P0.04); also elsewhere on the board
TCLKB: J6.2 (TRACECLK), U2.22 (P1.07)
TRXB: C24.2, U5.10 (ANT)
TXENB: U2.39 (P1.15), U5.9 (TX_EN)
TXRTUNEB: R21.1, U2.21 (TXRTUNE)
USBB_DM: U2.20 (D-); also elsewhere on the board
USBB_DP: U2.19 (D+); also elsewhere on the board
XOB1: U2.37 (XC1), Y2.1
XOB2: U2.38 (XC2), Y2.3
nRSTB: J6.9 (nRESET), R9.2, SW4.1, U2.33 (nRESET)

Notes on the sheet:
Node B: guards advertising channel 38 (strap hard-coded). Hold BOOT + press RESET to enter the USB bootloader.

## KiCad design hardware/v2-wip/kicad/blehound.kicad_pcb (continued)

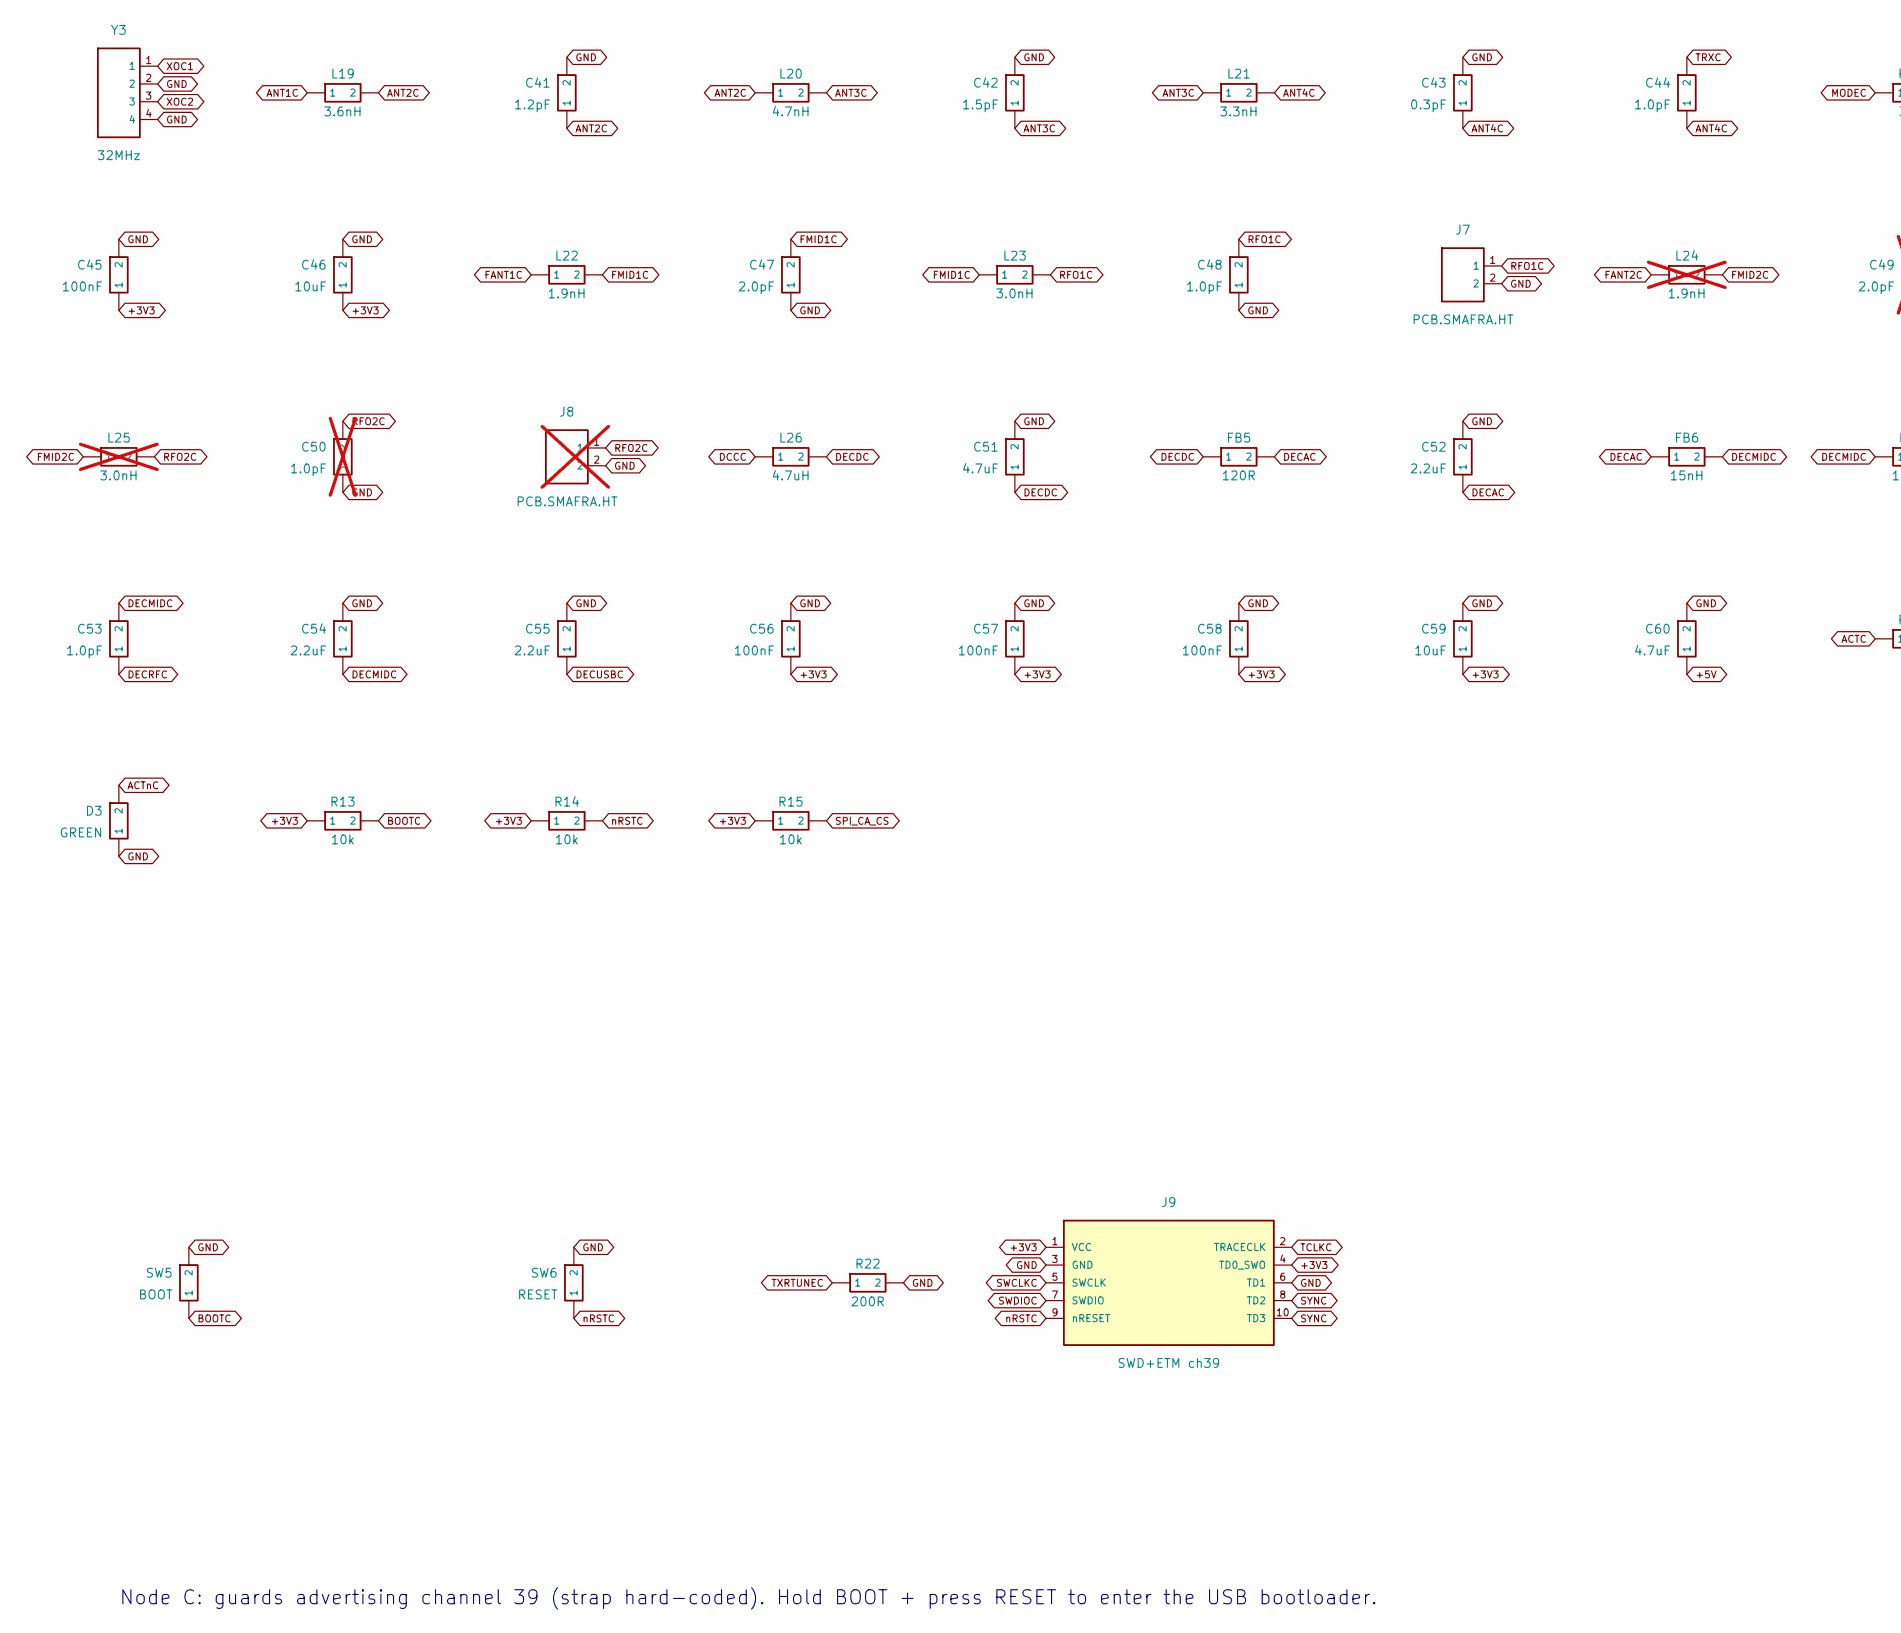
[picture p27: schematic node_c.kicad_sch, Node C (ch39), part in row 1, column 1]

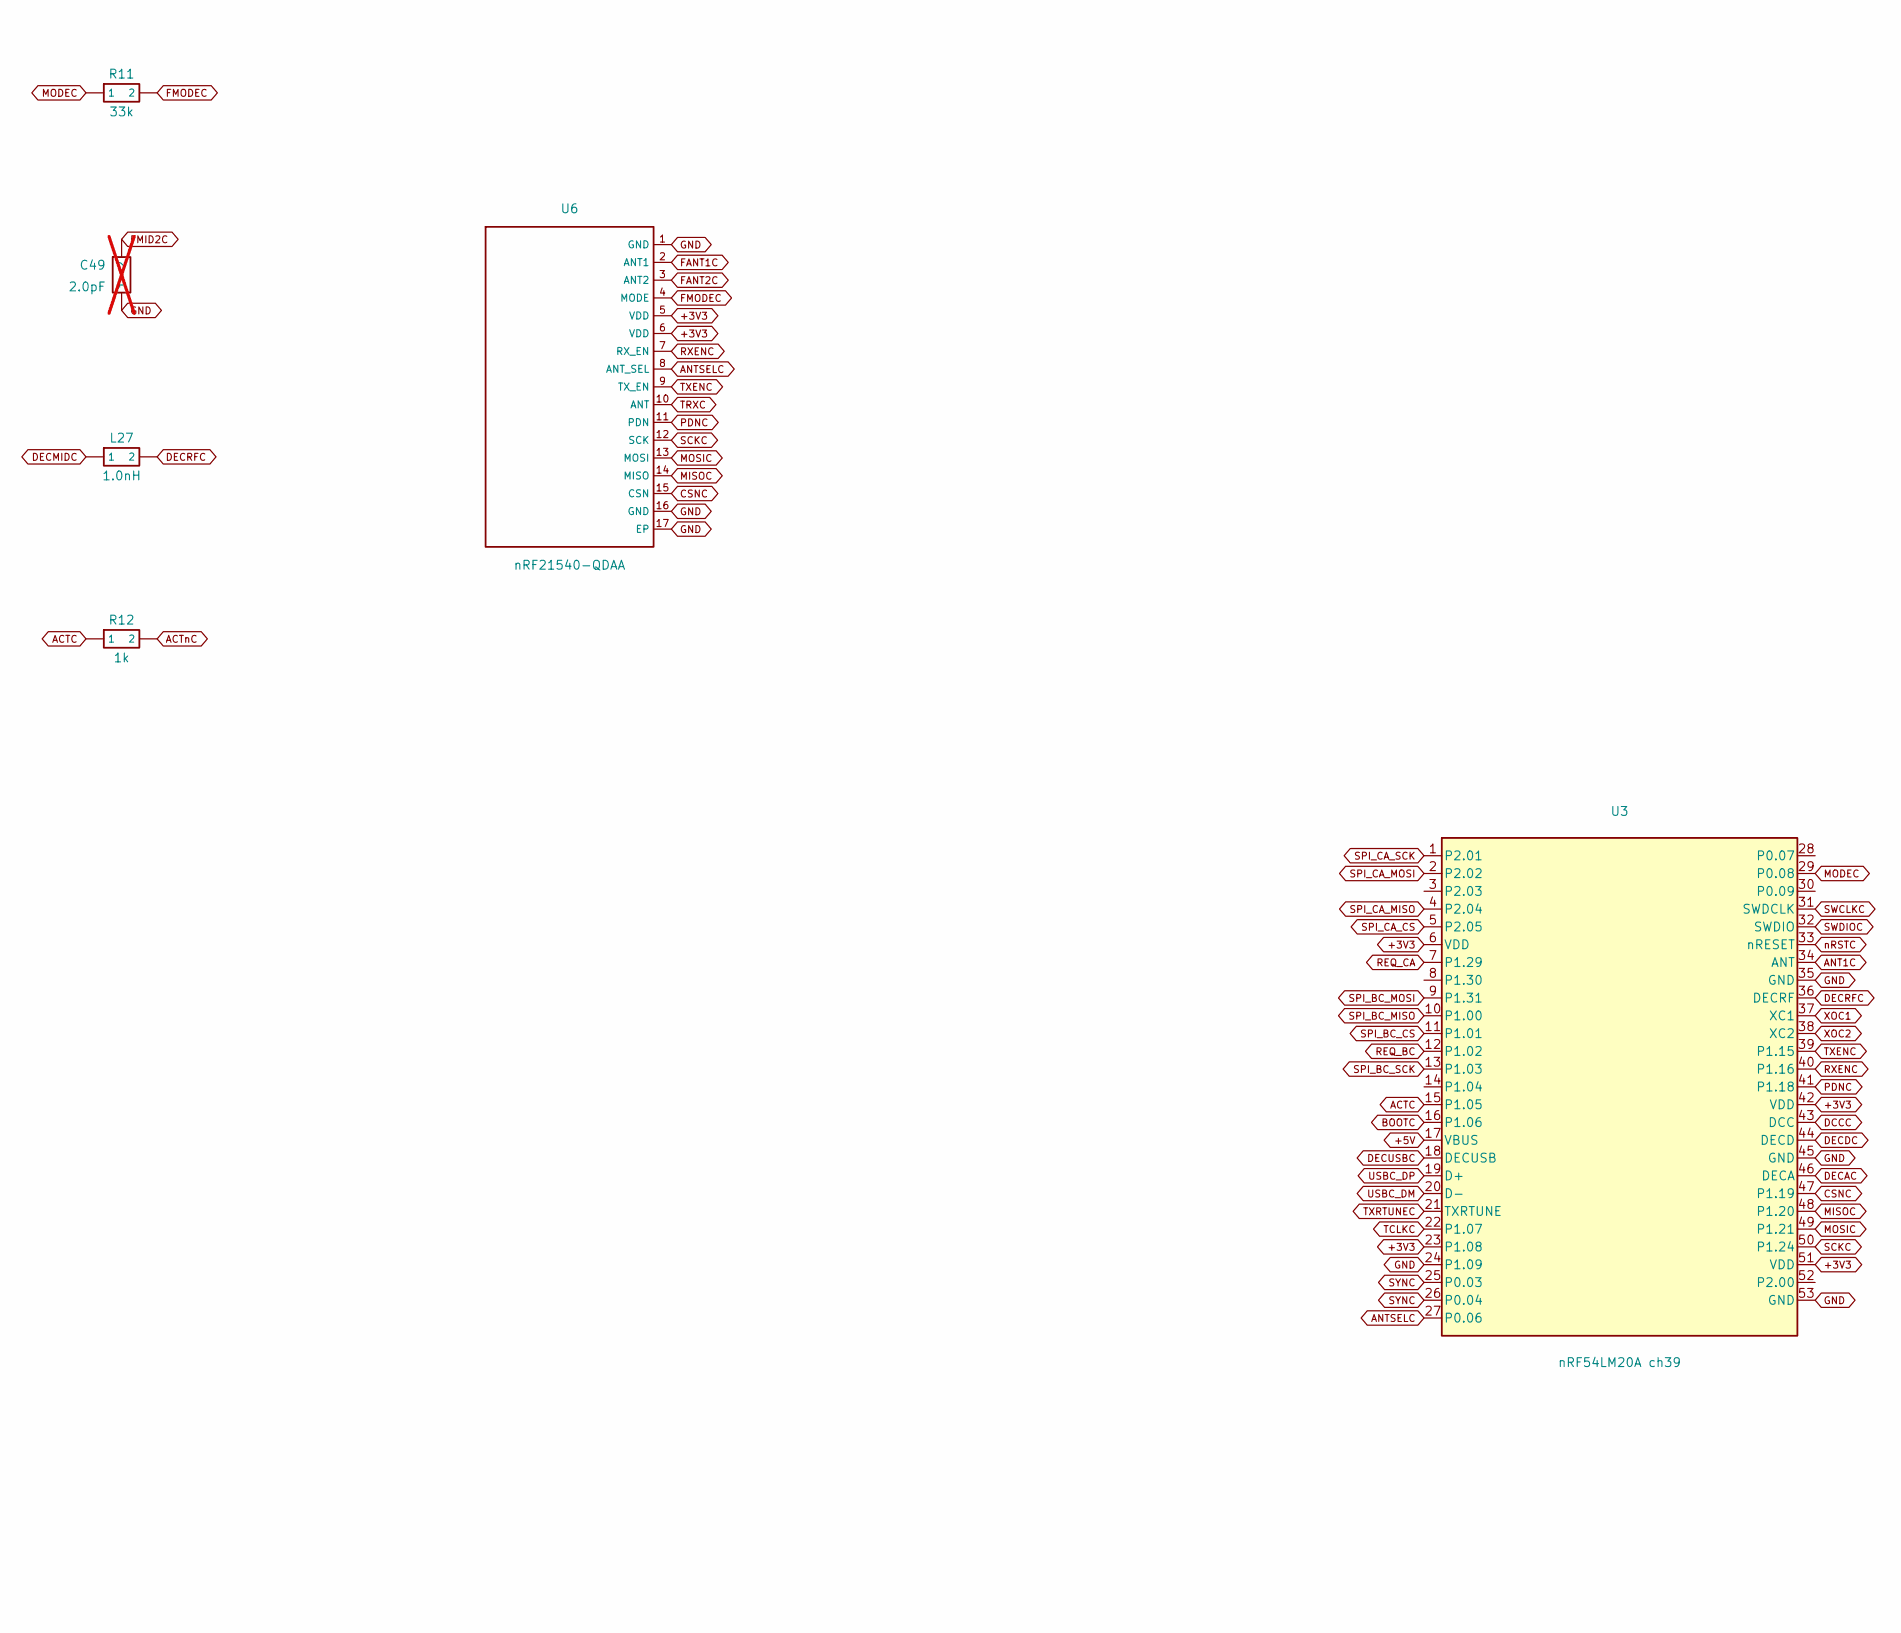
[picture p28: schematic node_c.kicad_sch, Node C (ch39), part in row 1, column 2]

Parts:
C41: 1.2pF; DK_C_0201_0603Metric
C42: 1.5pF; DK_C_0201_0603Metric
C43: 0.3pF; DK_C_0201_0603Metric
C44, C48, C53: 1.0pF; DK_C_0201_0603Metric
C45: 100nF; DK_C_0201_0603Metric
C46: 10uF; DK_C_0603_1608Metric
C47: 2.0pF; DK_C_0201_0603Metric
C49: 2.0pF; DK_C_0201_0603Metric; not fitted
C50: 1.0pF; DK_C_0201_0603Metric; not fitted
C51: 4.7uF; DK_C_0201_0603Metric
C52, C54, C55: 2.2uF; DK_C_0201_0603Metric
C56, C57, C58: 100nF; C_0402_1005Metric
C59: 10uF; C_0603_1608Metric
C60: 4.7uF; C_0603_1608Metric
D3: GREEN; LED_0603_1608Metric
FB5: 120R; DK_L_0201_0603Metric
FB6: 15nH; DK_L_0201_0603Metric
J7: PCB.SMAFRA.HT; SMA_RA_TH_PCBSMAFRA_HT
J8: PCB.SMAFRA.HT; SMA_RA_TH_PCBSMAFRA_HT; not fitted
J9: SWD+ETM ch39; PinHeader_2x05_P2.54mm_Vertical
L19: 3.6nH; DK_L_0201_0603Metric
L20: 4.7nH; DK_L_0201_0603Metric
L21: 3.3nH; DK_L_0201_0603Metric
L22: 1.9nH; DK_L_0201_0603Metric
L23: 3.0nH; DK_L_0201_0603Metric
L24: 1.9nH; DK_L_0201_0603Metric; not fitted
L25: 3.0nH; DK_L_0201_0603Metric; not fitted
L26: 4.7uH; DK_L_0603_1608Metric
L27: 1.0nH; DK_L_0201_0603Metric
R11: 33k; DK_R_0201_0603Metric
R12: 1k; R_0402_1005Metric
R13, R14, R15: 10k; R_0402_1005Metric
R22: 200R; R_0402_1005Metric
SW5: BOOT; SW_SPST_SKQG_WithoutStem
SW6: RESET; SW_SPST_SKQG_WithoutStem
U3: nRF54LM20A ch39; nRF54LM20A_QFN52_6x6mm_P0.4mm_EP4.7x4.7mm
U6: nRF21540-QDAA; nRF21540_QFN16_4x4mm_P0.65mm_EP2.65
Y3: 32MHz; DK_Crystal_32MHz

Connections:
+3V3: C45.1, C46.1, C56.1, C57.1, C58.1, C59.1, J9.1 (VCC), J9.4 (TD0_SWO), R13.1, R14.1, R15.1, U3.6 (VDD), U3.23 (P1.08), U3.42 (VDD), U3.51 (VDD), U6.5 (VDD), U6.6 (VDD); also elsewhere on the board
+5V: C60.1, U3.17 (VBUS); also elsewhere on the board
ACTC: R12.1, U3.15 (P1.05)
ACTnC: D3.2, R12.2
ANT1C: L19.1, U3.34 (ANT)
ANT2C: C41.1, L19.2, L20.1
ANT3C: C42.1, L20.2, L21.1
ANT4C: C43.1, C44.1, L21.2
ANTSELC: U3.27 (P0.06), U6.8 (ANT_SEL)
BOOTC: R13.2, SW5.1, U3.16 (P1.06)
CSNC: U3.47 (P1.19), U6.15 (CSN)
DCCC: L26.1, U3.43 (DCC)
DECAC: C52.1, FB5.2, FB6.1, U3.46 (DECA)
DECDC: C51.1, FB5.1, L26.2, U3.44 (DECD)
DECMIDC: C53.2, C54.1, FB6.2, L27.1
DECRFC: C53.1, L27.2, U3.36 (DECRF)
DECUSBC: C55.1, U3.18 (DECUSB)
FANT1C: L22.1, U6.2 (ANT1)
FANT2C: L24.1, U6.3 (ANT2)
FMID1C: C47.2, L22.2, L23.1
FMID2C: C49.2, L24.2, L25.1
FMODEC: R11.2, U6.4 (MODE)
GND: C41.2, C42.2, C43.2, C45.2, C46.2, C47.1, C48.1, C49.1, C50.1, C51.2, C52.2, C54.2, C55.2, C56.2, C57.2, C58.2, C59.2, C60.2, D3.1, J7.2, J8.2, J9.3 (GND), J9.6 (TD1), R22.2, SW5.2, SW6.2, U3.24 (P1.09), U3.35 (GND), U3.45 (GND), U3.53 (GND), U6.1 (GND), U6.16 (GND), U6.17 (EP), Y3.2, Y3.4; also elsewhere on the board
MISOC: U3.48 (P1.20), U6.14 (MISO)
MODEC: R11.1, U3.29 (P0.08)
MOSIC: U3.49 (P1.21), U6.13 (MOSI)
PDNC: U3.41 (P1.18), U6.11 (PDN)
REQ_BC: U3.12 (P1.02); also elsewhere on the board
REQ_CA: U3.7 (P1.29); also elsewhere on the board
RFO1C: C48.2, J7.1, L23.2
RFO2C: C50.2, J8.1, L25.2
RXENC: U3.40 (P1.16), U6.7 (RX_EN)
SCKC: U3.50 (P1.24), U6.12 (SCK)
SPI_BC_CS: U3.11 (P1.01); also elsewhere on the board
SPI_BC_MISO: U3.10 (P1.00); also elsewhere on the board
SPI_BC_MOSI: U3.9 (P1.31); also elsewhere on the board
SPI_BC_SCK: U3.13 (P1.03); also elsewhere on the board
SPI_CA_CS: R15.2, U3.5 (P2.05); also elsewhere on the board
SPI_CA_MISO: U3.4 (P2.04); also elsewhere on the board
SPI_CA_MOSI: U3.2 (P2.02); also elsewhere on the board
SPI_CA_SCK: U3.1 (P2.01); also elsewhere on the board
SWCLKC: J9.5 (SWCLK), U3.31 (SWDCLK)
SWDIOC: J9.7 (SWDIO), U3.32 (SWDIO)
SYNC: J9.8 (TD2), J9.10 (TD3), U3.25 (P0.03), U3.26 (P0.04); also elsewhere on the board
TCLKC: J9.2 (TRACECLK), U3.22 (P1.07)
TRXC: C44.2, U6.10 (ANT)
TXENC: U3.39 (P1.15), U6.9 (TX_EN)
TXRTUNEC: R22.1, U3.21 (TXRTUNE)
USBC_DM: U3.20 (D-); also elsewhere on the board
USBC_DP: U3.19 (D+); also elsewhere on the board
XOC1: U3.37 (XC1), Y3.1
XOC2: U3.38 (XC2), Y3.3
nRSTC: J9.9 (nRESET), R14.2, SW6.1, U3.33 (nRESET)

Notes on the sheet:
Node C: guards advertising channel 39 (strap hard-coded). Hold BOOT + press RESET to enter the USB bootloader.

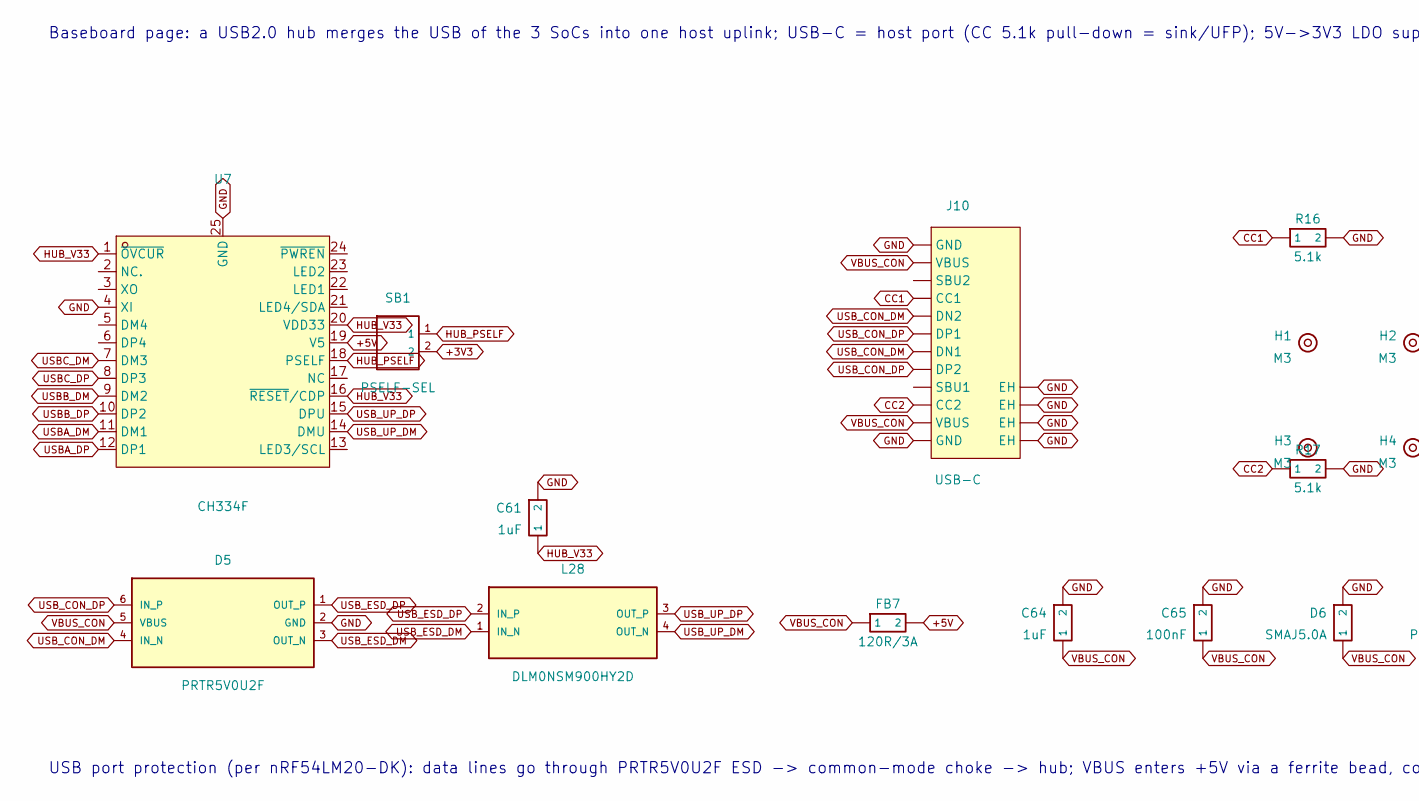
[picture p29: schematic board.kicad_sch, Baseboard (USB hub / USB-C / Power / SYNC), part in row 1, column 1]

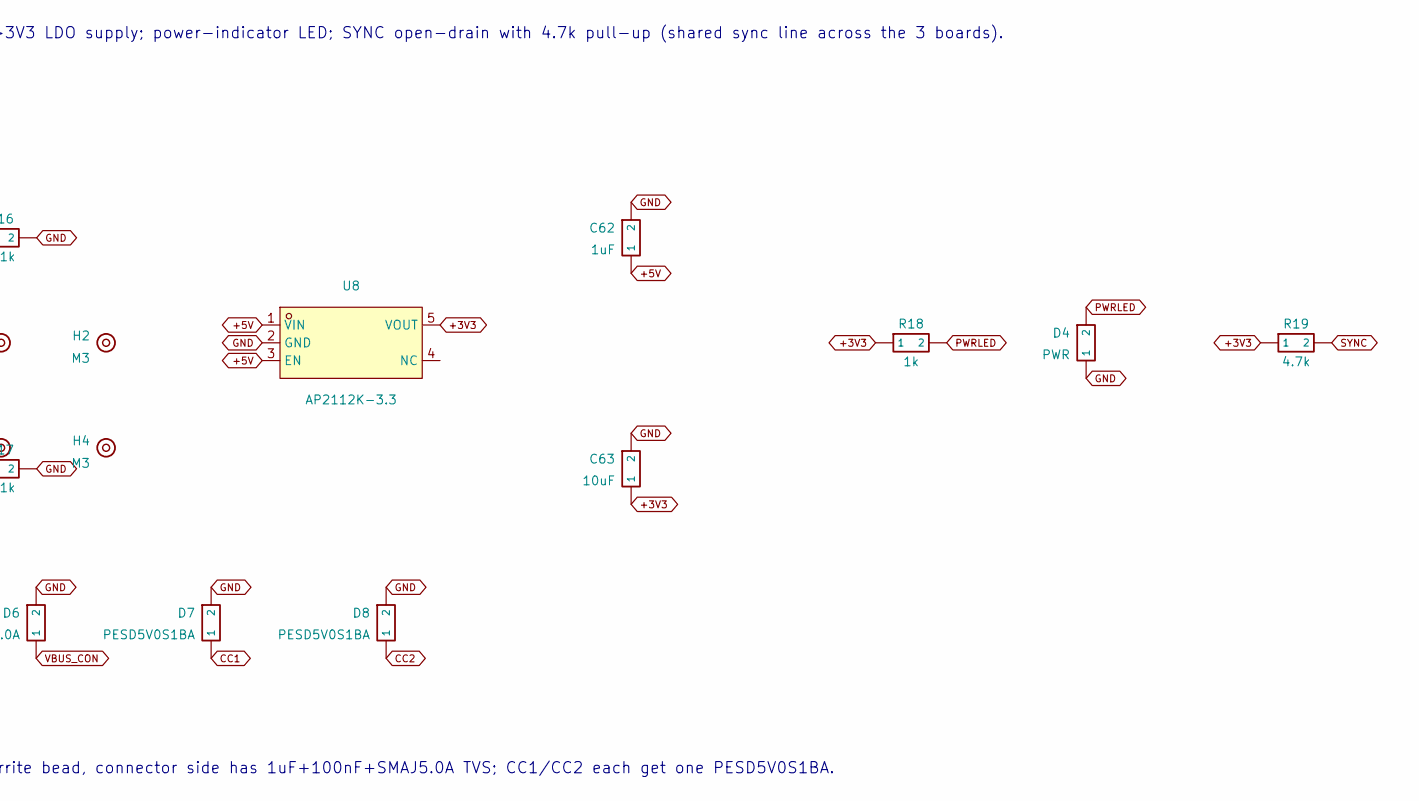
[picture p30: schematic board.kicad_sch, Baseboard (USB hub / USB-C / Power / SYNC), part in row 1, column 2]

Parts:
C61: 1uF; C_0402_1005Metric
C62, C64: 1uF; C_0603_1608Metric
C63: 10uF; C_0603_1608Metric
C65: 100nF; C_0402_1005Metric
D4: PWR; LED_0603_1608Metric
D5: PRTR5V0U2F; SON50P100X50-6N
D6: SMAJ5.0A; D_SMA
D7, D8: PESD5V0S1BA; D_SOD-323
FB7: 120R/3A; INDC1608X06L
H1, H2, H3, H4: M3; MountingHole_3.2mm_M3
J10: USB-C; USB-C_SMD-TYPE-C-31-M-12_1
L28: DLM0NSM900HY2D; CMC0806X05N
R16, R17: 5.1k; R_0402_1005Metric
R18: 1k; R_0402_1005Metric
R19: 4.7k; R_0402_1005Metric
SB1: PSELF-SEL; SolderBridge_Nordic_Bridged
U7: CH334F; QFN-24_L4.0-W4.0-P0.50-BL-EP2.8
U8: AP2112K-3.3; SOT-25-5_L2.9-W1.6-P0.95-LS2.8-BL

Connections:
+3V3: C63.1, R18.1, R19.1, SB1.2, U8.5 (VOUT); also elsewhere on the board
+5V: C62.1, FB7.2, U7.19 (V5), U8.1 (VIN), U8.3 (EN); also elsewhere on the board
CC1: D7.1, J10.A5 (CC1), R16.1
CC2: D8.1, J10.B5 (CC2), R17.1
GND: C61.2, C62.2, C63.2, C64.2, C65.2, D4.1, D5.2 (GND), D6.2, D7.2, D8.2, J10.1 (EH), J10.2 (EH), J10.3 (EH), J10.4 (EH), J10.A1B12 (GND), J10.B1A12 (GND), R16.2, R17.2, U7.4 (XI), U7.25 (GND), U8.2 (GND); also elsewhere on the board
HUB_PSELF: SB1.1, U7.18 (PSELF)
HUB_V33: C61.1, U7.1 (~OVCUR), U7.16 (~RESET/CDP), U7.20 (VDD33)
PWRLED: D4.2, R18.2
SYNC: R19.2; also elsewhere on the board
USBA_DM: U7.11 (DM1); also elsewhere on the board
USBA_DP: U7.12 (DP1); also elsewhere on the board
USBB_DM: U7.9 (DM2); also elsewhere on the board
USBB_DP: U7.10 (DP2); also elsewhere on the board
USBC_DM: U7.7 (DM3); also elsewhere on the board
USBC_DP: U7.8 (DP3); also elsewhere on the board
USB_CON_DM: D5.4 (IN_N), J10.A7 (DN1), J10.B7 (DN2)
USB_CON_DP: D5.6 (IN_P), J10.A6 (DP1), J10.B6 (DP2)
USB_ESD_DM: D5.3 (OUT_N), L28.1 (IN_N)
USB_ESD_DP: D5.1 (OUT_P), L28.2 (IN_P)
USB_UP_DM: L28.4 (OUT_N), U7.14 (DMU)
USB_UP_DP: L28.3 (OUT_P), U7.15 (DPU)
VBUS_CON: C64.1, C65.1, D5.5 (VBUS), D6.1, FB7.1, J10.A4B9 (VBUS), J10.B4A9 (VBUS)

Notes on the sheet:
Baseboard page: a USB2.0 hub merges the USB of the 3 SoCs into one host uplink; USB-C = host port (CC 5.1k pull-down = sink/UFP); 5V->3V3 LDO supply; power-indicator LED; SYNC open-drain with 4.7k pull-up (shared sync line across the 3 boards).
USB port protection (per nRF54LM20-DK): data lines go through PRTR5V0U2F ESD -> common-mode choke -> hub; VBUS enters +5V via a ferrite bead, connector side has 1uF+100nF+SMAJ5.0A TVS; CC1/CC2 each get one PESD5V0S1BA.

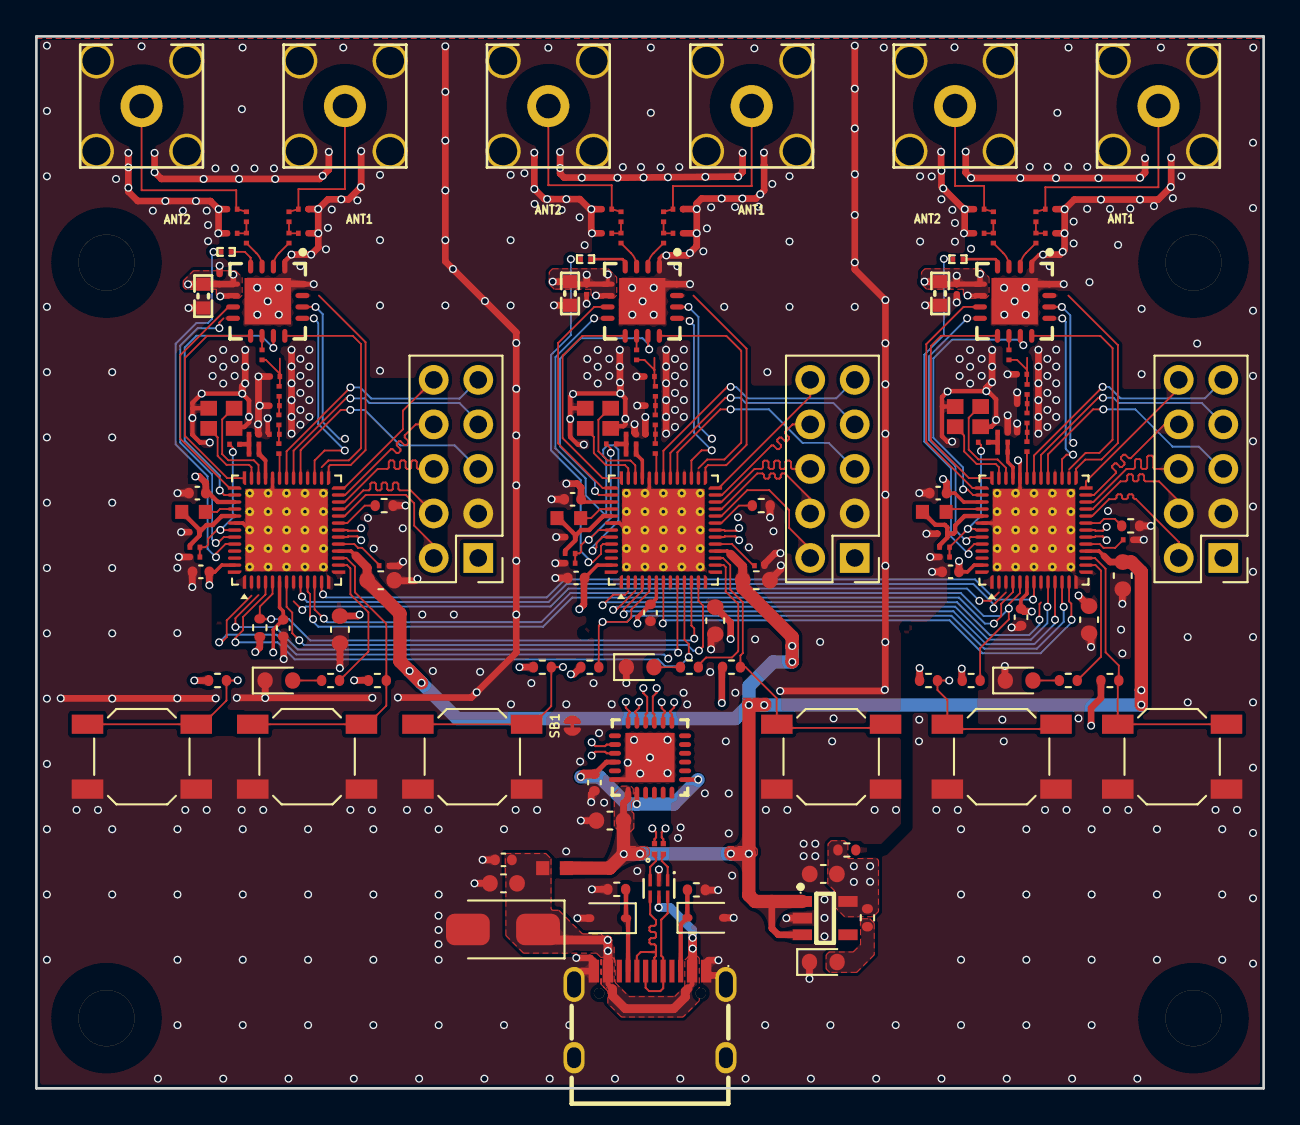
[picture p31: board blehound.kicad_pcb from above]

Board: 6 copper layers, 70.0 x 60.0 mm, 162 parts (0 on the bottom side), 148 nets.

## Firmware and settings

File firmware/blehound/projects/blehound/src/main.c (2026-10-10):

/* SPDX-License-Identifier: Apache-2.0 */
/*
 * BLEhound Sniffer — firmware main program
 *
 * Data flow:
 *   RADIO IRQ --(copy & enqueue, non-blocking)--> k_msgq --> sniffer thread --> USB CDC --> Wireshark
 *                                                                         \-> RTT log (for debugging)
 *
 * Why the interrupt doesn't send USB / log directly: both can block for hundreds of µs, enough
 * to make the radio miss back-to-back packets. The interrupt only does a fixed-length copy;
 * everything else is done in the thread.
 *
 * Capture continues as usual when no host is connected, it just isn't sent — this way RTT always
 * shows the radio working.
 */

#include <zephyr/kernel.h>
#include <zephyr/device.h>
#include <zephyr/drivers/gpio.h>
#include <zephyr/logging/log.h>
#include <zephyr/sys/reboot.h>
#if IS_ENABLED(CONFIG_RETENTION_BOOT_MODE)
#include <zephyr/retention/bootmode.h>
#endif

#include "radio_hal.h"
#include "host_iface.h"
#include "conn_follower.h"
#include "board_role.h"
#include "tri_coord.h"
#include "peer_link.h"
#include "sync_line.h"
#include "led_policy.h"
#include "adv_filter.h"
#include "rpa_resolve.h"
#include "fem_ctrl.h"

LOG_MODULE_REGISTER(sniffer, LOG_LEVEL_INF);

/* Default to capturing on advertising channel 37. On tri-device boards a strap decides which channel to guard (see g_role);
 * for a single board / no strap, fall back to this, and the host can also change it with HOST_CMD_SET_CHANNEL. */
#define DEFAULT_CHANNEL       BLE_CHANNEL_ADV_37

/* This device's role (board_id + guarded advertising channel), obtained by reading the strap at boot */
static struct board_role g_role = { .board_id = 0, .guard_channel = DEFAULT_CHANNEL };

/* Queue depth: enough to absorb USB/logging jitter, without eating too much RAM */
#define CAPTURE_QUEUE_DEPTH   32

#define LED_TICK_MS           20      /* Main loop tick: the LED policy is evaluated once every 20ms */
#define STATS_LOG_INTERVAL_MS 10000

/* On-board LED0 (devicetree alias led0, present on both DK / Dongle) */
static const struct gpio_dt_spec led = GPIO_DT_SPEC_GET(DT_ALIAS(led0), gpios);

/* An enqueued packet. pdu is stored fixed-length to avoid variable-length allocation. */
struct captured_packet {
	uint32_t timestamp_us;
	uint32_t access_addr;
	uint32_t crc;
	uint16_t pdu_len;
	int8_t rssi_dbm;
	uint8_t channel;
	uint8_t phy;
	bool crc_ok;
	uint8_t direction;   /* HOST_DIR_*: decided by packet order within the connection event, unknown for advertising */
	uint8_t pdu[RADIO_PDU_MAX_LEN];
};

K_MSGQ_DEFINE(capture_q, sizeof(struct captured_packet), CAPTURE_QUEUE_DEPTH, 4);

/* On queue-full, drop the packet and count it — radio timing comes first; never block the interrupt just because the downstream is slow */
static atomic_t queue_drops;

/* Firmware version string V1.0.0.<git commit count>: provided by the CMake-generated blehound_version.h,
 * incremented with every commit; outside git it falls back to V1.0.0.0. */
#include "blehound_version.h"
#ifndef BLEHOUND_FW_VERSION
#define BLEHOUND_FW_VERSION "V1.0.0.0"
#endif
static const char fw_version[] = BLEHOUND_FW_VERSION;

/* Host QUERY_STATUS request flag (set in the CDC interrupt, consumed by the capture thread) */
static atomic_t status_requested;
/* HOST_CMD_ENTER_DFU only sets this in the CDC interrupt; writing the boot mode + reset happens in the capture thread */
static atomic_t dfu_requested;
/* Mirror of the capture configuration: commands update it in the CDC interrupt, the status frame reads it in the capture thread. Single-byte accesses are naturally atomic. */
static volatile bool st_hopping;
static volatile bool st_single_target = true;   /* matches the conn_follower default */

/* Capture statistics. Modified only in the sniffer thread, no lock needed. */
static struct {
	uint32_t crc_ok;
	uint32_t crc_err;
	uint32_t sent;
} stats;

/* Radio-layer per-PHY RX counts (0=1M 1=2M 2/3=Coded), to see whether each PHY decodes healthily */
static uint32_t phy_rx[4];
/* Times the RX watchdog re-issued RXEN (checked once per main-loop tick; should stay 0, non-zero means the radio once stalled in DISABLED) */
static uint32_t rx_recovered;
static uint32_t phy_rx_ok[4];

/* Current capture parameters. The host can change them; the radio interrupt only reads. */
static uint8_t active_channel = DEFAULT_CHANNEL;

/* Advertising filter for single-target mode: the target MAC is set by HOST_CMD_SET_TARGET (CDC interrupt writes,
 * radio interrupt reads; clear active first, then copy, then set — worst case the read side just passes/blocks one extra packet). */
static uint8_t target_mac[6];
static bool target_active;
static uint32_t adv_filtered;   /* Number of advertising packets blocked by the target filter (incremented in the radio interrupt, printed in the stats line) */

/* The target's IRK (HOST_CMD_SET_IRK, over-the-air / SMP order): once set, the target is still recognised after it changes RPA.
 * The RX interrupt only consults rpa_cache; AES runs in the capture thread (see the division of work in rpa_resolve.h). */
static uint8_t target_irk[16];
static volatile bool irk_active;
static struct rpa_cache rpa_cache;
static uint32_t rpa_resolved;   /* Number of new RPAs recognised via the IRK and switched to (modified in the capture thread) */

/* Set/clear the target MAC (6 little-endian bytes as on air; NULL = clear): applies to both the follower filter and the RX-interrupt advertising filter */
static void apply_target(const uint8_t *mac)
{
	conn_follower_set_target(mac);
	target_active = false;
	if (mac != NULL) {
		memcpy(target_mac, mac, 6);
		target_active = true;
	}
}

/* Set/clear the target IRK (16 bytes, over-the-air order; NULL = clear): invalidate first, then copy, then set; the old cache is cleared too */
static void apply_irk(const uint8_t *irk)
{
	irk_active = false;
	rpa_cache_reset(&rpa_cache);
	if (irk != NULL) {
		memcpy(target_irk, irk, sizeof(target_irk));
		irk_active = true;
	}
}

/* RX interrupt: is this PDU under the advertising AA related to the target? With an IRK set, the target's new RPAs count too
 * (only on a cache hit; an RPA seen for the first time is only recorded and treated as unrelated until the capture thread resolves it). */
static bool adv_pdu_is_target(const uint8_t *pdu, uint16_t pdu_len)
{
	const uint8_t *adva = adv_pdu_adva(pdu, pdu_len);

	if (adva == NULL) {
		return false;
	}
	if (target_active && memcmp(adva, target_mac, 6) == 0) {
		return true;
	}
	if (irk_active && rpa_is_resolvable(adva)) {
		return rpa_cache_lookup(&rpa_cache, adva) == RPA_MATCH;
	}
	return false;
}

/* Capture thread: run the IRK over the RPAs the interrupt recorded as pending; whatever resolves is the target's new address, switch to it. */
static void resolve_pending_rpas(void)
{
	uint8_t addr[6];
	bool matched;

	if (!irk_active) {
		return;
	}
	while (rpa_cache_resolve_one(&rpa_cache, target_irk, addr, &matched)) {
		if (!matched || (target_active && memcmp(addr, target_mac, 6) == 0)) {
			continue;
		}
		apply_target(addr);
		rpa_resolved++;
		LOG_INF("IRK resolved new RPA %02X:%02X:%02X:%02X:%02X:%02X -> target updated",
			addr[5], addr[4], addr[3], addr[2], addr[1], addr[0]);
	}
}

/* ---------------------------------------------------------- Advertising PDU parsing */

/* BT Core Spec Vol 6, Part B, §2.3: the advertising PDU type is in the low 4 bits of the LL header byte */
static const char *adv_pdu_type_name(uint8_t header)
{
	static const char *const names[] = {
		"ADV_IND",        "ADV_DIRECT_IND", "ADV_NONCONN_IND", "SCAN_REQ",
		"SCAN_RSP",       "CONNECT_IND",    "ADV_SCAN_IND",    "ADV_EXT_IND",
		"AUX_CONNECT_RSP",
	};
	const uint8_t type = header & 0x0F;

	return (type < ARRAY_SIZE(names)) ? names[type] : "RESERVED";
}

/*
 * Get the offset of AdvA within the payload.
 *
 * Most advertising PDUs' payloads start with AdvA, but SCAN_REQ / CONNECT_IND put the
 * initiator's address first and AdvA after; reading at offset 0 would mislabel ScanA/InitA as AdvA.
 * The ADV_EXT_IND family uses an extended header and has no fixed-position AdvA.
 *
 * @return AdvA offset; a negative value means the PDU has no directly locatable AdvA
 */
static int adv_addr_offset(uint8_t header)
{
	switch (header & 0x0F) {
	case 0x00:  /* ADV_IND */
	case 0x01:  /* ADV_DIRECT_IND */
	case 0x02:  /* ADV_NONCONN_IND */
	case 0x04:  /* SCAN_RSP */
	case 0x06:  /* ADV_SCAN_IND */
		return 0;
	case 0x03:  /* SCAN_REQ: ScanA(6) + AdvA(6) */
	case 0x05:  /* CONNECT_IND: InitA(6) + AdvA(6) */
		return 6;
	default:    /* ADV_EXT_IND / AUX_* : extended header, parsed in a later stage */
		return -1;
	}
}

/* BLE addresses are little-endian on air, so reverse for printing */
static void format_adv_addr(const struct captured_packet *item, char *out, size_t out_sz)
{
	const int off = adv_addr_offset(item->pdu[0]);
	const int payload_len = (int)item->pdu_len - RADIO_PDU_HEADER_LEN;

	if (off < 0 || payload_len < off + 6) {
		strncpy(out, "-", out_sz);
		out[out_sz - 1] = '\0';
		return;
	}

	const uint8_t *a = &item->pdu[RADIO_PDU_HEADER_LEN + off];

	snprintk(out, out_sz, "%02X:%02X:%02X:%02X:%02X:%02X",
		 a[5], a[4], a[3], a[2], a[1], a[0]);
}

/* Short description of a data-channel PDU (classified by LLID) */
static const char *data_pdu_desc(uint8_t header)
{
	switch (header & 0x03) {
	case 0x01:
		return "LL_DATA(empty/cont)";
	case 0x02:
		return "LL_DATA(start)";
	case 0x03:
		return "LL_CONTROL";
	default:
		return "RFU";
	}
}

/* Channels 0..36 are data channels (following a connection); 37/38/39 are advertising channels */
static bool is_adv_channel(uint8_t ch)
{
	return ch >= BLE_CHANNEL_ADV_37;
}

/* ---------------------------------------------------------------- radio */

/* Interrupt context: first feed the connection follower (it may schedule/switch channel based on it), then copy & enqueue for the host */
static void on_radio_packet(const struct radio_packet *pkt)
{
	/* Which link this packet belongs to depends on the AA the radio was tuned to when receiving it */
	const uint32_t frame_aa = radio_get_access_addr();

	/* The host's FOLLOW relay / key hint must be consumed **before** the target filter: while the target is
	 * connected and not advertising, every following packet is filtered out and the follower would never
	 * see what is in the mailboxes. */
	conn_follower_poll_host_requests();

	/* Single-target mode: once a target MAC is set, under the advertising AA only PDUs related to the target pass on — don't emit a hit,
	 * don't build a slot, don't chase AUX, don't send to the host. Data-channel packets can only come from the followed connection, so let them all through. */
	if ((target_active || irk_active) && frame_aa == BLE_ADV_ACCESS_ADDR &&
	    !adv_pdu_is_target(pkt->pdu, pkt->pdu_len)) {
		adv_filtered++;
		return;
	}

	/* Let the tri-device coordination layer see it first (it may emit a SYNC edge / hit notification based on it), then hand to the follower.
	 * Ordering point: coordination must complete the hit broadcast/handoff before conn_follower builds a slot (which asks the claim gate). */
	tri_coord_on_packet(pkt);

	conn_follower_on_packet(pkt);

	struct captured_packet item = {
		.timestamp_us = pkt->timestamp_us,
		.access_addr = frame_aa,
		.crc = pkt->crc,
		.pdu_len = MIN(pkt->pdu_len, RADIO_PDU_MAX_LEN),
		.rssi_dbm = pkt->rssi_dbm,
		.channel = pkt->channel,
		.phy = pkt->phy,
		.crc_ok = pkt->crc_ok,
		.direction = (frame_aa == BLE_ADV_ACCESS_ADDR) ? HOST_DIR_UNKNOWN
							     : conn_follower_last_packet_direction(),
	};

	memcpy(item.pdu, pkt->pdu, item.pdu_len);

	if (k_msgq_put(&capture_q, &item, K_NO_WAIT) != 0) {
		atomic_inc(&queue_drops);
	}
}

/* Host command. Executed in CDC interrupt context; only does parameter validation and register-level setup. */
/*
 * Enter firmware update mode: stop the radio, write the boot mode into gpregret1 (lost on power-off,
 * kept across a soft reset), reset. MCUboot sees BOOT_MODE_TYPE_BOOTLOADER and starts the firmware
 * loader (image-1), which writes the new app into image-0 and resets back. Firmware built without DFU
 * (not via sysbuild + MCUboot) only logs.
 */
static void enter_dfu_loader(void)
{
#if IS_ENABLED(CONFIG_RETENTION_BOOT_MODE)
	radio_rx_stop();
	const int rc = bootmode_set(BOOT_MODE_TYPE_BOOTLOADER);

	if (rc != 0) {
		LOG_ERR("DFU: bootmode_set failed (%d), staying in app", rc);
		return;
	}
	LOG_INF("DFU: rebooting into firmware loader");
	k_sleep(K_MSEC(50));   /* let the log / USB push out the last bytes */
	sys_reboot(SYS_REBOOT_COLD);
#else
	LOG_WRN("DFU: not built into this firmware, ignoring");
#endif
}
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
int main(void)
{
	LOG_INF("=== BLEhound Sniffer starting ===");

	/* Read the strap at boot to decide the role — three devices run identical firmware, each guarding 37/38/39 via strap (scheme §4.5). */
	g_role = board_role_read();
	active_channel = g_role.guard_channel;

	const bool led_ok = gpio_is_ready_dt(&led);

	if (!led_ok) {
		LOG_ERR("LED device not ready");
	} else {
		gpio_pin_configure_dt(&led, GPIO_OUTPUT_ACTIVE);
	}

	/* Bring up radio before USB: the radio doesn't depend on USB, and on some platforms (the nRF54L's DesignWare USB)
	 * usb_enable may block when there is no VBUS, so putting it later keeps it from blocking radio bring-up validation. */
	(void)sniffer_start();
	(void)host_iface_init(on_host_command);

	/* Default target at boot (Kconfig, empty = no filter): follow a single target even without a host; once the host connects
	 * HOST_CMD_SET_TARGET overrides it. */
	if (CONFIG_SNIFFER_DEFAULT_TARGET_MAC[0] != '\0') {
		uint8_t mac[6];

		if (adv_filter_parse_mac(CONFIG_SNIFFER_DEFAULT_TARGET_MAC, mac)) {
			apply_target(mac);
			LOG_INF("default target MAC: %s (single-target + advertising filter)", CONFIG_SNIFFER_DEFAULT_TARGET_MAC);
		} else {
			LOG_ERR("default target MAC has invalid format: %s", CONFIG_SNIFFER_DEFAULT_TARGET_MAC);
		}
	}

	int64_t last_stats = k_uptime_get();

	/* LED indication policy (led_policy.h): reflects only this device's own RF following — in scanning state, one short blink per second;
	 * after following a connection, toggles with RX; while following but 500ms without a packet, stays solid on; on supervision-timeout loss, blinks fast 3 times. Unrelated to SYNC. */
	struct led_policy ledp;
	enum led_state led_state_last = LED_STATE_IDLE;
	bool led_level_last = false;

	led_policy_init(&ledp, k_uptime_get_32(), conn_follower_acl_packets(),
			conn_follower_acl_lost_timeouts());

	while (1) {
		const uint32_t now_ms = k_uptime_get_32();
		enum led_state led_state_now;
		const bool led_on = led_policy_step(&ledp, now_ms,
						    conn_follower_active_connections(),
						    conn_follower_acl_packets(),
						    conn_follower_acl_lost_timeouts(),
						    &led_state_now);

		if (led_ok && led_on != led_level_last) {
			led_level_last = led_on;
			gpio_pin_set_dt(&led, led_on ? 1 : 0);
		}

		if (led_state_now != led_state_last) {
			led_state_last = led_state_now;
			LOG_INF("LED: %s", led_state_name(led_state_now));
		}

		/* Tri-device time-base heartbeat (board 0 emits a SYNC edge at ~1Hz; internally rate-limited). */
		tri_coord_periodic();

		/* RX watchdog: if the radio is stuck in DISABLED (the RXEN in the ISR was not accepted), re-issue it so this board doesn't go deaf. */
		if (radio_rx_recover()) {
			rx_recovered++;
			LOG_WRN("radio found DISABLED while RX should be running, restarted (%u)", rx_recovered);
		}

		/* When the air is completely quiet the RX interrupt never fires; consume the host mailboxes here as a fallback (mutually exclusive with the radio interrupt). */
		{
			unsigned int key = irq_lock();

			conn_follower_poll_host_requests();
			irq_unlock(key);
		}

		if (k_uptime_get() - last_stats >= STATS_LOG_INTERVAL_MS) {
			last_stats = k_uptime_get();

			struct conn_follower_stats cf;

			conn_follower_get_stats(&cf);

			LOG_INF("stats: CRC_OK %u, CRC_ERR %u, sent %u, queue drops %ld, target filtered %u, USB dropped %u, RPA resolved %u, RX recovered %u",
				stats.crc_ok, stats.crc_err, stats.sent,
				atomic_get(&queue_drops), adv_filtered, host_iface_dropped(), rpa_resolved,
				rx_recovered);

			struct tri_coord_stats tc;

			tri_coord_get_stats(&tc);
			struct peer_link_stats pl;

			peer_link_get_stats(&pl);
			LOG_INF("  tri-device[id=%u]: own hits %u, peer hits %u, handoffs sent %u/recv %u, SYNC emit %u/capture %u, epoch=%u, inter-board tx dropped %u, LED=%s, handoff injected %u/unmatched %u, rx bad %u",
				g_role.board_id, tc.own_hits, tc.peer_hits,
				tc.handoffs_sent, tc.handoffs_recv, tc.sync_emits,
				sync_line_capture_count(), tri_coord_sync_epoch(),
				tc.tx_dropped, led_state_name(led_state_last),
				tc.handoffs_injected, tc.handoffs_unmatched, tc.rx_bad);
			LOG_INF("  inter-board link: SPIM tx %u (err %u), REQ reads %u, REQ out %u, SPIS xfers %u/msgs %u (arm err %u, %s), last err %d",
				pl.spim_tx, pl.spim_tx_err, pl.spim_rx, pl.req_out, pl.spis_xfer, pl.spis_rx,
				pl.spis_arm_err, pl.spis_ready ? "armed" : "no slave port", pl.last_err);
			sync_line_log_debug();
			LOG_INF("  multi-target: currently tracking %u (peak %u), CONNECT_IND %u,"
				"event %u, data packets %u, collisions %u, lost %u, PHY switches %u, relay takeovers %u, relocks %u,"
				"ext-adv chases %u (throttled %u), periodic synced %u, BIS %u, CIS %u, subrate %u, PAwR responses %u, AUX connects %u, hints %u, unmapped events %u",
				cf.active_now, cf.peak_concurrent, cf.connects_seen,
				cf.conn_events, cf.data_packets, cf.collisions, cf.lost,
				cf.phy_updates, cf.injects_followed, cf.relock_recovered,
				cf.ext_adv_chase, cf.ext_adv_throttled,
				cf.periodic_synced, cf.bis_synced, cf.cis_synced,
				cf.subrate_updates, cf.pawr_responses, cf.aux_connects,
				cf.hints_applied, cf.unmapped_events);
			LOG_INF("  single-target: stale slots preempted by target reconnect/advertising %u, relock events yielded to guard channel %u",
				cf.preempted, cf.relock_yields);
			LOG_INF("  encrypted channel map: probes on unmapped channels %u, map changes detected %u",
				cf.map_probes, cf.map_changed);
			LOG_INF("  never established (peripheral never answered, released early): %u",
				cf.never_established);
			LOG_INF("  scheduling: max window-open lateness %uus, radio config avg %uus/max %uus (%u times)",
				cf.open_late_max_us,
				cf.open_count ? cf.open_cost_sum_us / cf.open_count : 0,
				cf.open_cost_max_us, cf.open_count);
			LOG_INF("  radio per-PHY RX: 1M %u/%u 2M %u/%u Coded %u/%u (ok/total)",
				phy_rx_ok[0], phy_rx[0], phy_rx_ok[1], phy_rx[1],
				phy_rx_ok[2] + phy_rx_ok[3], phy_rx[2] + phy_rx[3]);
			LOG_INF("  6.x: CS negotiation PDUs %u, frame-space negotiations %u, short connection intervals %u, extended feature sets %u, decision advertising %u",
				cf.cs_pdus, cf.frame_space_updates,
				cf.conn_rate_updates, cf.feature_ext_pdus,
				cf.adv_decision);

			/* Per-connection evaluation record */
			for (uint8_t i = 0; i < CONN_FOLLOW_MAX_SLOTS; i++) {
				struct conn_slot_info si;

				conn_follower_get_slot(i, &si);
				if (si.active) {
					static const char *const phy_name[] = {
						"1M", "2M", "Coded", "Coded",
					};
					/* A short connection interval (6.2) can drop to 375µs; dividing by 1000 would show "0ms",
					 * so intervals <2ms are shown in µs; a negotiated frame space (6.0) is noted alongside. */
					char ivbuf[16];
					char fsbuf[24];
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

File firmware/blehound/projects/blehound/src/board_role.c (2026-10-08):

/* SPDX-License-Identifier: Apache-2.0 */
/*
 * Board role identification implementation — see board_role.h.
 */

#include <zephyr/kernel.h>
#include <zephyr/drivers/gpio.h>
#include <zephyr/logging/log.h>

#include "board_role.h"
#include "radio_hal.h"   /* BLE_CHANNEL_ADV_37/38/39 */

LOG_MODULE_REGISTER(board_role, LOG_LEVEL_INF);

/* Power-up settling: after the internal pull-up (~13k) is enabled the pin's parasitic capacitance needs µs to charge to a high level; reading right after configuring may
 * misread a floating pin as 0, and a fly-wire strap may bounce. So wait a short moment first, then require two consecutive identical reads before trusting the value. */
#define STRAP_SETTLE_US   100
#define STRAP_READ_RETRY  5

/* The two straps are provided by DT aliases tri-strap0 / tri-strap1 (see the board overlay).
 * The DK has no such alias group — check with DT_NODE_EXISTS and take the fallback path if absent. */
#define STRAP0_NODE DT_ALIAS(tri_strap0)
#define STRAP1_NODE DT_ALIAS(tri_strap1)

#if DT_NODE_EXISTS(STRAP0_NODE) && DT_NODE_EXISTS(STRAP1_NODE)
#define TRI_STRAPS_PRESENT 1
static const struct gpio_dt_spec strap0 = GPIO_DT_SPEC_GET(STRAP0_NODE, gpios);
static const struct gpio_dt_spec strap1 = GPIO_DT_SPEC_GET(STRAP1_NODE, gpios);
#else
#define TRI_STRAPS_PRESENT 0
#endif

#if TRI_STRAPS_PRESENT
/* strap encoding (S1,S0) → role. ch uses the advertising-channel index. */
static struct board_role role_from_code(uint8_t code)
{
	switch (code) {
	case 0x0:  /* 00 = node A */
		return (struct board_role){ .board_id = 0, .guard_channel = BLE_CHANNEL_ADV_37 };
	case 0x2:  /* 10 = node B */
		return (struct board_role){ .board_id = 1, .guard_channel = BLE_CHANNEL_ADV_38 };
	case 0x1:  /* 01 = node C */
		return (struct board_role){ .board_id = 2, .guard_channel = BLE_CHANNEL_ADV_39 };
	default:   /* 11 reserved */
		LOG_WRN("strap combination 0b%u%u reserved, falling back to {id=0, ch=37}",
			(code >> 1) & 1, code & 1);
		return (struct board_role){ .board_id = 0, .guard_channel = BLE_CHANNEL_ADV_37 };
	}
}
#endif /* TRI_STRAPS_PRESENT */

struct board_role board_role_read(void)
{
#if TRI_STRAPS_PRESENT
	if (!gpio_is_ready_dt(&strap0) || !gpio_is_ready_dt(&strap1)) {
		LOG_WRN("strap GPIO not ready, falling back to {id=0, ch=37}");
		return (struct board_role){ .board_id = 0, .guard_channel = BLE_CHANNEL_ADV_37 };
	}

	/* Input + pull-up: a strap tied to GND reads 0, floating/pulled-up reads 1. Use ACTIVE_HIGH semantics
	 * so that gpio_pin_get_dt returns the level directly (high=1 low=0). */
	(void)gpio_pin_configure_dt(&strap0, GPIO_INPUT | GPIO_PULL_UP | GPIO_ACTIVE_HIGH);
	(void)gpio_pin_configure_dt(&strap1, GPIO_INPUT | GPIO_PULL_UP | GPIO_ACTIVE_HIGH);

	k_busy_wait(STRAP_SETTLE_US);
	int s0 = gpio_pin_get_dt(&strap0);
	int s1 = gpio_pin_get_dt(&strap1);

	for (int i = 0; i < STRAP_READ_RETRY; i++) {
		k_busy_wait(STRAP_SETTLE_US);
		const int r0 = gpio_pin_get_dt(&strap0);
		const int r1 = gpio_pin_get_dt(&strap1);

		if (r0 == s0 && r1 == s1) {
			break;   /* two consecutive reads agree, trust it */
		}
		s0 = r0;
		s1 = r1;
	}

	if (s0 < 0 || s1 < 0) {
		LOG_WRN("strap read failed (s0=%d s1=%d), falling back to {id=0, ch=37}", s0, s1);
		return (struct board_role){ .board_id = 0, .guard_channel = BLE_CHANNEL_ADV_37 };
	}

	const uint8_t code = (uint8_t)(((s1 & 1) << 1) | (s0 & 1));
	const struct board_role r = role_from_code(code);

	LOG_INF("role: board_id=%u guard_channel=%u (strap S1S0=%u%u)",
		r.board_id, r.guard_channel, (code >> 1) & 1, code & 1);
	return r;
#else
	/* No strap alias (e.g. single-board DK): run with single-board defaults — board_id 0, channel 37. */
	LOG_INF("no strap alias defined, using single-board default {id=0, ch=37}");
	return (struct board_role){ .board_id = 0, .guard_channel = BLE_CHANNEL_ADV_37 };
#endif
}

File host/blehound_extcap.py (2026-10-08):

#!/usr/bin/env python3
# SPDX-License-Identifier: Apache-2.0
"""Wireshark extcap plugin — feeds the BLE packets captured by the BLEhound firmware into Wireshark.

How it works: on startup Wireshark repeatedly calls this script with different
arguments, first asking "which interfaces exist" and "which config options exist",
and only then actually starting the capture. What we do is: open the sniffer's USB
serial port, split frames on 0x00, COBS-decode, convert to PCAP and write into the
fifo Wireshark gives us.

Install (macOS / Linux):

    mkdir -p ~/.config/wireshark/extcap
    cp blehound_extcap.py ~/.config/wireshark/extcap/
    chmod +x ~/.config/wireshark/extcap/blehound_extcap.py

Then restart Wireshark and "BLEhound Sniffer" will appear in the interface list.

Dependency: pyserial (pip3 install pyserial).
"""

import argparse
import os
import queue
import struct
import sys
import threading
import time

try:
    import serial
    import serial.tools.list_ports
except ImportError:  # pragma: no cover - only triggered when the dependency is missing
    sys.stderr.write("pyserial is missing; run first: pip3 install pyserial\n")
    sys.exit(1)

# Three-way aggregation logic (SyncClock/Aggregator). Lives next to this script; the cwd is
# unpredictable when Wireshark calls us, so add the script directory to sys.path before importing.
sys.path.insert(0, os.path.dirname(os.path.abspath(__file__)))
from blehound_tri_aggregator import Aggregator, FollowRelay, guard_channel_for_board   # noqa: E402

# The value for the aggregated interface — distinct from the per-serial-device paths
TRI_AGGREGATED_IFACE = "tri-aggregated"


# The USB identity the firmware declares in prj.conf
SNIFFER_VID = 0x1915
SNIFFER_PID = 0x520F
SNIFFER_PRODUCT = "BLEhound Sniffer"

# ---- Keep in sync with the firmware's host_iface.h ----
HOST_FRAME_PACKET = 0x01
HOST_CMD_SET_CHANNEL = 0x81
HOST_CMD_SET_TARGET = 0x84
HOST_CMD_SET_HOPPING = 0x85
HOST_CMD_SET_SINGLE_TARGET = 0x87   # 1 byte: 1=single-target mode (default), 0=multi-target evaluation mode
HOST_CMD_FOLLOW = 0x86
FRAME_HEADER_LEN = 17
FLAG_CRC_OK = 1 << 0
HOST_FLAG_TRI = 1 << 3       # tri-board mode: 5 extra bytes after the fixed header (board_id + sync_epoch)
TRI_EXT_LEN = 5

# PCAP: LINKTYPE_BLUETOOTH_LE_LL_WITH_PHDR
DLT_BLUETOOTH_LE_LL_WITH_PHDR = 256

# flags bits of the BTLE_RF pseudo-header (see Wireshark packet-btle.c)
RF_FLAG_DEWHITENED = 0x0001
RF_FLAG_SIGNAL_VALID = 0x0002
RF_FLAG_REF_AA_VALID = 0x0010
RF_FLAG_CRC_CHECKED = 0x0400
RF_FLAG_CRC_VALID = 0x0800

ADV_CHANNELS = [37, 38, 39]
DEFAULT_CHANNEL = 37

# Primary-channel legacy advertising PDU types (low 4 bits of the header). AdvA is at payload offset 0 (pdu[2:8]).
ADV_IND = 0x0             # connectable scannable undirected
ADV_DIRECT_IND = 0x1     # connectable directed
ADV_NONCONN_IND = 0x2    # non-connectable non-scannable
SCAN_RSP = 0x4           # scan response (often carries the name)
ADV_SCAN_IND = 0x6       # scannable non-connectable
ADV_EXT_IND = 0x7        # extended advertising: AdvA lives in the ext header, not parsed by the scan
# Types whose payload starts with a 6-byte AdvA, usable for device discovery
_ADV_WITH_ADVA = frozenset({ADV_IND, ADV_DIRECT_IND, ADV_NONCONN_IND, SCAN_RSP, ADV_SCAN_IND})
# Types that carry AdvData (may contain a local name); ADV_DIRECT_IND only has TargetA, no AdvData
_ADV_WITH_DATA = frozenset({ADV_IND, ADV_NONCONN_IND, ADV_SCAN_IND, SCAN_RSP})
ADV_PDU_TYPE_MASK = 0x0F
ADV_TXADD_RANDOM = 0x40  # header bit6: TxAdd, set = random address
SCAN_DEFAULT_SECS = 4.0  # how long one reload scan runs


# ------------------------------------------------------------------ COBS

def cobs_decode(data: bytes) -> bytes:
    """COBS decode. Mirrors the firmware's cobs.c; returns empty on invalid input."""
    out = bytearray()
    i = 0
    n = len(data)

    while i < n:
        code = data[i]
        if code == 0:
            return b""      # a 0 must never appear inside the encoded stream
        i += 1

        end = i + code - 1
        if end > n:
            return b""      # data was truncated
        out += data[i:end]
        i = end

        if code != 0xFF and i < n:
            out.append(0)

    return bytes(out)


# ------------------------------------------------------------------ PCAP

def pcap_global_header() -> bytes:
    return struct.pack(
        "<IHHiIII",
        0xA1B2C3D4,     # magic
        2, 4,           # version
        0,              # timezone
        0,              # timestamp accuracy
        65535,          # snaplen
        DLT_BLUETOOTH_LE_LL_WITH_PHDR,
    )


def pcap_record(ts_epoch_us: int, payload: bytes) -> bytes:
    header = struct.pack("<IIII", ts_epoch_us // 1_000_000, ts_epoch_us % 1_000_000,
                         len(payload), len(payload))
    return header + payload


class TimestampMapper:
    """Maps the firmware's µs counter onto host wall-clock time.

    The firmware counter starts at power-on, so using it directly as the PCAP timestamp
    would show up as 1970 in Wireshark. Here we reconstruct real time as
    "capture-start instant + relative offset", giving both the correct date and the
    firmware's µs-level precision (host-side serial-read jitter is at the millisecond
    level, unsuitable to use directly as the packet arrival time).

    The counter is 32-bit, 1MHz, wrapping roughly every 71.6 minutes, so we accumulate
    the wrap count.
    """

    WRAP = 1 << 32

    def __init__(self, host_epoch_us: int):
        self._host_epoch_us = host_epoch_us
        self._first_fw_us = None
        self._prev_fw_us = 0
        self._wraps = 0

    def to_epoch_us(self, fw_us: int) -> int:
        if self._first_fw_us is None:
            self._first_fw_us = fw_us
            self._prev_fw_us = fw_us

        # a timestamp going backwards can only be a counter wrap (packets are processed in order)
        if fw_us < self._prev_fw_us:
            self._wraps += 1
        self._prev_fw_us = fw_us

        elapsed = fw_us + self._wraps * self.WRAP - self._first_fw_us
        return self._host_epoch_us + elapsed

    def to_epoch_us_mono(self, mono_us: int) -> int:
        """Aggregated path: the input is the aggregator's monotonic 64-bit tick with wraps already
        unrolled (key64); do only a linear mapping and **no longer guess wraps**.
        The aggregated output occasionally has late packets beyond the reorder window (a tick slightly
        earlier than the previous one) — that is real time, not a wrap; using to_epoch_us would treat
        every step-back as a wrap and add 4295s (the cause of the aggregated-pcap timestamp jumps on real
        hardware on 2026-09-19)."""
        if self._first_fw_us is None:
            self._first_fw_us = mono_us
        return self._host_epoch_us + (mono_us - self._first_fw_us)
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

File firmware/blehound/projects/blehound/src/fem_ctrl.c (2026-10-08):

/* SPDX-License-Identifier: Apache-2.0 */
/*
 * nRF21540 FEM pure-GPIO control implementation -- see fem_ctrl.h (includes the P0.09 rules, must read before changing).
 */

#include <zephyr/kernel.h>
#include <zephyr/drivers/gpio.h>
#include <zephyr/logging/log.h>

#include "fem_ctrl.h"

LOG_MODULE_REGISTER(fem_ctrl, LOG_LEVEL_INF);

/* nRF21540 PS v1.0 Table 6 settling times (µs), matching the defaults of the zephyr nordic,nrf21540-fem binding.
 * TX is set to 26 = 11 (PG→TX) + margin for the SoC RF power ramp-up. */
#define FEM_PDN_SETTLE_US 18 /* PD → PG */
#define FEM_RX_SETTLE_US  11 /* PG → RX */
#define FEM_TX_SETTLE_US  26 /* PG → TX */
#define FEM_TRX_HOLD_US    3 /* RX/TX → PG */

#define FEM_PDN_NODE    DT_ALIAS(fem_pdn)
#define FEM_RXEN_NODE   DT_ALIAS(fem_rxen)
#define FEM_TXEN_NODE   DT_ALIAS(fem_txen)
#define FEM_ANTSEL_NODE DT_ALIAS(fem_antsel)
#define FEM_MODE_NODE   DT_ALIAS(fem_mode)
#define FEM_CSN_NODE    DT_ALIAS(fem_csn)
#define FEM_SCK_NODE    DT_ALIAS(fem_sck)
#define FEM_MOSI_NODE   DT_ALIAS(fem_mosi)

#if DT_NODE_EXISTS(FEM_PDN_NODE) && DT_NODE_EXISTS(FEM_RXEN_NODE) && \
	DT_NODE_EXISTS(FEM_TXEN_NODE) && DT_NODE_EXISTS(FEM_ANTSEL_NODE) && \
	DT_NODE_EXISTS(FEM_MODE_NODE) && DT_NODE_EXISTS(FEM_CSN_NODE) && \
	DT_NODE_EXISTS(FEM_SCK_NODE) && DT_NODE_EXISTS(FEM_MOSI_NODE)
#define FEM_PRESENT 1
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

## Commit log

2026-09-22 feat: import BLEhound project (firmware, hardware, host tools, docs)
    [PickAndPlace_BLEhound_2026_09_08.xlsx, blehound.kicad_pcb, blehound.kicad_sch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]
2026-09-22 docs: README hero GIF + AI-built note; add exploded-case GIF and English V1 flywire diagrams
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2026-09-23 chore(case): re-export models, re-slice prints, refresh previews
    [blehound_case_P2S_PETG_0.2mm.gcode.3mf, blehound_case_P2S_PLA_0.2mm.gcode.3mf, blehound_lid.3mf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]
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2026-09-25 feat(host): scan-to-pick target dropdown in extcap (RPA-friendly)
    - New "Scan for a target" dropdown: opening the interface options auto-scans
    nearby advertisers and prefills it; the reload circle rescans
    - Lists connectable devices only, strongest 60 by RSSI, showing
    name / address / RSSI / address type (RPA / static / public)
    - Dropdown pick wins over the manual MAC; parses legacy AdvA and
    Complete/Shortened Local Name
    - Rename interface display names to "BLEhound Sniffer"
    [nrf_sniffer_extcap.py]
2026-09-25 refactor: rename host scripts to blehound_* and USB product to "BLEhound Sniffer"
    - host/nrf_sniffer_extcap.{py,bat} -> host/blehound_extcap.{py,bat}
    - host/tri_aggregator.py -> host/blehound_tri_aggregator.py
    - update every reference (imports, install_extcap.sh, CI workflow, READMEs, comments)
    - install_extcap.sh removes copies left under the old names so Wireshark does not list the plugin twice
    - firmware: CONFIG_*_PRODUCT "nRF BLE Sniffer" -> "BLEhound Sniffer" on all three board confs,
    so the device enumerates as "BLEhound | BLEhound Sniffer"; main.c banner/log follow
    - tools/cdc_test.sh: match the new product name; also fix the silent exit on macOS
    (awk exiting on first match SIGPIP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
    [blehound_extcap.py, blehound_tri_aggregator.py, main.c]
2026-09-25 refactor(firmware): drop the nRF52840 DK/Dongle build targets
    The only supported target is the BLEhound board (nrf54lm20dk/nrf54lm20a/cpuapp
    + boards/blehound.{conf,overlay}). Remove the two nRF52840 board confs and every
    path that still pointed at them:
    - delete boards/nrf52840dk_nrf52840.conf and boards/nrf52840dongle_nrf52840.conf
    - tools/build.sh: remove the BLEHOUND=0 legacy branch; board is fixed to nrf54lm20dk
    - CI: drop the nRF52840 build step
    - firmware READMEs: remove the nRF52840 build examples
    - prj.conf / app.overlay / cdc_test.sh / flash.sh comments: no longer describe nRF52 USB
    - README / CONTRIBUTING: stop advertising nRF52840 as a supported board
    radio_nrf52.c and the per-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
2026-09-25 refactor(firmware): add the out-of-tree board "blehound/nrf54lm20a/cpuapp"
    The firmware no longer builds against the Zephyr nrf54lm20dk board target.
    firmware/boards/blehound/ now carries the board definition (board.yml, Kconfig,
    DTS, pinctrl, defconfig), derived from zephyr/boards/nordic/nrf54lm20dk and kept
    functionally identical so the migration does not change the firmware:
    .config differs only in the BOARD_* symbols and the generated zephyr.dts only
    in the root compatible/model strings; FLASH/RAM usage is unchanged.
    - board target: blehound/nrf54lm20a/cpuapp; the firmware dir is passed as
    BOARD_ROOT (build.sh, CI, README commands use -DBOARD_ROOT=.)
    - app-level board files renamed: n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
2026-09-25 refactor(firmware): one board definition per PCB revision (blehound_v1 / blehound_v2)
    Follow the one-directory-per-hardware-revision layout: firmware/boards/blehound_v1
    (first-batch board, 0908) and firmware/boards/blehound_v2 (revised board) are complete
    Zephyr board definitions, with everything the two revisions share in
    firmware/boards/common/blehound_nrf54lm20a_cpuapp_common.dtsi.
    - hardware truth moves into the board definition: strap / SYNC / inter-board CS+REQ
    lines, ACT LED and the aliases in the common dtsi; inter-board SPIM00 pinctrl and
    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
2026-09-25 feat(firmware): follow policy "no target = observe only, target set = follow only it"
    Previously single-target mode followed the first connection it saw even with no target set,
    so the sniffer ran off after someone else's connection before the user had picked a target.
    - new follow_policy.h (pure functions): in single-target mode a target MAC must be set, the
    CONNECT_IND's AdvA must equal it and no other connection may be followed; no target = pure
    scanning so the host can list advertisers first. Multi-target evaluation mode follows
    everything (only the target if one is set). Host-relayed FOLLOW only checks mode and whether
    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
2026-09-26 feat(firmware): IRK-based RPA resolution, status query frame and firmware version
    Synced from the internal repo (code identical, comments in English).
    - rpa_resolve.h + ble_aes128.{c,h}: given the target's IRK (HOST_CMD_SET_IRK, over-the-air /
    SMP order), ah() recognises the target's new resolvable private addresses and the firmware
    switches the target MAC to them automatically, so a privacy device that rotates its RPA is not
    lost. The RX interrupt only consults a small cache; AES runs in the capture thread.
    - adv_filter.h: split out adv_pdu_adva() (which AdvA a PDU is about); adv_pdu_matches_target()
    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
2026-09-26 feat(firmware): key hints, unmapped-channel guard, SYNC heartbeat frame, packet direction
    - Key hint (HOST_CMD_LL_CTRL_HINT 0x8A): the host decrypts encrypted LL control PDUs with the
    LTK and relays them; the follower registers them on the slot like plaintext, so channel-map /
    connection-parameter / PHY updates still switch at the instant after encryption. A hint that
    arrives after the instant is compensated (late events at the new interval).
    - Unmapped-channel guard: after LL_ENC_REQ the channel map is untrusted; each event guards the
    CSA#2 unmapped channel (full 37-channel map) so a hidden map change cannot lose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
2026-09-26 feat(firmware): plan A inter-board SPI handoff -- the board that catches CONNECT_IND pushes the connection parameters to the other two
    - peer_link: bit-banged master port (on the nRF54LM20A SPIM00 only outputs SCK on the dedicated clock pin P2.01, the V1 board wires it to P2.02), nrfx_spis slave port on spi21, REQ_in read moved to a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
    - P1.01/P1.02 are the NFC1/NFC2 pads and need nfct-pins-as-gpios to work as GPIO; lfxo internal load caps disabled (the LM20 XL pads are P1.20/P1.21)
    - peer_msg: HANDOFF now carries the event0 anchor as an offset from the hit SYNC edge plus the send age, patched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
2026-09-27 feat(firmware): USB DFU -- MCUboot firmware-loader single-slot mode, button-less entry via 0x8B, fixed-name outputs
    - sysbuild with three images: MCUboot (24K@0) + Nordic usb_mcumgr firmware loader (116K@0x6000, USB PID 0x5210
    "BLEhound Loader") + signed app (1880K@0x23000) + 16K storage; partition table in the board file
    boards/common/blehound_partitions.dtsi; ed25519 pure signature, public key compiled into MCUboot, no KMU
    - new command HOST_CMD_ENTER_DFU (0x8B): the app writes the boot mode (gpregret1) and resets, MCUboot boots the
    loader; with no bootable app the loader is kept (no bricking)
    - MCUboot disables CRACEN_LIB_KMU: otherwise cracen_init pushes unprovisioned KMU slots 248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
    [main.c]
2026-09-27 feat(firmware): own DFU signing key + dfu.sh detects boards already in the loader
    - tools/keygen.sh: create the ed25519 signing key outside the repo (~/.blehound/keys/, never committed)
    and export the public key to firmware/keys/blehound_ed25519.pub.pem; tools/build.sh passes the private
    key via SB_CONFIG_BOOT_SIGNATURE_KEY_FILE when present, else falls back to MCUboot's dev key and warns
    - verified on three boards: MCUboot rejects an image signed with the dev key and stays in the loader
    - tools/dfu.sh: probe over SMP first so a board already in the loader gets no capture commands
    - README: signing key, the Analyzer's built-in update flow
2026-10-08 chore: add SPDX-Apache-2.0 headers; drop not-verified-on-hardware caveats
    - 给 firmware/src 的 36 个 C/H 与 host 的 4 个 Python 源文件补上
    SPDX-License-Identifier: Apache-2.0 头
    - radio_nrf54l.c / conn_follower.c / fem_ctrl.c：清除"未在硬件验证 /
    待硬件确认"等警示注释（相关功能已在硬件上验证），保留功能说明
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2026-10-09 fix(firmware): asymmetric Coded-link capture (fast ramp-up + preamble-aware window lead)
    - radio_nrf54l.c: enable fast ramp-up (RADIO.TIMING.RU). The Legacy ~140µs ramp
    overran the 150µs T_IFS turnaround on the slave direction of an asymmetric
    Coded->1M link, dropping every slave 1M packet.
    - conn_follower.c: add the master-direction PHY's preamble+AA airtime to the RX
    window lead time. Coded's ~376µs preamble+AA was opening the window after the
    preamble, so the radio missed it and lost the anchor.
    [radio_nrf54l.c]
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2026-10-10 fix(firmware): single-target reconnect gaps, establishment failure, encrypted channel map, packet direction, radio RX recovery
    Port the follower/radio fixes from the development tree.
    - Single-target reconnect: release the stale ACL slot the moment the target's own
    CONNECT_IND, connectable advertising (ADV_IND/ADV_DIRECT_IND), or an inter-board
    inject is seen, instead of waiting for supervision timeout (an encrypted link shows
    no TERMINATE). During event gaps single-target mode now returns to the guard channel
    (was MODE_IDLE/stop-receive), and in the relock state yields every other interval
    back to guarding, so the target's reconnect CONNECT_IND isn't missed.
    - Establishment failu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
    [main.c, radio_hal.h]
